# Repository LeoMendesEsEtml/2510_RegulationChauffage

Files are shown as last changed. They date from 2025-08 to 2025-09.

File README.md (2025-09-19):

# 2510_RegulationChauffage

## Description
Solution matérielle et logicielle basée sur Raspberry Pi Compute Module 5 pour remplacer un automate de chaudière.  
Le système lit des sondes réelles, calcule une température « simulée » à partir des prévisions météo, et applique une résistance équivalente à la chaudière via un réseau de résistances commandé. Connexion à l'API Oblo en HTTP (GET/POST) et publication des **mesures** & de l'**état** vers un Cloud, conformément au CdC.

**Documentation complète disponible sur : [leomendesesetml.github.io/2510_RegulationChauffage.github.io](https://leomendesesetml.github.io/2510_RegulationChauffage.github.io/index.html)**

## Diagrammes (UML / Architecture / Flux)
| Architecture réelle | Architecture générique |
|---|---|
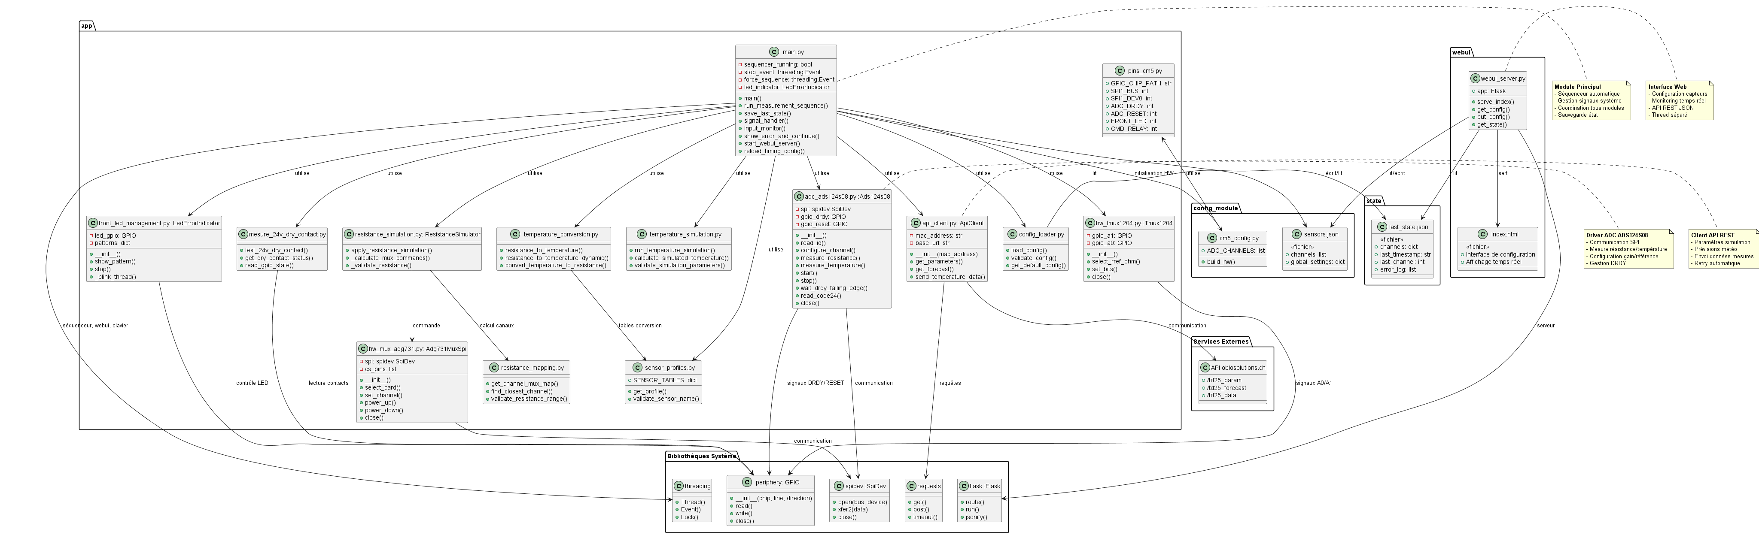
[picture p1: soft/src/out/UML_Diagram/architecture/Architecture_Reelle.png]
Architecture réelle
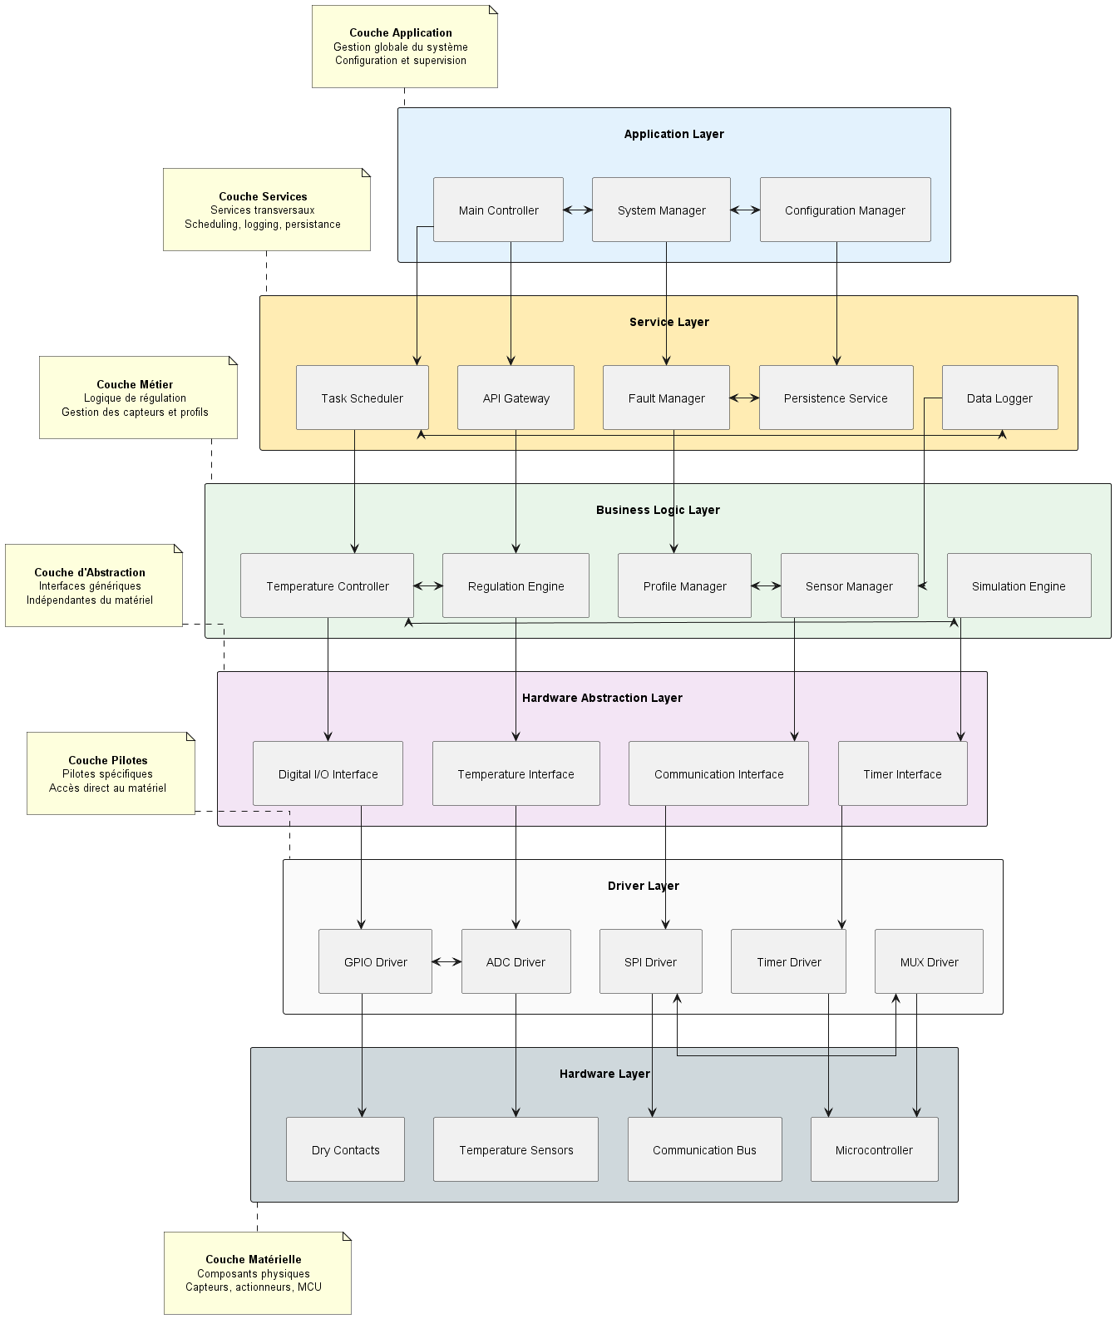
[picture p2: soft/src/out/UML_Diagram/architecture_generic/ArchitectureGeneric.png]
Architecture générique
|  |  |

| Flux d’événements détaillé | Flux d’événements générique |
|---|---|
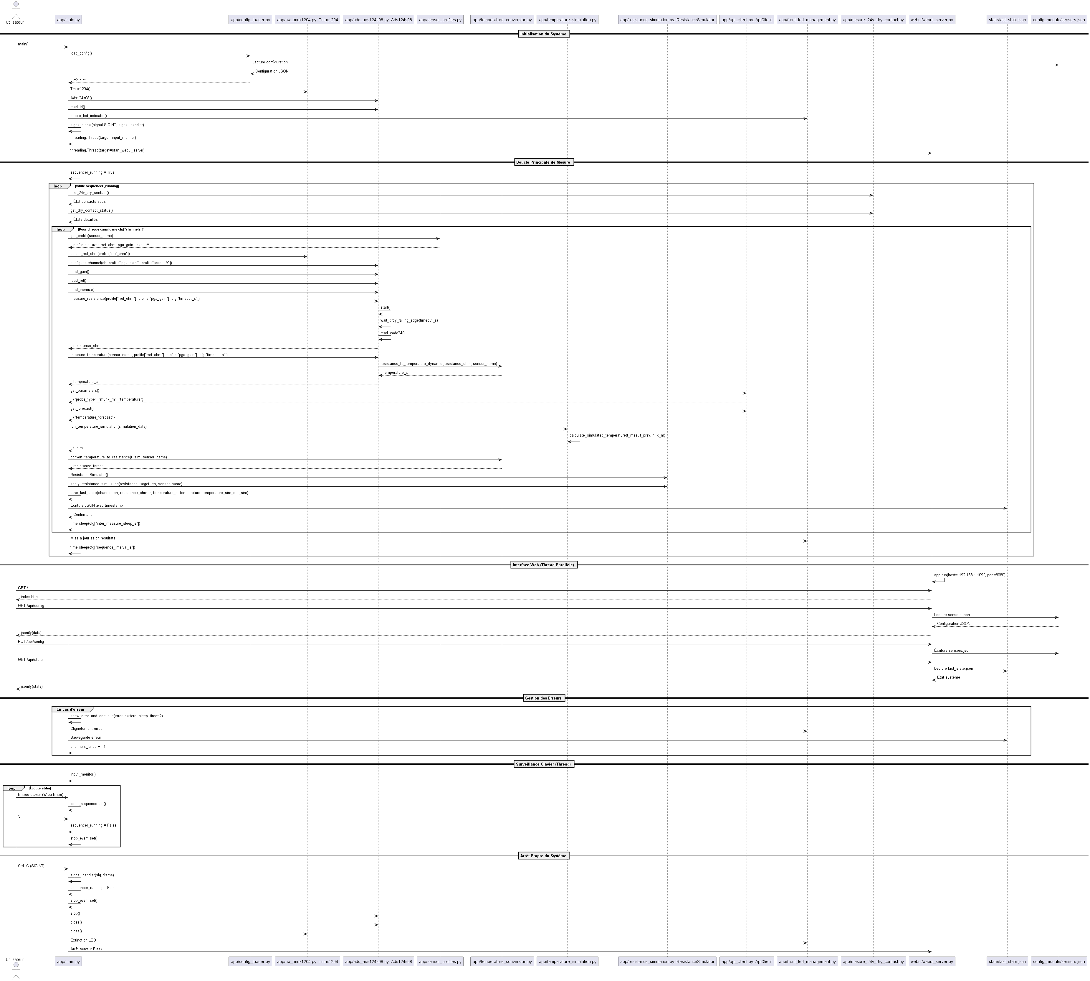
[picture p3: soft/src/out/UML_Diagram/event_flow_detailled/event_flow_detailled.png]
Flux d’événements détaillé
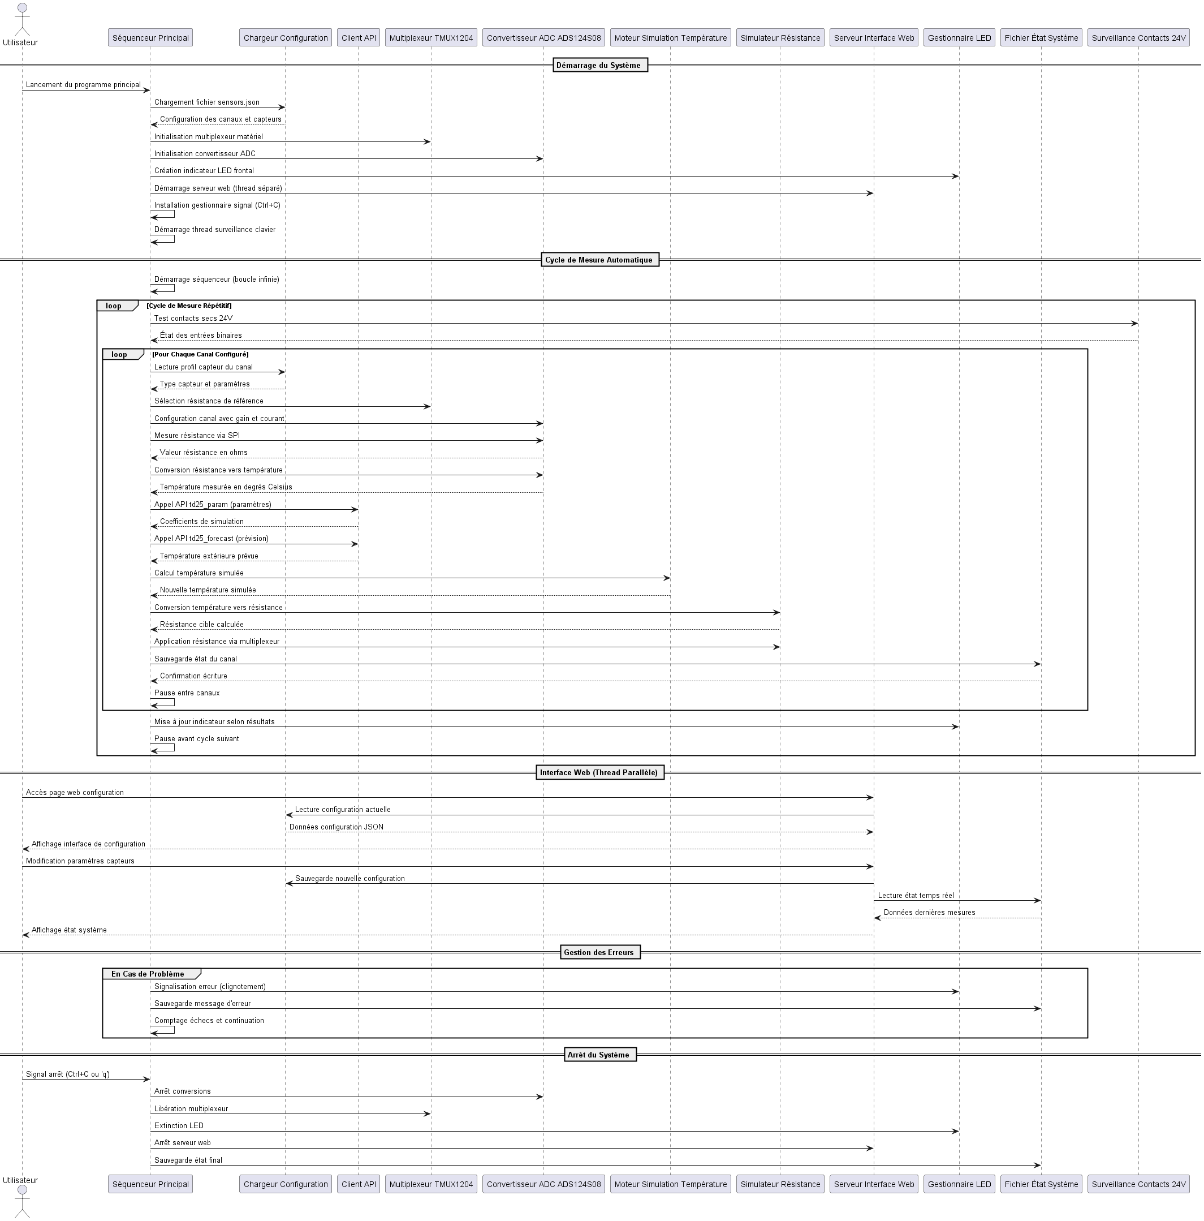
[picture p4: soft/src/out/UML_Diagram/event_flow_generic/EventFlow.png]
Flux d’événements générique
|  |  |

## Fonctionnalités (réf. CdC v02)
- Récupération des paramètres et prévisions via **API HTTP** (Oblo, GET/POST).
- Lecture d'une sonde de température extérieure (capteur **résistif**), conversion en **°C**.
- Génération d'une **sonde simulée** via réseau de résistances (pilotage **ADG731**).
- **Publication** des mesures et de l'état de l'appareil vers le **Cloud**.
- Cadence périodique **5 minutes**, journalisation en **JSON lines**.
- Gestion de **1 à 4** canaux actifs, contact sec prioritaire, relais bypass et LED d'état.

## Architecture système

### Matériel principal
- **Compute Module 5 (CM5)** - Processeur principal
- **ADS124S08** - ADC delta-sigma, communication **SPI1**, signaux DRDY/START en GPIO
- **TMUX1204** - Multiplexeur sélection **Rref** (A0/A1)
- **ADG731** - Multiplexeur **SPI0** vers réseau de **résistances simulées**
- **Entrée contact sec**, **relais bypass**, **LED** frontale

### Logiciel principal
- **Python 3.11+** avec architecture modulaire
- **spidev**, **periphery** (SPI/GPIO), **requests** (HTTP), **flask** (WebUI)
- Interface web intégrée pour configuration et monitoring
- Service **systemd** et logs JSON rotatifs
- Simulation et validation complète des mesures

## Commandes principales

### Lancement manuel
```bash
# Mode automatique avec cycles 5 minutes
python3 /home/oblo/proj/2510_RegulationChauffage_soft/soft/src/app/main.py

# Mode manuel avec interface web
python3 /home/oblo/proj/2510_RegulationChauffage_soft/soft/src/app/main.py --webui

# Mode manuel sans cycles automatiques
python3 /home/oblo/proj/2510_RegulationChauffage_soft/soft/src/app/main.py --manual

# Exécution unique (test)
python3 /home/oblo/proj/2510_RegulationChauffage_soft/soft/src/app/main.py --once
```

### Service systemd (production)
```bash
# Créer le service avec interface web
sudo tee /etc/systemd/system/2510-regulation.service > /dev/null << 'EOF'
[Unit]
Description=2510 Regulation Chauffage Service with WebUI
After=network.target
Wants=network.target

[Service]
Type=simple
User=oblo
Group=oblo
WorkingDirectory=/home/oblo/proj/2510_RegulationChauffage_soft/soft/src
ExecStart=/usr/bin/python3 /home/oblo/proj/2510_RegulationChauffage_soft/soft/src/app/main.py --webui
Restart=always
RestartSec=10
StandardOutput=journal
StandardError=journal
Environment=PYTHONPATH=/home/oblo/proj/2510_RegulationChauffage_soft/soft/src
Environment=HOME=/home/oblo

[Install]
WantedBy=multi-user.target
EOF

# Activer et démarrer le service
sudo systemctl daemon-reload
sudo systemctl enable 2510-regulation
sudo systemctl start 2510-regulation
```

### Contrôle du service
```bash
# Vérifier le statut du service
sudo systemctl status 2510-regulation

# Vérifier si le service est actif
sudo systemctl is-active 2510-regulation

# Arrêter le service
sudo systemctl stop 2510-regulation

# Redémarrer le service
sudo systemctl restart 2510-regulation

# Voir les logs en temps réel
sudo journalctl -u 2510-regulation -f

# Voir les derniers logs
sudo journalctl -u 2510-regulation -n 50
```

### Monitoring et diagnostic
```bash
# Vérifier le processus Python
ps aux | grep main.py

# Vérifier l'interface web (port 8080)
curl -s http://localhost:8080 > /dev/null && echo "Interface web active" || echo "Interface web inaccessible"

# Vérifier les ports d'écoute
sudo ss -tlnp | grep 8080

# Status complet en une commande
echo "Service:" && sudo systemctl is-active 2510-regulation && echo "Process:" && ps aux | grep -v grep | grep main.py && echo "Port 8080:" && sudo ss -tlnp | grep 8080
```

## Installation et déploiement

### Installation système
```bash
# Dépendances système
sudo apt update
sudo apt install python3-pip python3-venv

# Dépendances Python
pip3 install spidev periphery requests flask

# Configuration SPI
sudo raspi-config  # Activer SPI0 et SPI1
```

### Accès interface web
- **URL locale** : `http://192.168.1.109:8080`
- **Configuration** : Types capteurs, timeouts, intervalles
- **Monitoring** : Données temps réel, historique des mesures
- **API REST** : `/api/config`, `/api/state`

## Flux opératoire (cycle 5 min)

### Séquence de mesure
1. **Contacts secs** - Lecture état prioritaire via mesure_24v_dry_contact.py
2. **Pour chaque canal actif (1-4)** :
   - Sélection **Rref** via TMUX1204
   - Configuration **ADC** via ADS124S08
   - **Mesure single-shot** → code 24 bits → **Tmes**
   - Conversion résistance/température

### Simulation et application
3. **API Oblo** - Récupération paramètres (**N, kM, Tprevu**)
4. **Calcul Tsim** - Formule prédictive temperature_simulation.py
5. **Application MUX** - Résistance simulée via ADG731
6. **Sauvegarde** - État système dans last_state.json

### Gestion d'erreurs
- **LED frontale** - Patterns d'erreur (1Hz normal, 2Hz faute)
- **Relais bypass** - Sécurité en cas de défaut
- **Logs JSON** - Traçabilité complète des événements

## Types de capteurs supportés
- **De Dietrich AF60**, **Siemens QAC32**
- **PT1000**, **Ni1000 TK5000/TK6180**
- **NTC 1k/2k/2.2k/10k** (diverses courbes)
- **KTY81-210**

## API et connectivité

### API oblosolutions.ch
- **Endpoint paramètres** : `GET /td25_param?mac_address=XXX`
- **Endpoint prévisions** : `GET /td25_forecast?mac_address=XXX`
- **Envoi mesures** : `POST /td25_param` avec données température

### Données JSON échangées
```json
{
  "probe_type": "Ni1000 TK5000",
  "n": 0.8,
  "k_m": -0.1,
  "temperature": 18.5,
  "forecast_temperature": 15.2,
  "timestamp": "2025-09-18T14:30:00Z"
}
```

### Configuration réseau
- **Interface** : eth0 (192.168.1.109)
- **Port web** : 8080
- **Timeout API** : 10 secondes
- **Retry** : 3 tentatives

## Mappage matériel CM5

### Configuration SPI
- **SPI0** → **ADG731** (réseau résistif) : SCLK, MOSI, CS[0..3]
- **SPI1** → **ADS124S08** (métrologie) : SCLK, MOSI, MISO, CS

### Table GPIO principale
| Signal | GPIO | Fonction | Description |
|---|:----:|---|---|
| **MUX CS 1-4** | 2,3,7,8 | Sélection carte ADG731 | Adressage résistances |
| **MUX MOSI/SCLK** | 10,11 | Communication SPI0 | Commande multiplexeur |
| **CM 24V OUT/SENSE** | 12-15 | Contacts secs | Entrées prioritaires |
| **ADC SPI1** | 17-20 | Communication ADC | Mesures température |
| **ADC DRDY/START** | 21,22 | Signaux contrôle ADC | Synchronisation mesures |
| **ADC A0/A1** | 23,24 | Sélection canal/Rref | Multiplexage entrées |
| **FRONT LED** | 26 | Indicateur état | Status visuel système |
| **CMD RELAY** | 16 | Relais bypass | Sécurité défaillance |

## Fichiers de configuration et état

### Fichiers système
```bash
# Configuration capteurs
/home/oblo/proj/2510_RegulationChauffage_soft/soft/src/config_module/sensors.json

# État système (dernières mesures)
/home/oblo/proj/2510_RegulationChauffage_soft/soft/src/state/last_state.json

# Logs système
sudo journalctl -u 2510-regulation

# Configuration service
/etc/systemd/system/2510-regulation.service
```

### Monitoring système
#### Patterns d'erreur : X clignotements sur 10 secondes puis répétition
- 1 clignotement = Pas de connexion Internet
- 2 clignotements = Erreur API (connexion ou réponse)
- 3 clignotements = Erreur de mesure ADC/résistance
- 4 clignotements = Erreur critique système
- 5 clignotements = Erreur de configuration
#### Interface web :
- Dashboard temps réel à `http://192.168.1.109:8080`

## Validation et diagnostics
### Troubleshooting
```bash
# Vérifier SPI activé
ls /dev/spi*

# Vérifier permissions GPIO
groups oblo

# Redémarrer service en cas de problème
sudo systemctl restart 2510-regulation

# Logs détaillés
sudo journalctl -u 2510-regulation --since "1 hour ago"
```

---

## Références et documentation

- **Documentation technique complète** : [leomendesesetml.github.io/2510_RegulationChauffage.github.io](https://leomendesesetml.github.io/2510_RegulationChauffage.github.io/index.html)
- **Cahier des charges** : Exigences fonctionnelles et techniques
- **Schémas électroniques** : Plans de câblage et BOM
- **API Documentation** : Spécifications oblosolutions.ch
- **Code source** : Modules Python avec documentation inline

## Informations projet

**Auteur** : Léo Mendes - ETML ES  
**Projet** : 2510_RegulationsChauffage  
**Mandant** : Oblo Solutions  
**Version** : 1.0.0  
**Chemin système** : `/home/oblo/proj/2510_RegulationChauffage_soft/soft/src/`  
**Copyright** : 2025

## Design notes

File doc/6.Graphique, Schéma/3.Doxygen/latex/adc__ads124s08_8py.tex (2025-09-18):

\doxysection{Référence du fichier C\+:/\+Users/thebi/\+Documents/2510\+\_\+\+Regulation\+Chauffage/doc/9.Soft\+Ware/\+Doxygen/src/app/adc\+\_\+ads124s08.py}
\hypertarget{adc__ads124s08_8py}{}\label{adc__ads124s08_8py}\index{C:/Users/thebi/Documents/2510\_RegulationChauffage/doc/9.SoftWare/Doxygen/src/app/adc\_ads124s08.py@{C:/Users/thebi/Documents/2510\_RegulationChauffage/doc/9.SoftWare/Doxygen/src/app/adc\_ads124s08.py}}

Driver pour l\textquotesingle{}ADC ADS124\+S08 avec communication SPI.  

\doxysubsubsection*{Classes}
\begin{DoxyCompactItemize}
\item 
class \mbox{\hyperlink{classapp_1_1adc__ads124s08_1_1_ads124s08}{app.\+adc\+\_\+ads124s08.\+Ads124s08}}
\begin{DoxyCompactList}\small\item\em Driver pour l\textquotesingle{}ADC ADS124\+S08 avec interface SPI. \end{DoxyCompactList}\end{DoxyCompactItemize}
\doxysubsubsection*{Espaces de nommage}
\begin{DoxyCompactItemize}
\item 
namespace \mbox{\hyperlink{namespaceapp}{app}}
\item 
namespace \mbox{\hyperlink{namespaceapp_1_1adc__ads124s08}{app.\+adc\+\_\+ads124s08}}
\end{DoxyCompactItemize}
\doxysubsubsection*{Fonctions}
\begin{DoxyCompactItemize}
\item 
\mbox{\hyperlink{namespaceapp_1_1adc__ads124s08_a0117399a18d516c747ca6b060599452f}{app.\+adc\+\_\+ads124s08.\+encode\+\_\+gain}} (pga\+\_\+gain)
\begin{DoxyCompactList}\small\item\em Encode le gain PGA en code binaire pour le registre. \end{DoxyCompactList}\item 
\mbox{\hyperlink{namespaceapp_1_1adc__ads124s08_a8f9279b8505f8d634ed73c51dcab29c9}{app.\+adc\+\_\+ads124s08.\+encode\+\_\+idac\+\_\+uA}} (idac\+\_\+uA)
\begin{DoxyCompactList}\small\item\em Encode la magnitude IDAC en code binaire pour le registre. \end{DoxyCompactList}\item 
\mbox{\hyperlink{namespaceapp_1_1adc__ads124s08_a2d49f7c13e0b47db65080ab59febed76}{app.\+adc\+\_\+ads124s08.\+sign\+\_\+extend\+\_\+24}} (b0, b1, b2)
\begin{DoxyCompactList}\small\item\em Étend le signe d\textquotesingle{}un code ADC 24 bits vers 32 bits. \end{DoxyCompactList}\end{DoxyCompactItemize}
\doxysubsubsection*{Variables}
\begin{DoxyCompactItemize}
\item 
int \mbox{\hyperlink{namespaceapp_1_1adc__ads124s08_a95d2ed0295f793db669188acfc42e035}{app.\+adc\+\_\+ads124s08.\+REG\+\_\+\+ID}} = 0x00
\item 
int \mbox{\hyperlink{namespaceapp_1_1adc__ads124s08_a08370a57876abbb36233f903990f7090}{app.\+adc\+\_\+ads124s08.\+REG\+\_\+\+STATUS}} = 0x01
\item 
int \mbox{\hyperlink{namespaceapp_1_1adc__ads124s08_acc5fdb3a177b32ce008beb7d4f593e5a}{app.\+adc\+\_\+ads124s08.\+REG\+\_\+\+INPMUX}} = 0x02
\item 
int \mbox{\hyperlink{namespaceapp_1_1adc__ads124s08_a6693b8b3c92c4e605cd93396bbf437e4}{app.\+adc\+\_\+ads124s08.\+REG\+\_\+\+PGA}} = 0x03
\item 
int \mbox{\hyperlink{namespaceapp_1_1adc__ads124s08_a3570ad44d2f9dd31da3eb36e6bb43a74}{app.\+adc\+\_\+ads124s08.\+REG\+\_\+\+DATARATE}} = 0x04
\item 
int \mbox{\hyperlink{namespaceapp_1_1adc__ads124s08_a37082f74d6a0e13791161957521dda36}{app.\+adc\+\_\+ads124s08.\+REG\+\_\+\+REF}} = 0x05
\item 
int \mbox{\hyperlink{namespaceapp_1_1adc__ads124s08_ad6a2ed950510eefbb3d8e16c5d44aa9a}{app.\+adc\+\_\+ads124s08.\+REG\+\_\+\+IDACMUX}} = 0x07
\item 
int \mbox{\hyperlink{namespaceapp_1_1adc__ads124s08_ab33f3d3b9eff07796c0954fb0a26a0f9}{app.\+adc\+\_\+ads124s08.\+REG\+\_\+\+SYS}} = 0x09
\item 
int \mbox{\hyperlink{namespaceapp_1_1adc__ads124s08_a29344761380eb9759a168a517077c1f8}{app.\+adc\+\_\+ads124s08.\+REG\+\_\+\+IDACMAG}} = 0x06
\item 
int \mbox{\hyperlink{namespaceapp_1_1adc__ads124s08_ac53df39aab8783f89db1de629453dac2}{app.\+adc\+\_\+ads124s08.\+CMD\+\_\+\+RESET}} = 0x06
\item 
int \mbox{\hyperlink{namespaceapp_1_1adc__ads124s08_afdbb53f6073883d5fae13b41f4054ad2}{app.\+adc\+\_\+ads124s08.\+CMD\+\_\+\+START}} = 0x08
\item 
int \mbox{\hyperlink{namespaceapp_1_1adc__ads124s08_a584dd419d6c692fe7fdbf9c318b0e9da}{app.\+adc\+\_\+ads124s08.\+CMD\+\_\+\+STOP}} = 0x0A
\item 
int \mbox{\hyperlink{namespaceapp_1_1adc__ads124s08_a295dbc291719574e76ddc5a7a2467087}{app.\+adc\+\_\+ads124s08.\+CMD\+\_\+\+RDATA}} = 0x12
\item 
tuple \mbox{\hyperlink{namespaceapp_1_1adc__ads124s08_a9d806c5f058f08f8ee7e226d706694f1}{app.\+adc\+\_\+ads124s08.\+FS}} = (1 $<$$<$ 23) -\/ 1
\item 
dict \mbox{\hyperlink{namespaceapp_1_1adc__ads124s08_a8919c033b020e8f54f713cea9d68fa22}{app.\+adc\+\_\+ads124s08.\+CHANNELS}}
\end{DoxyCompactItemize}

\doxysubsection{Description détaillée}
Driver pour l\textquotesingle{}ADC ADS124\+S08 avec communication SPI. 

Ce module fournit une interface complète pour la communication avec l\textquotesingle{}ADC ADS124\+S08 via SPI en mode 1.\+0. Supporte la mesure de résistance et température avec configuration automatique des registres. S� Reset → Configuration → Mesure bloquante avec DRDY. \begin{DoxyAuthor}{Auteur}
Léo Mendes @project 2510\+\_\+\+Regulations\+Chauffage @\+Mandant Oblo\+\_\+solution 
\end{DoxyAuthor}
\begin{DoxyDate}{Date}
2025-\/09-\/18 
\end{DoxyDate}
\begin{DoxyVersion}{Version}
1.\+0.\+0 
\end{DoxyVersion}
\begin{DoxyCopyright}{Copyright}
Copyright (c) 2025 
\end{DoxyCopyright}

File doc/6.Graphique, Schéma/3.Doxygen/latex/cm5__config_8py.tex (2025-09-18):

\doxysection{Référence du fichier C\+:/\+Users/thebi/\+Documents/2510\+\_\+\+Regulation\+Chauffage/doc/9.Soft\+Ware/\+Doxygen/src/config\+\_\+module/cm5\+\_\+config.py}
\hypertarget{cm5__config_8py}{}\label{cm5__config_8py}\index{C:/Users/thebi/Documents/2510\_RegulationChauffage/doc/9.SoftWare/Doxygen/src/config\_module/cm5\_config.py@{C:/Users/thebi/Documents/2510\_RegulationChauffage/doc/9.SoftWare/Doxygen/src/config\_module/cm5\_config.py}}

Configuration matérielle pour plateforme CM5.  

\doxysubsubsection*{Espaces de nommage}
\begin{DoxyCompactItemize}
\item 
namespace \mbox{\hyperlink{namespaceconfig__module}{config\+\_\+module}}
\item 
namespace \mbox{\hyperlink{namespaceconfig__module_1_1cm5__config}{config\+\_\+module.\+cm5\+\_\+config}}
\end{DoxyCompactItemize}
\doxysubsubsection*{Fonctions}
\begin{DoxyCompactItemize}
\item 
\mbox{\hyperlink{namespaceconfig__module_1_1cm5__config_a1b2cec317a1cf375b2d43c263f5a665b}{config\+\_\+module.\+cm5\+\_\+config.\+build\+\_\+hw}} ()
\begin{DoxyCompactList}\small\item\em Initialise et configure tout le matériel CM5. \end{DoxyCompactList}\end{DoxyCompactItemize}
\doxysubsubsection*{Variables}
\begin{DoxyCompactItemize}
\item 
list \mbox{\hyperlink{namespaceconfig__module_1_1cm5__config_a98f07cbc7aad810cb848630cde11db65}{config\+\_\+module.\+cm5\+\_\+config.\+ADC\+\_\+\+CHANNELS}} = \mbox{[}1, 2, 3, 4\mbox{]}
\end{DoxyCompactItemize}

\doxysubsection{Description détaillée}
Configuration matérielle pour plateforme CM5. 

Ce module fournit la configuration des canaux ADC et la fonction d\textquotesingle{}initialisation complète du matériel (LED, TMUX, ADC). Centralise la création des instances matérielles avec câblage fixe CM5. \begin{DoxyAuthor}{Auteur}
Léo Mendes @project 2510\+\_\+\+Regulations\+Chauffage @\+Mandant Oblo\+\_\+solution 
\end{DoxyAuthor}
\begin{DoxyDate}{Date}
2025-\/09-\/18 
\end{DoxyDate}
\begin{DoxyVersion}{Version}
1.\+0.\+0 
\end{DoxyVersion}
\begin{DoxyCopyright}{Copyright}
Copyright (c) 2025 
\end{DoxyCopyright}

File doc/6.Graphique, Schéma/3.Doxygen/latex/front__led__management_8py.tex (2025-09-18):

\doxysection{Référence du fichier C\+:/\+Users/thebi/\+Documents/2510\+\_\+\+Regulation\+Chauffage/doc/9.Soft\+Ware/\+Doxygen/src/app/front\+\_\+led\+\_\+management.py}
\hypertarget{front__led__management_8py}{}\label{front__led__management_8py}\index{C:/Users/thebi/Documents/2510\_RegulationChauffage/doc/9.SoftWare/Doxygen/src/app/front\_led\_management.py@{C:/Users/thebi/Documents/2510\_RegulationChauffage/doc/9.SoftWare/Doxygen/src/app/front\_led\_management.py}}

Gestionnaire de LED frontale avec patterns d\textquotesingle{}erreur.  

\doxysubsubsection*{Classes}
\begin{DoxyCompactItemize}
\item 
class \mbox{\hyperlink{classapp_1_1front__led__management_1_1_led_error_indicator}{app.\+front\+\_\+led\+\_\+management.\+Led\+Error\+Indicator}}
\begin{DoxyCompactList}\small\item\em Gestionnaire de LED avec patterns d\textquotesingle{}erreur. \end{DoxyCompactList}\end{DoxyCompactItemize}
\doxysubsubsection*{Espaces de nommage}
\begin{DoxyCompactItemize}
\item 
namespace \mbox{\hyperlink{namespaceapp}{app}}
\item 
namespace \mbox{\hyperlink{namespaceapp_1_1front__led__management}{app.\+front\+\_\+led\+\_\+management}}
\end{DoxyCompactItemize}
\doxysubsubsection*{Fonctions}
\begin{DoxyCompactItemize}
\item 
\mbox{\hyperlink{namespaceapp_1_1front__led__management_ab7831833c4fa77c5bcc4a03235168b64}{app.\+front\+\_\+led\+\_\+management.\+create\+\_\+led\+\_\+indicator}} (gpio\+\_\+chip\+\_\+path, led\+\_\+pin)
\begin{DoxyCompactList}\small\item\em Factory function pour créer une instance \doxylink{classapp_1_1front__led__management_1_1_led_error_indicator}{Led\+Error\+Indicator}. \end{DoxyCompactList}\end{DoxyCompactItemize}

\doxysubsection{Description détaillée}
Gestionnaire de LED frontale avec patterns d\textquotesingle{}erreur. 

Ce module fournit une classe pour gérer les clignotements et états de la LED frontale avec différents patterns d\textquotesingle{}erreur. Supporte les modes continus, les clignotements d\textquotesingle{}erreur et la gestion thread-\/safe des patterns LED. \begin{DoxyAuthor}{Auteur}
Léo Mendes @project 2510\+\_\+\+Regulations\+Chauffage @\+Mandant Oblo\+\_\+solution 
\end{DoxyAuthor}
\begin{DoxyDate}{Date}
2025-\/09-\/18 
\end{DoxyDate}
\begin{DoxyVersion}{Version}
1.\+0.\+0 
\end{DoxyVersion}
\begin{DoxyCopyright}{Copyright}
Copyright (c) 2025 
\end{DoxyCopyright}

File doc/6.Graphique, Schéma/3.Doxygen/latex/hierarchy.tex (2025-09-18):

\doxysection{Hiérarchie des classes}
Cette liste d\textquotesingle{}héritage est classée approximativement par ordre alphabétique \+:\begin{DoxyCompactList}
\item \contentsline{section}{app.\+hw\+\_\+mux\+\_\+adg731.\+Adg731\+Mux\+Spi}{\pageref{classapp_1_1hw__mux__adg731_1_1_adg731_mux_spi}}{}
\item \contentsline{section}{app.\+adc\+\_\+ads124s08.\+Ads124s08}{\pageref{classapp_1_1adc__ads124s08_1_1_ads124s08}}{}
\item \contentsline{section}{app.\+api\+\_\+client.\+Api\+Client}{\pageref{classapp_1_1api__client_1_1_api_client}}{}
\item Exception\begin{DoxyCompactList}
\item \contentsline{section}{app.\+api\+\_\+client.\+Api\+Error}{\pageref{classapp_1_1api__client_1_1_api_error}}{}
\item \contentsline{section}{app.\+resistance\+\_\+simulation.\+Resistance\+Simulation\+Error}{\pageref{classapp_1_1resistance__simulation_1_1_resistance_simulation_error}}{}
\end{DoxyCompactList}
\item \contentsline{section}{app.\+front\+\_\+led\+\_\+management.\+Led\+Error\+Indicator}{\pageref{classapp_1_1front__led__management_1_1_led_error_indicator}}{}
\item \contentsline{section}{app.\+resistance\+\_\+simulation.\+Resistance\+Simulator}{\pageref{classapp_1_1resistance__simulation_1_1_resistance_simulator}}{}
\item \contentsline{section}{app.\+hw\+\_\+tmux1204.\+Tmux1204}{\pageref{classapp_1_1hw__tmux1204_1_1_tmux1204}}{}
\end{DoxyCompactList}

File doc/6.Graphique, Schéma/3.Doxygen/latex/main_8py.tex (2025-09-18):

\doxysection{Référence du fichier C\+:/\+Users/thebi/\+Documents/2510\+\_\+\+Regulation\+Chauffage/doc/9.Soft\+Ware/\+Doxygen/src/app/main.py}
\hypertarget{main_8py}{}\label{main_8py}\index{C:/Users/thebi/Documents/2510\_RegulationChauffage/doc/9.SoftWare/Doxygen/src/app/main.py@{C:/Users/thebi/Documents/2510\_RegulationChauffage/doc/9.SoftWare/Doxygen/src/app/main.py}}

Système de mesure et simulation de température.  

\doxysubsubsection*{Espaces de nommage}
\begin{DoxyCompactItemize}
\item 
namespace \mbox{\hyperlink{namespaceapp}{app}}
\item 
namespace \mbox{\hyperlink{namespaceapp_1_1main}{app.\+main}}
\end{DoxyCompactItemize}
\doxysubsubsection*{Fonctions}
\begin{DoxyCompactItemize}
\item 
\mbox{\hyperlink{namespaceapp_1_1main_ad21574e7873c2ce3e62f3b74e9a10f6a}{app.\+main.\+start\+\_\+webui\+\_\+server}} ()
\begin{DoxyCompactList}\small\item\em Lance le serveur web local dans un thread séparé. \end{DoxyCompactList}\item 
\mbox{\hyperlink{namespaceapp_1_1main_a7e7d269529399106243cc74fc3c73b6a}{app.\+main.\+save\+\_\+last\+\_\+state}} (channel=None, resistance\+\_\+ohm=None, temperature\+\_\+c=None, temperature\+\_\+sim\+\_\+c=None, error=None)
\begin{DoxyCompactList}\small\item\em Sauvegarde l\textquotesingle{}état courant et historique par canal dans un fichier JSON. \end{DoxyCompactList}\item 
\mbox{\hyperlink{namespaceapp_1_1main_abe819be4d1d22ae06c4753392322a35b}{app.\+main.\+signal\+\_\+handler}} (sig, frame)
\begin{DoxyCompactList}\small\item\em Gestionnaire POSIX pour les signaux (Ctrl+C). \end{DoxyCompactList}\item 
\mbox{\hyperlink{namespaceapp_1_1main_ab98791c04a040ea7d728c8cda86d0677}{app.\+main.\+input\+\_\+monitor}} ()
\begin{DoxyCompactList}\small\item\em Thread d\textquotesingle{}écoute des commandes utilisateur depuis stdin. \end{DoxyCompactList}\item 
\mbox{\hyperlink{namespaceapp_1_1main_a1b3211e7ab2da62ed461ce881f0ce556}{app.\+main.\+show\+\_\+error\+\_\+and\+\_\+continue}} (error\+\_\+pattern, sleep\+\_\+time=2)
\begin{DoxyCompactList}\small\item\em Affiche un motif LED d\textquotesingle{}erreur pendant un temps donné puis remet l\textquotesingle{}indicateur en mode \textquotesingle{}sequence\+\_\+running\textquotesingle{}. \end{DoxyCompactList}\item 
\mbox{\hyperlink{namespaceapp_1_1main_abde8d10de044e070eb5eab1e448cd558}{app.\+main.\+run\+\_\+measurement\+\_\+sequence}} (cfg, mac\+\_\+address, adc, tmux)
\begin{DoxyCompactList}\small\item\em Exécute une séquence complète de mesures pour tous les canaux activés selon la configuration fournie. \end{DoxyCompactList}\item 
\mbox{\hyperlink{namespaceapp_1_1main_a2d15309f12a3472b94e8cace0ace5a6b}{app.\+main.\+reload\+\_\+timing\+\_\+config}} ()
\begin{DoxyCompactList}\small\item\em Recharge les paramètres de temporisation depuis le fichier de configuration. \end{DoxyCompactList}\item 
\mbox{\hyperlink{namespaceapp_1_1main_a3e4dda2887e910e984519bea9a420dc2}{app.\+main.\+main}} ()
\begin{DoxyCompactList}\small\item\em Point d\textquotesingle{}entrée principal du programme. \end{DoxyCompactList}\end{DoxyCompactItemize}
\doxysubsubsection*{Variables}
\begin{DoxyCompactItemize}
\item 
\mbox{\hyperlink{namespaceapp_1_1main_aff7cd4e0e9d7b9068e94858a4c527314}{app.\+main.\+CURRENT\+\_\+\+DIR}} = os.\+path.\+dirname(os.\+path.\+abspath(\+\_\+\+\_\+file\+\_\+\+\_\+))
\item 
\mbox{\hyperlink{namespaceapp_1_1main_ad64332bd025eb979f3c8b5aa2267bfd3}{app.\+main.\+SRC\+\_\+\+DIR}} = os.\+path.\+dirname(\mbox{\hyperlink{namespaceapp_1_1main_aff7cd4e0e9d7b9068e94858a4c527314}{CURRENT\+\_\+\+DIR}})
\item 
bool \mbox{\hyperlink{namespaceapp_1_1main_a4a86ee89abd84627e36c0320969924ac}{app.\+main.\+sequencer\+\_\+running}} = False
\item 
\mbox{\hyperlink{namespaceapp_1_1main_a35b15b3661aab25e707f368b9d8999ec}{app.\+main.\+stop\+\_\+event}} = threading.\+Event()
\item 
\mbox{\hyperlink{namespaceapp_1_1main_adcd9b846c9a069d44dad6fb465d9840c}{app.\+main.\+force\+\_\+sequence}} = threading.\+Event()
\item 
\mbox{\hyperlink{namespaceapp_1_1main_a0d1f132bf1e682ae958346b489d89772}{app.\+main.\+led\+\_\+indicator}} = None
\end{DoxyCompactItemize}

\doxysubsection{Description détaillée}
Système de mesure et simulation de température. 

Ce module exécute des cycles de mesure ADC, convertit les valeurs en résistances puis en températures, récupère des paramètres via une API distante, calcule une température simulée, convertit cette température en résistance cible et applique la simulation via un multiplexeur matériel. Le module gère également un petit serveur web optionnel et un indicateur LED. \begin{DoxyAuthor}{Auteur}
Léo Mendes @project 2510\+\_\+\+Regulations\+Chauffage @\+Mandant Oblo\+\_\+solution 
\end{DoxyAuthor}
\begin{DoxyDate}{Date}
2025-\/09-\/18 
\end{DoxyDate}
\begin{DoxyVersion}{Version}
1.\+0.\+0 
\end{DoxyVersion}
\begin{DoxyCopyright}{Copyright}
Copyright (c) 2025 
\end{DoxyCopyright}

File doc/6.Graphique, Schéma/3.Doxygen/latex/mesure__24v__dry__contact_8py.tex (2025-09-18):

\doxysection{Référence du fichier C\+:/\+Users/thebi/\+Documents/2510\+\_\+\+Regulation\+Chauffage/doc/9.Soft\+Ware/\+Doxygen/src/app/mesure\+\_\+24v\+\_\+dry\+\_\+contact.py}
\hypertarget{mesure__24v__dry__contact_8py}{}\label{mesure__24v__dry__contact_8py}\index{C:/Users/thebi/Documents/2510\_RegulationChauffage/doc/9.SoftWare/Doxygen/src/app/mesure\_24v\_dry\_contact.py@{C:/Users/thebi/Documents/2510\_RegulationChauffage/doc/9.SoftWare/Doxygen/src/app/mesure\_24v\_dry\_contact.py}}

Module de test des entrées/sorties 24V pour contacts secs.  

\doxysubsubsection*{Espaces de nommage}
\begin{DoxyCompactItemize}
\item 
namespace \mbox{\hyperlink{namespaceapp}{app}}
\item 
namespace \mbox{\hyperlink{namespaceapp_1_1mesure__24v__dry__contact}{app.\+mesure\+\_\+24v\+\_\+dry\+\_\+contact}}
\end{DoxyCompactItemize}
\doxysubsubsection*{Fonctions}
\begin{DoxyCompactItemize}
\item 
\mbox{\hyperlink{namespaceapp_1_1mesure__24v__dry__contact_ab7cf8a3e7b655f7414576fdb402a58b6}{app.\+mesure\+\_\+24v\+\_\+dry\+\_\+contact.\+test\+\_\+24v\+\_\+dry\+\_\+contact}} ()
\begin{DoxyCompactList}\small\item\em Test des contacts secs I/O 24V. \end{DoxyCompactList}\item 
\mbox{\hyperlink{namespaceapp_1_1mesure__24v__dry__contact_a92312106402fd2af723b0eecd78addaf}{app.\+mesure\+\_\+24v\+\_\+dry\+\_\+contact.\+get\+\_\+dry\+\_\+contact\+\_\+status}} ()
\begin{DoxyCompactList}\small\item\em Retourne l\textquotesingle{}état actuel des contacts secs. \end{DoxyCompactList}\end{DoxyCompactItemize}
\doxysubsubsection*{Variables}
\begin{DoxyCompactItemize}
\item 
int \mbox{\hyperlink{namespaceapp_1_1mesure__24v__dry__contact_a453d71784bc90759879ed4710eddaae7}{app.\+mesure\+\_\+24v\+\_\+dry\+\_\+contact.\+CM\+\_\+24\+V\+\_\+\+OUT\+\_\+1}} = 13
\item 
int \mbox{\hyperlink{namespaceapp_1_1mesure__24v__dry__contact_af472e52ff88e296aea83c8cc79d5620c}{app.\+mesure\+\_\+24v\+\_\+dry\+\_\+contact.\+CM\+\_\+24\+V\+\_\+\+SENSE\+\_\+1}} = 14
\item 
int \mbox{\hyperlink{namespaceapp_1_1mesure__24v__dry__contact_a8b67517287b2c5e4ef8bfa43ae6b4729}{app.\+mesure\+\_\+24v\+\_\+dry\+\_\+contact.\+CM\+\_\+24\+V\+\_\+\+OUT\+\_\+2}} = 15
\item 
int \mbox{\hyperlink{namespaceapp_1_1mesure__24v__dry__contact_a04e3ff2fcb546df09d9f9395e419df3c}{app.\+mesure\+\_\+24v\+\_\+dry\+\_\+contact.\+CM\+\_\+24\+V\+\_\+\+SENSE\+\_\+2}} = 16
\item 
int \mbox{\hyperlink{namespaceapp_1_1mesure__24v__dry__contact_aa7723504bd319fbc27af31e9cb1f5ba9}{app.\+mesure\+\_\+24v\+\_\+dry\+\_\+contact.\+io\+\_\+24v\+\_\+ch1\+\_\+ok}} = 0
\item 
int \mbox{\hyperlink{namespaceapp_1_1mesure__24v__dry__contact_abcab5b3d8575048fb3ca52576a6a2e79}{app.\+mesure\+\_\+24v\+\_\+dry\+\_\+contact.\+io\+\_\+24v\+\_\+ch2\+\_\+ok}} = 0
\end{DoxyCompactItemize}

\doxysubsection{Description détaillée}
Module de test des entrées/sorties 24V pour contacts secs. 

Ce module fournit des fonctions pour tester et valider les contacts secs via les interfaces I/O 24V. Permet de détecter l\textquotesingle{}état des contacts (ouvert/fermé) sur deux canaux indépendants avec gestion des GPIO et temporisations appropriées. \begin{DoxyAuthor}{Auteur}
Léo Mendes @project 2510\+\_\+\+Regulations\+Chauffage @\+Mandant Oblo\+\_\+solution 
\end{DoxyAuthor}
\begin{DoxyDate}{Date}
2025-\/09-\/18 
\end{DoxyDate}
\begin{DoxyVersion}{Version}
1.\+0.\+0 
\end{DoxyVersion}
\begin{DoxyCopyright}{Copyright}
Copyright (c) 2025 
\end{DoxyCopyright}

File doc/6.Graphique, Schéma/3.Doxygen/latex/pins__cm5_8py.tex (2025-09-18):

\doxysection{Référence du fichier C\+:/\+Users/thebi/\+Documents/2510\+\_\+\+Regulation\+Chauffage/doc/9.Soft\+Ware/\+Doxygen/src/app/pins\+\_\+cm5.py}
\hypertarget{pins__cm5_8py}{}\label{pins__cm5_8py}\index{C:/Users/thebi/Documents/2510\_RegulationChauffage/doc/9.SoftWare/Doxygen/src/app/pins\_cm5.py@{C:/Users/thebi/Documents/2510\_RegulationChauffage/doc/9.SoftWare/Doxygen/src/app/pins\_cm5.py}}

Mapping GPIO et SPI fixés pour la plateforme CM5.  

\doxysubsubsection*{Espaces de nommage}
\begin{DoxyCompactItemize}
\item 
namespace \mbox{\hyperlink{namespaceapp}{app}}
\item 
namespace \mbox{\hyperlink{namespaceapp_1_1pins__cm5}{app.\+pins\+\_\+cm5}}
\end{DoxyCompactItemize}
\doxysubsubsection*{Variables}
\begin{DoxyCompactItemize}
\item 
str \mbox{\hyperlink{namespaceapp_1_1pins__cm5_af1d01246bc2bdb28706c1e6d311c32d7}{app.\+pins\+\_\+cm5.\+GPIO\+\_\+\+CHIP\+\_\+\+PATH}} = "{}/dev/gpiochip0"{}
\item 
int \mbox{\hyperlink{namespaceapp_1_1pins__cm5_a85d9ae6ac38c784a57f1df12d873df9e}{app.\+pins\+\_\+cm5.\+MUX\+\_\+\+CS\+\_\+4}} = 2
\item 
int \mbox{\hyperlink{namespaceapp_1_1pins__cm5_a7af5bb4ba1b5e7903ad67473b087be16}{app.\+pins\+\_\+cm5.\+MUX\+\_\+\+CS\+\_\+3}} = 3
\item 
int \mbox{\hyperlink{namespaceapp_1_1pins__cm5_a02d8b1f8ea18e8ca0406421ae100b750}{app.\+pins\+\_\+cm5.\+MUX\+\_\+\+CS\+\_\+2}} = 7
\item 
int \mbox{\hyperlink{namespaceapp_1_1pins__cm5_a2b4b1ad07cc66496e86d86a5528df32b}{app.\+pins\+\_\+cm5.\+MUX\+\_\+\+CS\+\_\+1}} = 8
\item 
int \mbox{\hyperlink{namespaceapp_1_1pins__cm5_a001569b7c2bfb9dfc01cffe61578eb27}{app.\+pins\+\_\+cm5.\+MUX\+\_\+\+MOSI\+\_\+\+DUMMY}} = 10
\item 
int \mbox{\hyperlink{namespaceapp_1_1pins__cm5_a695f8e334328d47113d763fba85ea9e3}{app.\+pins\+\_\+cm5.\+MUX\+\_\+\+SCLK\+\_\+\+DUMMY}} = 11
\item 
int \mbox{\hyperlink{namespaceapp_1_1pins__cm5_a35b6be61b6d4cb85e21aa59866f3d095}{app.\+pins\+\_\+cm5.\+CM\+\_\+24\+V\+\_\+\+OUT\+\_\+1}} = 13
\item 
int \mbox{\hyperlink{namespaceapp_1_1pins__cm5_a88fd865f03c9f246ac8d65e8d0afe92e}{app.\+pins\+\_\+cm5.\+CM\+\_\+24\+V\+\_\+\+SENSE\+\_\+1}} = 14
\item 
int \mbox{\hyperlink{namespaceapp_1_1pins__cm5_a30a0aa5102bb2df299b2e9dd3e454946}{app.\+pins\+\_\+cm5.\+CM\+\_\+24\+V\+\_\+\+OUT\+\_\+2}} = 15
\item 
int \mbox{\hyperlink{namespaceapp_1_1pins__cm5_aad243ac39af06d31f52bfbd28872f52c}{app.\+pins\+\_\+cm5.\+CM\+\_\+24\+V\+\_\+\+SENSE\+\_\+2}} = 16
\item 
int \mbox{\hyperlink{namespaceapp_1_1pins__cm5_a1f2a9f8ae72ada5c471dcabeda39ff94}{app.\+pins\+\_\+cm5.\+CMD\+\_\+\+RELAY}} = 17
\item 
int \mbox{\hyperlink{namespaceapp_1_1pins__cm5_a5c82ead3a09bf677b0540cb1f1b39ccb}{app.\+pins\+\_\+cm5.\+CS\+\_\+\+ADC\+\_\+\+DUMMY}} = 18
\item 
int \mbox{\hyperlink{namespaceapp_1_1pins__cm5_a341e8e8f73df01d2f780f0ba22bef655}{app.\+pins\+\_\+cm5.\+SPI\+\_\+\+MISO\+\_\+\+ADC\+\_\+\+DMY}} = 19
\item 
int \mbox{\hyperlink{namespaceapp_1_1pins__cm5_abdef5fa06d0df26fb2b1529ae78106b8}{app.\+pins\+\_\+cm5.\+SPI\+\_\+\+MOSI\+\_\+\+ADC\+\_\+\+DMY}} = 20
\item 
int \mbox{\hyperlink{namespaceapp_1_1pins__cm5_a72500e21b93a5b8bf357a4d084d33f88}{app.\+pins\+\_\+cm5.\+SPI\+\_\+\+SCLK\+\_\+\+ADC\+\_\+\+DMY}} = 21
\item 
int \mbox{\hyperlink{namespaceapp_1_1pins__cm5_ab783ddc68bb5deccff5c4afeebf0f059}{app.\+pins\+\_\+cm5.\+ADC\+\_\+\+DRDY}} = 22
\item 
int \mbox{\hyperlink{namespaceapp_1_1pins__cm5_ada8a810372334f4c3d45a61f3e3dfff9}{app.\+pins\+\_\+cm5.\+ADC\+\_\+\+START\+\_\+\+SYNC}} = 23
\item 
int \mbox{\hyperlink{namespaceapp_1_1pins__cm5_a2beb922666cc8aeea223f68a702a1b19}{app.\+pins\+\_\+cm5.\+ADC\+\_\+\+A0}} = 24
\item 
int \mbox{\hyperlink{namespaceapp_1_1pins__cm5_aa41ecf65d54d7560c0a05b549a722afd}{app.\+pins\+\_\+cm5.\+ADC\+\_\+\+A1}} = 25
\item 
int \mbox{\hyperlink{namespaceapp_1_1pins__cm5_adc501cb01eb22c26240fd22e5e572a93}{app.\+pins\+\_\+cm5.\+FRONT\+\_\+\+LED}} = 27
\item 
int \mbox{\hyperlink{namespaceapp_1_1pins__cm5_a7f7f52f96aacfc3b968d398382178036}{app.\+pins\+\_\+cm5.\+SPI0\+\_\+\+BUS}} = 0
\item 
int \mbox{\hyperlink{namespaceapp_1_1pins__cm5_ac3f90aa5494bfd7cb328ab859270ba34}{app.\+pins\+\_\+cm5.\+SPI1\+\_\+\+BUS}} = 1
\item 
int \mbox{\hyperlink{namespaceapp_1_1pins__cm5_a368d5549c798e09e8775e0e73b96d14c}{app.\+pins\+\_\+cm5.\+SPI0\+\_\+\+DEV0}} = 0
\item 
int \mbox{\hyperlink{namespaceapp_1_1pins__cm5_a0ca4080866506142fe823a43d5cc9b04}{app.\+pins\+\_\+cm5.\+SPI0\+\_\+\+DEV1}} = 1
\item 
int \mbox{\hyperlink{namespaceapp_1_1pins__cm5_a9972c7d851be0cf7f570cd6afb0afdce}{app.\+pins\+\_\+cm5.\+SPI1\+\_\+\+DEV0}} = 0
\item 
int \mbox{\hyperlink{namespaceapp_1_1pins__cm5_a885ffd3784ac740228820ac13e88a615}{app.\+pins\+\_\+cm5.\+SPI\+\_\+\+MUX\+\_\+\+SPEED\+\_\+\+HZ}} = 100000
\item 
int \mbox{\hyperlink{namespaceapp_1_1pins__cm5_af4c124729456a53c298e00a7ad18d434}{app.\+pins\+\_\+cm5.\+SPI\+\_\+\+ADC\+\_\+\+SPEED\+\_\+\+HZ}} = 100000
\end{DoxyCompactItemize}

\doxysubsection{Description détaillée}
Mapping GPIO et SPI fixés pour la plateforme CM5. 

Ce module définit tous les assignements de broches GPIO et les paramètres SPI fixes pour la carte CM5. Ces constantes ne doivent pas être modifiées via la configuration utilisateur car elles correspondent au routage matériel de la carte. \begin{DoxyAuthor}{Auteur}
Léo Mendes @project 2510\+\_\+\+Regulations\+Chauffage @\+Mandant Oblo\+\_\+solution 
\end{DoxyAuthor}
\begin{DoxyDate}{Date}
2025-\/09-\/18 
\end{DoxyDate}
\begin{DoxyVersion}{Version}
1.\+0.\+0 
\end{DoxyVersion}
\begin{DoxyCopyright}{Copyright}
Copyright (c) 2025 
\end{DoxyCopyright}

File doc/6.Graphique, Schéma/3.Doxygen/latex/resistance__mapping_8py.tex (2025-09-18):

\doxysection{Référence du fichier C\+:/\+Users/thebi/\+Documents/2510\+\_\+\+Regulation\+Chauffage/doc/9.Soft\+Ware/\+Doxygen/src/app/resistance\+\_\+mapping.py}
\hypertarget{resistance__mapping_8py}{}\label{resistance__mapping_8py}\index{C:/Users/thebi/Documents/2510\_RegulationChauffage/doc/9.SoftWare/Doxygen/src/app/resistance\_mapping.py@{C:/Users/thebi/Documents/2510\_RegulationChauffage/doc/9.SoftWare/Doxygen/src/app/resistance\_mapping.py}}

Mapping des résistances TMUX par type de sonde de température.  

\doxysubsubsection*{Espaces de nommage}
\begin{DoxyCompactItemize}
\item 
namespace \mbox{\hyperlink{namespaceapp}{app}}
\item 
namespace \mbox{\hyperlink{namespaceapp_1_1resistance__mapping}{app.\+resistance\+\_\+mapping}}
\end{DoxyCompactItemize}
\doxysubsubsection*{Fonctions}
\begin{DoxyCompactItemize}
\item 
dict \mbox{\hyperlink{namespaceapp_1_1resistance__mapping_abcef5f0352c26d7e5540d9bc85a3e3fa}{app.\+resistance\+\_\+mapping.\+get\+\_\+channel\+\_\+mux\+\_\+map}} (str sensor\+\_\+type)
\begin{DoxyCompactList}\small\item\em Retourne le mapping CHANNEL\+\_\+\+MUX pour un type de sonde donné. \end{DoxyCompactList}\item 
tuple \mbox{\hyperlink{namespaceapp_1_1resistance__mapping_ad97e98ca666d8a3efb4c892acd311297}{app.\+resistance\+\_\+mapping.\+find\+\_\+closest\+\_\+channel}} (float target\+\_\+resistance, str sensor\+\_\+type)
\begin{DoxyCompactList}\small\item\em Trouve le canal MUX le plus proche pour une résistance cible. \end{DoxyCompactList}\end{DoxyCompactItemize}
\doxysubsubsection*{Variables}
\begin{DoxyCompactItemize}
\item 
dict \mbox{\hyperlink{namespaceapp_1_1resistance__mapping_a3b615cabdb8c20924f8da06a285bc117}{app.\+resistance\+\_\+mapping.\+CHANNEL\+\_\+\+MUX}}
\end{DoxyCompactItemize}

\doxysubsection{Description détaillée}
Mapping des résistances TMUX par type de sonde de température. 

Ce module fournit les tables de correspondance entre les canaux 0-\/31 du multiplexeur TMUX et les valeurs de résistance réelles pour différents types de sondes de température. Chaque type de sonde dispose d\textquotesingle{}un mapping spécifique avec 32 valeurs calibrées. \begin{DoxyAuthor}{Auteur}
Léo Mendes @project 2510\+\_\+\+Regulations\+Chauffage @\+Mandant Oblo\+\_\+solution 
\end{DoxyAuthor}
\begin{DoxyDate}{Date}
2025-\/09-\/18 
\end{DoxyDate}
\begin{DoxyVersion}{Version}
1.\+0.\+0 
\end{DoxyVersion}
\begin{DoxyCopyright}{Copyright}
Copyright (c) 2025 
\end{DoxyCopyright}

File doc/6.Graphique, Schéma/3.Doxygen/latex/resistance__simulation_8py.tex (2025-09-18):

\doxysection{Référence du fichier C\+:/\+Users/thebi/\+Documents/2510\+\_\+\+Regulation\+Chauffage/doc/9.Soft\+Ware/\+Doxygen/src/app/resistance\+\_\+simulation.py}
\hypertarget{resistance__simulation_8py}{}\label{resistance__simulation_8py}\index{C:/Users/thebi/Documents/2510\_RegulationChauffage/doc/9.SoftWare/Doxygen/src/app/resistance\_simulation.py@{C:/Users/thebi/Documents/2510\_RegulationChauffage/doc/9.SoftWare/Doxygen/src/app/resistance\_simulation.py}}

Module pour commander le MUX de simulation de résistance.  

\doxysubsubsection*{Classes}
\begin{DoxyCompactItemize}
\item 
class \mbox{\hyperlink{classapp_1_1resistance__simulation_1_1_resistance_simulation_error}{app.\+resistance\+\_\+simulation.\+Resistance\+Simulation\+Error}}
\begin{DoxyCompactList}\small\item\em Exception pour les erreurs de simulation de résistance. \end{DoxyCompactList}\item 
class \mbox{\hyperlink{classapp_1_1resistance__simulation_1_1_resistance_simulator}{app.\+resistance\+\_\+simulation.\+Resistance\+Simulator}}
\begin{DoxyCompactList}\small\item\em Contrôleur pour la simulation de résistance via MUX. \end{DoxyCompactList}\end{DoxyCompactItemize}
\doxysubsubsection*{Espaces de nommage}
\begin{DoxyCompactItemize}
\item 
namespace \mbox{\hyperlink{namespaceapp}{app}}
\item 
namespace \mbox{\hyperlink{namespaceapp_1_1resistance__simulation}{app.\+resistance\+\_\+simulation}}
\end{DoxyCompactItemize}
\doxysubsubsection*{Fonctions}
\begin{DoxyCompactItemize}
\item 
bool \mbox{\hyperlink{namespaceapp_1_1resistance__simulation_ab4df858485a2008da66e5eaed218f67b}{app.\+resistance\+\_\+simulation.\+apply\+\_\+resistance\+\_\+simulation}} (float resistance\+\_\+ohm)
\begin{DoxyCompactList}\small\item\em Fonction utilitaire pour appliquer une résistance simulée. \end{DoxyCompactList}\end{DoxyCompactItemize}
\doxysubsubsection*{Variables}
\begin{DoxyCompactItemize}
\item 
\mbox{\hyperlink{namespaceapp_1_1resistance__simulation_a1e0083edc4bb5cd3cf145384e73c9fb3}{app.\+resistance\+\_\+simulation.\+sim}} = \mbox{\hyperlink{classapp_1_1resistance__simulation_1_1_resistance_simulator}{Resistance\+Simulator}}()
\item 
bool \mbox{\hyperlink{namespaceapp_1_1resistance__simulation_af7b157026a22cabc88ac2a1df2bf0a45}{app.\+resistance\+\_\+simulation.\+success}} = sim.\+apply\+\_\+resistance\+\_\+simulation(1000.\+0)
\item 
\mbox{\hyperlink{namespaceapp_1_1resistance__simulation_a0b6740f840f43350912072a8757fb6e5}{app.\+resistance\+\_\+simulation.\+valid}} = sim.\+validate\+\_\+resistance\+\_\+applied(667.\+0, tolerance=0.\+15)
\end{DoxyCompactItemize}

\doxysubsection{Description détaillée}
Module pour commander le MUX de simulation de résistance. 

Ce module permet d\textquotesingle{}appliquer une résistance simulée R\+\_\+sim via le réseau de résistances contrôlé par multiplexeur ADG731. Il gère le calcul des commutateurs à activer, la commande du multiplexeur, et la validation des valeurs appliquées. \begin{DoxyAuthor}{Auteur}
Léo Mendes @project 2510\+\_\+\+Regulations\+Chauffage @\+Mandant Oblo\+\_\+solution 
\end{DoxyAuthor}
\begin{DoxyDate}{Date}
2025-\/09-\/18 
\end{DoxyDate}
\begin{DoxyVersion}{Version}
1.\+0.\+0 
\end{DoxyVersion}
\begin{DoxyCopyright}{Copyright}
Copyright (c) 2025 
\end{DoxyCopyright}

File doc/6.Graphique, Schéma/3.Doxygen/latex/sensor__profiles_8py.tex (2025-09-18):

\doxysection{Référence du fichier C\+:/\+Users/thebi/\+Documents/2510\+\_\+\+Regulation\+Chauffage/doc/9.Soft\+Ware/\+Doxygen/src/app/sensor\+\_\+profiles.py}
\hypertarget{sensor__profiles_8py}{}\label{sensor__profiles_8py}\index{C:/Users/thebi/Documents/2510\_RegulationChauffage/doc/9.SoftWare/Doxygen/src/app/sensor\_profiles.py@{C:/Users/thebi/Documents/2510\_RegulationChauffage/doc/9.SoftWare/Doxygen/src/app/sensor\_profiles.py}}

Profils capteurs extraits de \textquotesingle{}Calcul ADC.\+xlsx\textquotesingle{} (Feuil1).  

\doxysubsubsection*{Espaces de nommage}
\begin{DoxyCompactItemize}
\item 
namespace \mbox{\hyperlink{namespaceapp}{app}}
\item 
namespace \mbox{\hyperlink{namespaceapp_1_1sensor__profiles}{app.\+sensor\+\_\+profiles}}
\end{DoxyCompactItemize}
\doxysubsubsection*{Fonctions}
\begin{DoxyCompactItemize}
\item 
\mbox{\hyperlink{namespaceapp_1_1sensor__profiles_aea6e8ef0fc12b3785bef45a23fde7b81}{app.\+sensor\+\_\+profiles.\+get\+\_\+profile}} (sensor\+\_\+name)
\begin{DoxyCompactList}\small\item\em Récupère le profil de configuration ADC pour un capteur donné. \end{DoxyCompactList}\end{DoxyCompactItemize}
\doxysubsubsection*{Variables}
\begin{DoxyCompactItemize}
\item 
dict \mbox{\hyperlink{namespaceapp_1_1sensor__profiles_a8e0133ad4e40a6805aacf8f271fe96b5}{app.\+sensor\+\_\+profiles.\+SENSOR\+\_\+\+PROFILES}}
\end{DoxyCompactItemize}

\doxysubsection{Description détaillée}
Profils capteurs extraits de \textquotesingle{}Calcul ADC.\+xlsx\textquotesingle{} (Feuil1). 

Ce module contient les profils de configuration pour différents types de capteurs de température avec leurs paramètres ADC optimisés (Rref, IDAC, PGA) et leurs tables de conversion température/résistance. Les données proviennent des calculs d\textquotesingle{}optimisation du fichier Excel de référence. \begin{DoxyAuthor}{Auteur}
Léo Mendes @project 2510\+\_\+\+Regulations\+Chauffage @\+Mandant Oblo\+\_\+solution 
\end{DoxyAuthor}
\begin{DoxyDate}{Date}
2025-\/09-\/18 
\end{DoxyDate}
\begin{DoxyVersion}{Version}
1.\+0.\+0 
\end{DoxyVersion}
\begin{DoxyCopyright}{Copyright}
Copyright (c) 2025 
\end{DoxyCopyright}

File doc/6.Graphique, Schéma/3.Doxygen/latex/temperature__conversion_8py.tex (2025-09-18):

\doxysection{Référence du fichier C\+:/\+Users/thebi/\+Documents/2510\+\_\+\+Regulation\+Chauffage/doc/9.Soft\+Ware/\+Doxygen/src/app/temperature\+\_\+conversion.py}
\hypertarget{temperature__conversion_8py}{}\label{temperature__conversion_8py}\index{C:/Users/thebi/Documents/2510\_RegulationChauffage/doc/9.SoftWare/Doxygen/src/app/temperature\_conversion.py@{C:/Users/thebi/Documents/2510\_RegulationChauffage/doc/9.SoftWare/Doxygen/src/app/temperature\_conversion.py}}

Module de conversion résistance/température via interpolation linéaire.  

\doxysubsubsection*{Espaces de nommage}
\begin{DoxyCompactItemize}
\item 
namespace \mbox{\hyperlink{namespaceapp}{app}}
\item 
namespace \mbox{\hyperlink{namespaceapp_1_1temperature__conversion}{app.\+temperature\+\_\+conversion}}
\end{DoxyCompactItemize}
\doxysubsubsection*{Fonctions}
\begin{DoxyCompactItemize}
\item 
\mbox{\hyperlink{namespaceapp_1_1temperature__conversion_a2f762505fc59cc6983734bb32a6a1688}{app.\+temperature\+\_\+conversion.\+resistance\+\_\+to\+\_\+temperature}} (resistance, table)
\begin{DoxyCompactList}\small\item\em Convertit une résistance mesurée en température via interpolation linéaire. \end{DoxyCompactList}\item 
\mbox{\hyperlink{namespaceapp_1_1temperature__conversion_aff1ea0c25c07f16216abc29f0b51dbcb}{app.\+temperature\+\_\+conversion.\+resistance\+\_\+to\+\_\+temperature\+\_\+dynamic}} (resistance, sensor)
\begin{DoxyCompactList}\small\item\em Convertit une résistance mesurée en température pour un capteur donné. \end{DoxyCompactList}\item 
\mbox{\hyperlink{namespaceapp_1_1temperature__conversion_ae4de96194237eecce3dd936d5c6ee5f1}{app.\+temperature\+\_\+conversion.\+temperature\+\_\+to\+\_\+resistance\+\_\+dynamic}} (temperature, sensor)
\begin{DoxyCompactList}\small\item\em Convertit une température en résistance pour un capteur donné (conversion inverse). \end{DoxyCompactList}\item 
\mbox{\hyperlink{namespaceapp_1_1temperature__conversion_a2955653dd2d798b6d389f79519b3b747}{app.\+temperature\+\_\+conversion.\+convert\+\_\+temperature\+\_\+to\+\_\+resistance}} (temperature, probe\+\_\+type)
\begin{DoxyCompactList}\small\item\em Fonction de conversion principale pour la simulation de résistance. \end{DoxyCompactList}\item 
\mbox{\hyperlink{namespaceapp_1_1temperature__conversion_aa8915bfda252299d2cda2ea561b46ffe}{app.\+temperature\+\_\+conversion.\+get\+\_\+supported\+\_\+probe\+\_\+types}} ()
\begin{DoxyCompactList}\small\item\em Retourne la liste des types de sondes supportés. \end{DoxyCompactList}\item 
\mbox{\hyperlink{namespaceapp_1_1temperature__conversion_aa8da477a88ed675741e3be17b99fac56}{app.\+temperature\+\_\+conversion.\+validate\+\_\+temperature\+\_\+range}} (temperature, probe\+\_\+type)
\begin{DoxyCompactList}\small\item\em Valide si une température est dans la plage supportée par une sonde. \end{DoxyCompactList}\end{DoxyCompactItemize}

\doxysubsection{Description détaillée}
Module de conversion résistance/température via interpolation linéaire. 

Ce module fournit les fonctions de conversion bidirectionnelle entre résistance mesurée et température pour différents types de capteurs. Utilise l\textquotesingle{}interpolation linéaire sur les tables de calibration et supporte la conversion inverse pour la simulation de résistance. \begin{DoxyAuthor}{Auteur}
Léo Mendes @project 2510\+\_\+\+Regulations\+Chauffage @\+Mandant Oblo\+\_\+solution 
\end{DoxyAuthor}
\begin{DoxyDate}{Date}
2025-\/09-\/18 
\end{DoxyDate}
\begin{DoxyVersion}{Version}
1.\+0.\+0 
\end{DoxyVersion}
\begin{DoxyCopyright}{Copyright}
Copyright (c) 2025 
\end{DoxyCopyright}

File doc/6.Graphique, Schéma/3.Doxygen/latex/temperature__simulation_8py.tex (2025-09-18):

\doxysection{Référence du fichier C\+:/\+Users/thebi/\+Documents/2510\+\_\+\+Regulation\+Chauffage/doc/9.Soft\+Ware/\+Doxygen/src/app/temperature\+\_\+simulation.py}
\hypertarget{temperature__simulation_8py}{}\label{temperature__simulation_8py}\index{C:/Users/thebi/Documents/2510\_RegulationChauffage/doc/9.SoftWare/Doxygen/src/app/temperature\_simulation.py@{C:/Users/thebi/Documents/2510\_RegulationChauffage/doc/9.SoftWare/Doxygen/src/app/temperature\_simulation.py}}

Module de calcul de température simulée selon formule prédictive.  

\doxysubsubsection*{Espaces de nommage}
\begin{DoxyCompactItemize}
\item 
namespace \mbox{\hyperlink{namespaceapp}{app}}
\item 
namespace \mbox{\hyperlink{namespaceapp_1_1temperature__simulation}{app.\+temperature\+\_\+simulation}}
\end{DoxyCompactItemize}
\doxysubsubsection*{Fonctions}
\begin{DoxyCompactItemize}
\item 
Optional\mbox{[}float\mbox{]} \mbox{\hyperlink{namespaceapp_1_1temperature__simulation_ad0955f54e494774453fd9395ddf156f3}{app.\+temperature\+\_\+simulation.\+calculate\+\_\+simulated\+\_\+temperature}} (float t\+\_\+mes, float t\+\_\+prev, float n, float k\+\_\+m)
\begin{DoxyCompactList}\small\item\em Calcule la température simulée selon la formule prédictive. \end{DoxyCompactList}\item 
bool \mbox{\hyperlink{namespaceapp_1_1temperature__simulation_a34c95102387b78fc0ae24419cfdc62be}{app.\+temperature\+\_\+simulation.\+validate\+\_\+simulation\+\_\+parameters}} (str probe\+\_\+type, float n, float k\+\_\+m, float t\+\_\+mes, float t\+\_\+prev)
\begin{DoxyCompactList}\small\item\em Valide tous les paramètres de simulation avant exécution. \end{DoxyCompactList}\item 
Optional\mbox{[}float\mbox{]} \mbox{\hyperlink{namespaceapp_1_1temperature__simulation_a9dce35a5a5235426dcb9002af6f2fe80}{app.\+temperature\+\_\+simulation.\+run\+\_\+temperature\+\_\+simulation}} (dict simulation\+\_\+data)
\begin{DoxyCompactList}\small\item\em Exécute une simulation complète de température avec dictionnaire. \end{DoxyCompactList}\end{DoxyCompactItemize}

\doxysubsection{Description détaillée}
Module de calcul de température simulée selon formule prédictive. 

Ce module implémente la formule de simulation de température\+: 
\begin{DoxyCode}{0}
\DoxyCodeLine{T\_sim\ =\ T\_mes\ +\ ((T\_prev\ -\/\ T\_mes)\ *\ n\ *\ exp(k\_m))}

\end{DoxyCode}
 Inclut la validation complète des paramètres, la gestion des erreurs numériques et l\textquotesingle{}exécution de simulations complètes. \begin{DoxyAuthor}{Auteur}
Léo Mendes @project 2510\+\_\+\+Regulations\+Chauffage @\+Mandant Oblo\+\_\+solution 
\end{DoxyAuthor}
\begin{DoxyDate}{Date}
2025-\/09-\/18 
\end{DoxyDate}
\begin{DoxyVersion}{Version}
1.\+0.\+0 
\end{DoxyVersion}
\begin{DoxyCopyright}{Copyright}
Copyright (c) 2025 
\end{DoxyCopyright}

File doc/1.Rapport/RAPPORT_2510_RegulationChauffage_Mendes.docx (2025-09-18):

Rapport de Projet

École supérieure

Électronique

2510 Régulation Chauffage

Réalisé par :

Léo Mendes

À l’attention de :

M. Philippe Bovey

M. Antonin Graf

M. Philippe Moeschler

Oblo Solutions

Dates :

Début du projet : 18.08.2025

Fin du projet : 23.09.2025

Table des matières :

# 1 Cahier des charges

## 1.1 But du projet

Le projet 2510_RegulationChauffage vise à remplacer l’automate WAGO trop cher par une solution électronique dédiée, intégrant un Compute Module 5 et un système de simulation de sondes résistives.

Le but est de lire les vraies sondes, de calculer une température simulée en fonction des prévisions météo, puis de générer la résistance équivalente pour piloter directement la chaudière.

Le système doit être compact, précis et capable de gérer plusieurs sondes en parallèle. L’objectif est de concevoir une électronique complète (hardware et firmware) qui assure la régulation chauffage, reproduisant le comportement des sondes standards (Ni1000 TK5000 comme référence) et fournissant une valeur résistive stable à la chaudière.

Le tout doit réduire les coûts par rapport à la solution WAGO, permettre plus de sondes connectées et s’intégrer dans un boîtier déjà défini.

## 1.2 Spécifications du projet

## 1.3 Tâches à réaliser

- Conception et routage des deux cartes (mère et fille) sous Altium, avec BOM complète et fichiers de production.
- Développement du firmware : acquisition via ADC, gestion du MUX, conversion analogique-numérique en °C, commande relais, communication réseau.
- Assemblage et validation d’un prototype : mesures de précision, bruit, stabilité.
- Intégration mécanique dans le boîtier fourni par le client.
- Rédaction d’un rapport détaillé avec schémas, calculs, validations et procédures de test.

## 1.4 Jalons principaux

- Définition et validation des spécifications avec le mandataire.
- Réalisation des schémas et routages de la carte mère et d’une carte fille.
- Fabrication et assemblage du prototype.
- Développement initial du firmware et tests d’acquisition/commande.
- Validation complète hardware + firmware avec calibration des 32 points résistifs.
- Livraison finale avec prototype fonctionnel, fichiers sources, documentation et rapport de diplôme.

## 1.5 Livrables

- Les fichiers sources de CAO électronique des PCB réalisés
- Tout le nécessaire à fabriquer un exemplaire hardware de chaque :
- Fichiers de fabrication (GERBER) / liste de pièces avec références pour commande / implantation (prototype) / modifications / dessins mécaniques.
- Les fichiers sources de programmation microcontrôleur (.ce/ .h)
- Tout le nécessaire pour programmer les microcontrôleurs (logiciel ou fichier .hex)
- Les fichiers sources de programmation PC/Windows/Linux.
- Tout le nécessaire à l’installation de programmes sur PC/Windows/Linux.
- Un mode d’emploi du système
- Un calcul / estimation des coûts
- Un rapport contenant les calculs - dimensionnement de composants – structogramme.

# 2 Préétude :

## 2.1 Architecture

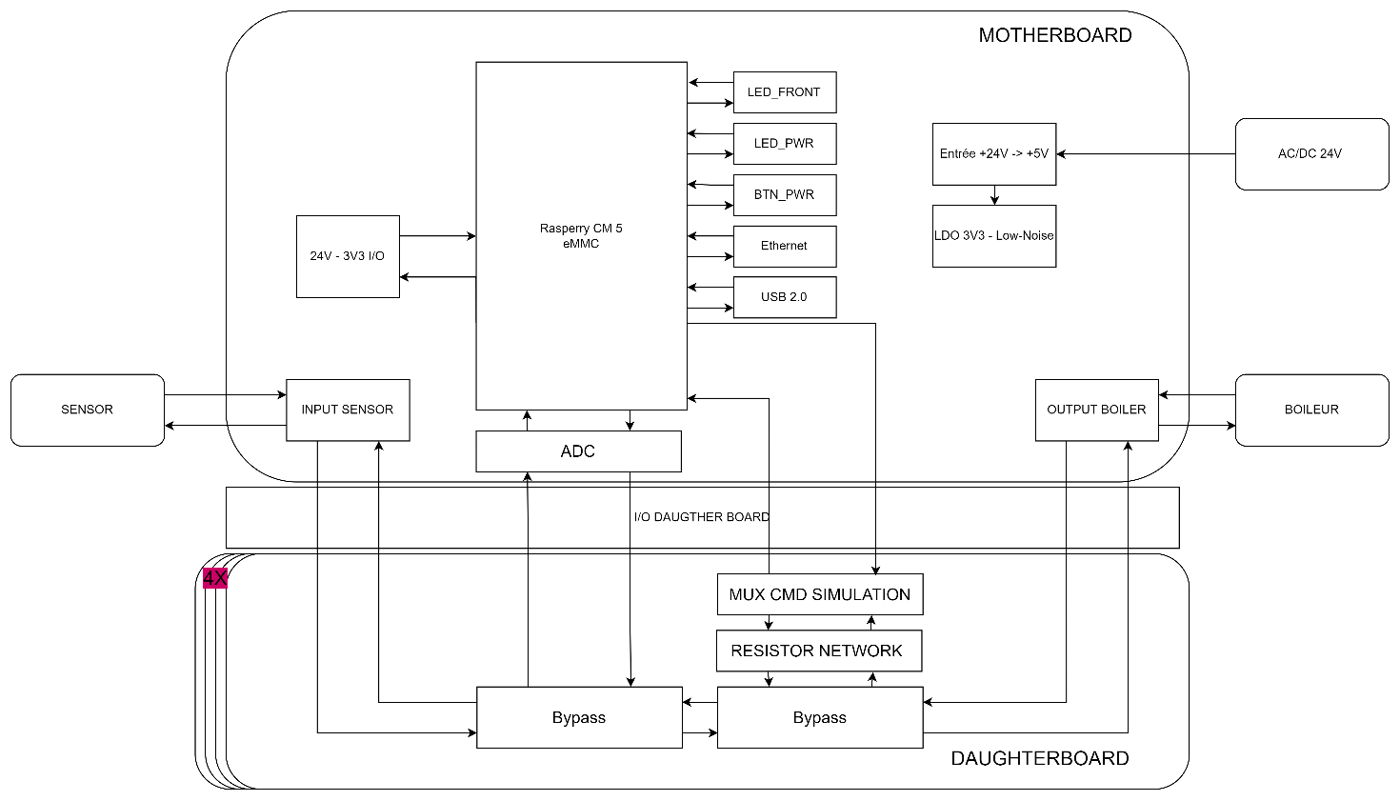
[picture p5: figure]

Figure 1

## 2.2 Schéma bloc avec choix des composants

# 3 Design

## 3.1 Bloc Alimentation

### 3.1.1 Buck down 24V – 5V

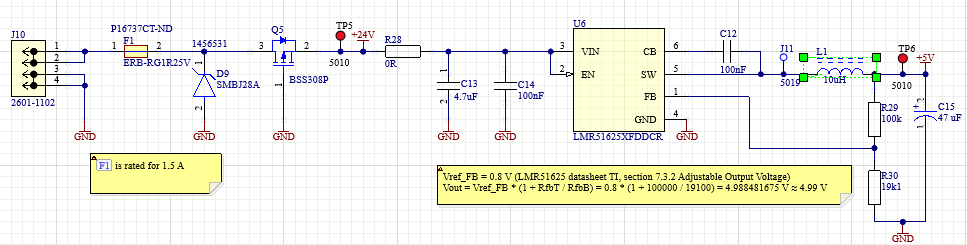
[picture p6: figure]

Figure 2

#### 3.1.1.1 Protection entrée

Le 24 V est directement raccordé à un bornier WAGO 2601-1102.

Pour éviter tout risque lié à une mauvaise manipulation, plusieurs protections sont intégrées.

Un fusible ERB-RG1R25V protège la carte contre les surintensités dépassant 1.5 A.

Une diode TVS SMBJ28A assure une protection contre les surtensions, en particulier les décharges électrostatiques. Elle répond aux exigences de la norme IEC-61000-4-2 ESD définies dans le cahier des charges.

Un MOSFET canal P FDN340P est utilisé pour réaliser une diode idéale, protégeant contre les inversions de polarité.

Grâce à ces éléments, la carte bénéficie d’une protection complète et fiable.

#### 3.1.1.2 Dimensionnement Buck down

Ce bloc a été dimensionner au moyen du calculateur TI « WEBENCH -POWER DEGISGNER ». Cet outil permet de trouver des schématiques, définir des consigne en termes de tensions, et de simuler les résultats avec une estimation de la consommations, tension de sorties.

Le schéma calculé par le logiciel nous donne :

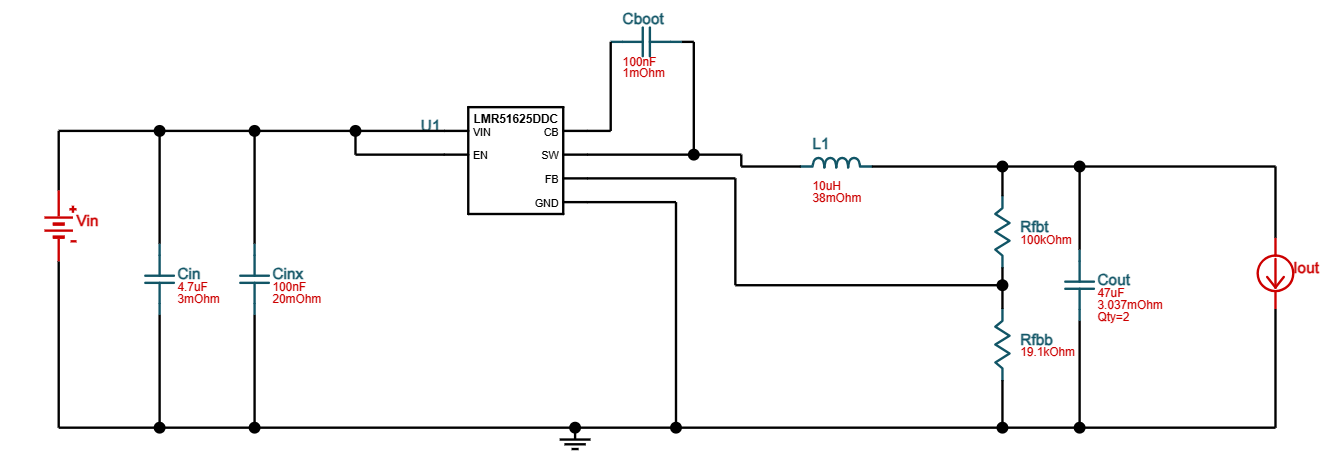
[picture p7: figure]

Figure 3 – Valeur calculée par le calculateur[^1]

Les données calculées par le calculateur sont en annexe au point XX

##### 3.1.1.2.1 Analyse du LMR33620SDDCR

Le LMR51625 est un régulateur buck synchrone 60 V / 2.5 A. Ce composant est décliné en plusieurs variantes définies par deux paramètres : la fréquence de découpage et le mode de régulation.

- Versions X : fréquence nominale de 400 kHz
- Versions Y : fréquence nominale de 1.1 MHz

À l’intérieur de chaque fréquence, deux modes sont disponibles :

- DDCR (PFM automatique) : bascule en PFM à faible charge pour améliorer le rendement, fréquence variable en fonction de la charge. Moins prévisible pour le dimensionnement des passifs.
- FDDCR (FPWM forcé) : la fréquence reste fixe (400 kHz ou 1.1 MHz selon la version). Bruit et ondulation constants, dimensionnement simplifié. Rendement légèrement inférieur à faible charge.

Le calculateur démontre une fréquence de switching constante (400 kHz), indépendamment de la charge. Cela correspond au mode FPWM forcé (FDDCR).

De cette faite le composant réelle utilisé est le « LMR51625XFDDCR ».

##### 3.1.1.2.2 Confirmation du dimensionnement

En utilisant les formules de convertisseurs buck down, nous pouvons recalculer les valeurs proposées par le calculateur et ainsi confirmer son dimensionnement.

D_(idéal) =(V_(out))/(V_(in))=5.0/24.0=0.2083

k = 0.4

ΔI_L =k⋅I_(out) =0.40⋅2.5=1.0000[A]

L_(requis) =(V_(out) ⋅(1-D_(idéal) ))/(ΔI_L ⋅f_(SW))=(5.0⋅(1-0.2083))/(1.0000⋅400000)=9.895⋅10^(-6) [H]

I_(pk) =I_(out) +(ΔI_L)/2=2.5+1.0/2=3.00[A]

I_(L,RMS) =√(I_(out)^2 +(ΔI_L^2)/12)=√(2.5^2 +(1.0^2)/12)=2.517[A]

η=(P_(out))/(P_(in))=(5.0⋅2.5)/13.4518=0.9293

I_(in,avg) =(P_(out))/(η⋅V_(in))=(V_(out) ⋅I_(out))/(η⋅V_(in))= (5⋅2.5)/(0.9293⋅24)= 560⋅10^(-3) [A]

P_(in) =V_(in) ⋅I_(in,avg) =24.0⋅0.56049=13.4518[W]

P_(pertes) =P_(in) -P_(out) =13.4518-12.5=0.9518[W]

Comparaison :

Paramètre | Unité | Outil TI | Recalculé | Erreur absolue | Erreur relative
Duty cycle D | | 22,30% | 20,83% | -0,0147 | -6,59%
Inductance L | µH | 10,00 | 9,90 | -0,1050 | -1,05%
Courant pic Ipk | A | 3,020 | 3,000 | -0,0200 | -0,66%
IL RMS | A | 2,520 | 2,517 | -0,0030 | -0,12%
Iin moyen | A | 0,560 | 0,560 | 0,0000 | 0,00%
Pin | W | 13,4518 | 13,4518 | 0,0000 | 0,00%
Pertes totales | W | 0,9519 | 0,9518 | 0,0000 | -0,01%
Rendement η | % | 92,93% | 92,93% | 0,0000 | 0,00%

### 3.1.2 Bloc LDO 5V – 3V3

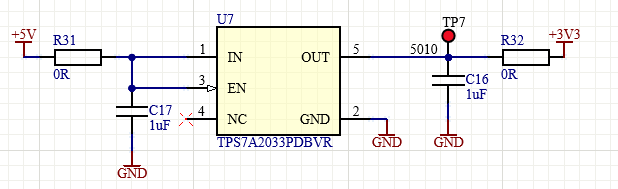
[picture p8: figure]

Figure 4

Ce bloc met en place un régulateur LDO TPS7A2024PDBVR. L’alimentation d’entrée est +5V, filtrée par C18 (1µF) et appliquée à la broche IN via R19 (0Ω). La sortie OUT délivre une tension régulée de +3V3, stabilisée par C19 (1µF) et protégée par R20 (0Ω).

Le composant est un régulateur faible bruit (low-noise), utilisé pour garantir une alimentation plus propre et limiter les perturbations sur les étages sensibles, notamment pour améliorer la précision de conversion du bloc ADC du projet.

La pin EN permet l’activation ou la désactivation du régulateur. Elle est directement connectée au 5V, ainsi le composant est actif dès la mise sous-alimentation du système.

Le TPS7A2024 est capable de fournir jusqu’à 200 mA sur la sortie +3V3.

### 3.1.3 Pont pour mise en service

Entre chaque partie des alimentations se trouve une résistance 0[Ω]. Celle-ci permettront de tester chaque tension avant la mise en en service effective du système.

### 3.1.4 Consommations estimées

BLOC Alimentations MAX | Tension[V] | Courant[A] | Puissance[W]
AC/DC | 24 | 0.5 | 12
Buck down | 5 | 2.5 | 12.5
LDO | 3.3 | 0.3 | 0.99

Consommation 24[V] | Tension[V] : | 24 | Courant[A] | | | Puissance [W]
| | | Min | Typ | Max | Min | Typ | Max
Buck down | | | - | - | - | 0 | 2.311 | 5.654
24V-I/O | | | 0 | 0.005146 | 0.005146 | 0 | 0.1235 | 0.123504
Totaux (<15[W] = OK) | | | 0 | 0.005146 | 0.005146 | 0 | 2.4345 | 5.777504

Consommation 5[V] | Tension[V] : | 5 | Courant[A] | | | Puissance [W]
| | | Min | Typ | Max | Min | Typ | Max
Raspberry CM5 | | | 0.003 | 0.4 | 0.9 | 0.015 | 2 | 4.5
Front LED | | | 0 | 0.002 | 0.002 | 0 | 0.01 | 0.01
LED Ethernet | | | 0 | 0.004 | 0.004 | 0 | 0.02 | 0.02
Bypass INPUT relay (min = 0 relay, typ = 2 relay, max = 8 relay ) | | | 0 | 0.0562 | 0.2248 | 0 | 0.281 | 1.124
Consommation LDO TPS7A2024PDBVR | | | 0 | 0.0000065 | 0.0000065 | 0 | 0.0000325 | 0.0000325
Sortie LDO | | | - | - | - | 0 | 0,1341351 | 0,1345806
Totaux (<12.5[W] = OK) | | | 0.003 | 0.4622 | 1.1308 | 0.015 | 2.311 | 5.654

Consommation 3.3[V] | Tension[V] : | 3.3 | Courant[A] | | | Puissance [W]
| | | Min | Typ | Max | Min | Typ | Max
ADS124S08IPBSR | | | 0 | 0.000635 | 0.00074 | 0 | 0.0020955 | 0.002442
TMUX1204DGSR | | | 0 | 0.000002 | 0.000002 | 0 | 0.0000066 | 0.0000066
LED activity | | | 0 | 0.02 | 0.02 | 0 | 0.066 | 0.066
LED Power | | | 0 | 0.02 | 0.02 | 0 | 0.066 | 0.066
ADG732BSUZ-REEL(min = 0 X, typ = 1 X, max = 4 X ) | | | 0 | 0.00001 | 0.00004 | 0 | 0.000033 | 0.000132
Totaux (<0.99[W] = OK) | | | 0 | 0,040647 | 0,040782 | 0 | 0,1341351 | 0,1345806

## 3.2 Bloc Computer Module

### 3.2.1 Description

Figure 5- Vue Raspberry PI[^2]

Le cœur de la logique du projet sera un Raspberry Pi Compute Module 5.

Ce module complet permet l’intégration de la logique dans un système embarqué.

Basé sur le Raspberry Pi 5, il exécute un système d’exploitation sur son processeur ARM ainsi que le firmware nécessaire au projet.

### 3.2.2 Schématique

Figure 6

### 3.2.3 Choix du modèle

Le CM5 devoir effectuer l’entièreté de la logique de système.

Ses fonctions seront les suivantes :

- Lecture A/D
- Gestion des I/O 24V-3V3
- Choix de la résistance simulée sur les cartes filles
- Communication Ethernet
- Commande soft des relais
- Gestion de la LED du panel avant du boitier

Afin de pouvoir effectuer ces fonctions le module nécessitera certaine spécifique. Le module sera décidé une fois les différents points aborder :

### 3.2.4 Alimentation

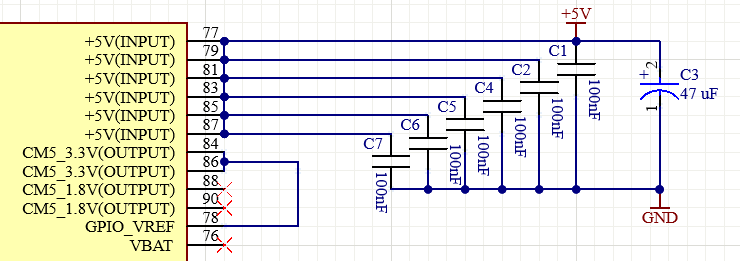
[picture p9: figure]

Figure 7 - Partie alimentation du CM5

Le module est alimenté en 5[V] depuis le bloc Buck down. Chaque pin 5[V] est découplée par un condensateur de 100[nF] placé au plus près, et un condensateur bulk de 47[uF] est positionné à l’entrée du domaine 5[V] pour amortir les appels de courant et stabiliser la tension.

GPIO_VREF est reliée à CM5_3V3(OUTPUT) afin d’établir des GPIO en 3.3[V], conformément au datasheet qui prescrit cette connexion pour des I/O en 3.3[V]. CM5_1.8(OUTPUT) n’est pas utilisée. Bien que CM5_3V3(OUTPUT) et CM5_1.8(OUTPUT) puissent fournir jusqu’à 300[mA], elles ne sont pas retenues pour les fonctions analogiques sensibles; les alimentations précises (ADC) sont générées via un LDO faible bruit.

### 3.2.5 Ethernet

Afin de pouvoir connecter notre système a un réseau informatique et internet. Il nous faut une communication ethernet. A travers de celle-ci le module sera programmé, possiblement paramétré et recevra les informations de l’API Oblo afin de commander la chaudière.

Figure 8

Le CM5 supporte une connectique RJ45 à 4 paires. Les 4 paires permettent 1000BASE-T à 1[Gbit/s] [^3].

Les débits inférieurs utilisent moins de paires : 100BASE-TX exploite 2 paires[^4],

Notre système n’a pas besoin d’un tel débit. 100[Kbit/s] suffisent pour l’application du projet.La liaison sera négociée en 100BASE-TX à 100[Mbit/s] (2 paires actives).

Ethernet SYNC OUT ne sera pas connectée, aucune horloge de synchronisation n’étant requise entre les systèmes du réseau.

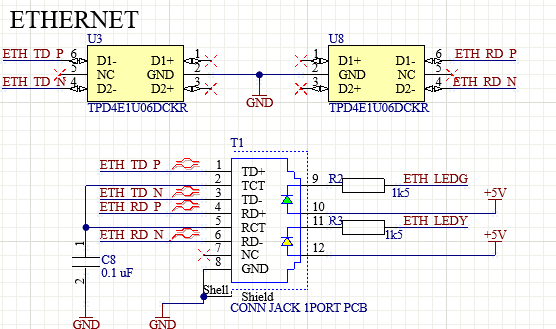
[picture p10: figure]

Figure 9

Le connecteur RJ45 reliera le système au réseau Ethernet.

Ce connecteur intègre deux LED :

- LED jaune : indication de la vitesse Ethernet
- LED verte : indication d’activité sur les lignes Ethernet

Les lignes Ethernets devront être router en différentiel avec une impédance contrôlée de 100[Ω].

Le condensateur C10, connecté aux pins RCT et TCT, assurera un filtrage de mode commun pour bloquer le bruit induit par le transformateur du connecteur, sans modifier les signaux différentiels.

La connectique sera protégée par 2 diodes TVS bidirectionnel de TPD4E1U06DCKR à 5V5. Ces diodes ayant qu’une petite capacité parasite de 0.8pF, elles seront parfaites pour ne pas influencé les communications Ethernet.

Ces diodes respectent la norme IEC 61000-4-2 comme demandé par le cahier des charges.

### 3.2.6 Mémoire

Le CM5 peuit utiliser deux types de mémoire, soit une carte SD externe ou une mémoire interne eMMC (Embedded Multi-Media Card).

Afin de simplifier et augmenter la stabilité du système l’utilisation d’une mémoire eMMC a été choisie par le mandant.

Cette mémoire permettra de stocker les firmware et le système d’exploitation de notre CM5. Le système nécessitera ainsi l’utilisation d’une connectique USB afin de pouvoir programmer ces mémoires.

### 3.2.7 USB 2.0

Comme définit ci-dessus, le port USB servira à pouvoir flasher le système. L’utilisations de la pins RPIBOOT sera nécessaire. Celle-ci permet l’USB d’accéder directement à la mémoire eMMC comme un périphérique dit « USB Mass Storage » permettant ainsi de la flasher avec l’OS choisis. Si cette pins est ouvert le système bootera automatique à partir de la mémoire eMMC.

Figure 10

Les communications USB ne nécessiteront non plus pas de grande vitesse et la programmations ce faisant uniquement par l’USB 2.0, De ce faite, la communication sera faite en USB 2.0. Le CM5 fournis les pins USB_P et USB_P seront alors utilisée.

Figure 11

USB_OTG_ID permettrais de faire du CM5 l’hôte d’une communication USB. Fonctionnalité non utile dans notre cas.

Figure 12

Un USB de type C sera utilisé pour la communication USB 2.0. Celui-ci fournit les lignes suivante :

- D+/D- : Ligne communication USB 2.0
- Le Vbus qui correspond au 5 [V] fournit par l’USB. Il ne sera pas utilisé dans notre projet
- CC1/CC2 sont des lignes de négociations de puissance pour l’USB C, elles seront connectées au CM5 pour permettre au CM5 de gérer ces lignes.
- SBU1/SBU2 qui sont des lignes de mode de communication alternatif pour l’USB4 ou le display port, non utilisée pour mon projet.

Les lignes de data de l’USB seront protégé par une diode TVS bidirectionnel même modèle que décrite pour l’Ethernet ci-dessus.

### 3.2.8 LED d’activité

Figure 13

Comme indiqué dans le datasheet du CM5[^5], la broche “LED_ACTIVITY” reproduit le comportement de la LED verte du Raspberry Pi 5.

Cette broche clignote pour indiquer l’accès à l’eMMC. En cas d’erreur au démarrage, la LED clignote selon un motif qui peut être décodé à l’aide de la table de correspondance fournie dans la documentation officielle Raspberry Pi.

Dans ce projet, la LED verte est directement commandée par le GPIO du CM5. Le dimensionnement est effectué afin d’obtenir un courant de 2.0 [mA].

Les données retenues sont les suivantes :

  - Vcc = 3.3 [V] (alimentation du système)
  - Vf = 2.1 [V] (LED verte LTST-C170KGKT)
  - VOL = 0.2 [V] (niveau bas GPIO CM5 à 2 mA)
  - Icible = 2.0 [mA] (courant visé pour LED témoin)
- R_(théorie) =(V_(cc) -V_f -V_(OL))/(I_(cible))=(3.3-2.1-0.2)/0.002=500.00[Ω]→560[Ω]
- I_(réel) =(V_(cc) -V_f -V_(OL))/(R_(E12))=(3.3-2.1-0.2)/560=0.001964[A]
- P_R =I_(réel) ⋅I_(réel) ⋅R_(E12) =0.001964⋅0.001964⋅560=0.00216[W]
- P_(LED) =V_f ⋅I_(réel) =2.1⋅0.001964=0.00412[W]
- P_(GPIO) =V_(OL) ⋅I_(réel) =0.2⋅0.001964=0.000393[W]

Tableau d’erreur de la led activité[^6] :

Long flashes | Short flashes | Status
0 | 3 | Generic failure to boot
0 | 4 | start*.elf not found
0 | 7 | Kernel image not found
0 | 8 | SDRAM failure
0 | 9 | Insufficient SDRAM
0 | 10 | In HALT state
1 | 2 | SD card overcurrent detected
2 | 1 | Partition not FAT
2 | 2 | Failed to read from partition
2 | 3 | Extended partition not FAT
2 | 4 | File signature/hash mismatch - Pi 4 and Pi 5
3 | 1 | SPI EEPROM error - Pi 4 and Pi 5
3 | 2 | SPI EEPROM is write protected - Pi 4 and Pi 5
3 | 3 | I2C error - Pi 4 and Pi 5
3 | 4 | Secure-boot configuration is not valid
4 | 3 | RP1 not found
4 | 4 | Unsupported board type
4 | 5 | Fatal firmware error
4 | 6 | Power failure type A
4 | 7 | Power failure type B

### 3.2.9 LED de POWER

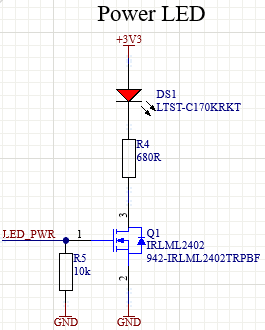
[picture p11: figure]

Figure 14

Comme indiqué dans le datasheet du CM5 (section 2.21), le signal “LED_nPWR” n’est pas conçu pour piloter directement une LED.

Ce signal reproduit le comportement de la LED rouge du Raspberry Pi 5 : lorsque la carte est alimentée mais éteinte, la LED s’allume allumée.

La LED Power est donc commandée par un MOSFET canal N (IRLML2402) en low-side, avec une alimentation en +3.3 V et une commutation côté masse.

Les valeurs utilisées pour le dimensionnement proviennent des caractéristiques suivantes :

- Alimentation du système : Vcc = 3.3 [V]
- Tension directe de la LED rouge : Vf = 2.0 [V]
- MOSFET low-side IRLML2402 : Rds_on,typ = 0.06 [Ω] ; Rds_on,max = 0.12 [Ω] à Vgs ≈ 3.3 [V]
- Courant visé pour la LED : Icible = 2.0 [mA]
- Résistance série retenue : R_E12 = 680 [Ω] (arrondi E12 au-dessus)
- R_(théorie) =(V_(cc) -V_f -I_(cible) ⋅R_(DSon,typ))/(I_(cible))=(3.3-2.0-0.002⋅0.06)/0.002=649.94[Ω] => 680[Ω]
- I_(réel) =(V_(cc) -V_f)/(R_(E12) +R_(DSon,typ))=(3.3-2.0)/(680+0.06)=0.001912[A]
- V_(low) =I_(réel) ⋅R_(DSon,typ) =0.001912⋅0.06=0.000115[V]
- P_R =I_(réel) ⋅I_(réel) ⋅R_(E12) =0.001912⋅0.001912⋅680=0.00249[W]
- P_(LED) =V_f ⋅I_(réel) =2.0⋅0.001912=0.00382[W]
- P_(MOS) =I_(réel) ⋅I_(réel) ⋅R_(DSon,typ) =0.001912⋅0.001912⋅0.06=2.19×10^(-7) [W]

### 3.2.10 Bouton d’allumage

Figure 15

Le bouton d’alimentation assure la fonction ON/OFF du Compute Module 5.

Lors de l’application de la tension d’alimentation, le système démarre automatiquement.

En cas de besoin de redémarrage, l’opérateur peut utiliser ce bouton pour réinitialiser le module.

La broche PWR_BTN intègre une résistance de pull-up interne, permettant la connexion directe du bouton.

Un appui court déclenche l’allumage ou l’extinction normale du CM5, tandis qu’un appui prolongé supérieur à 5 secondes force l’arrêt du système.

### 3.2.11 LED du panneau avant

Figure 16

Le boitier mécanique du systèmes possède une carte de face avant supplémentaire. Cette carte nommée « Oblo base led » est composée une d’une LED « OSRAM LW TWTG.BB-BXBY-2B12B3-Z486 »

Cette leds doit être commandée par le CM5 afin de donner des informations aux utilisateurs et opérateurs sans que la face avant ne soie retirée.

La led ayant une tension directe de 3.05[V], cette partie du système sera alimenté en 5[V].

Un courant de 20[mA] a été choisi pour permettre une visibilité correcte.

R =((Vcc - Vf))/(If) =((5 - 3.05))/0.02 = 97.5 [Ω]=>E12= 100 [Ω]

P = I ⋅U = 0.02 ⋅5 = 0.01[W]

### 3.2.12 GPIO

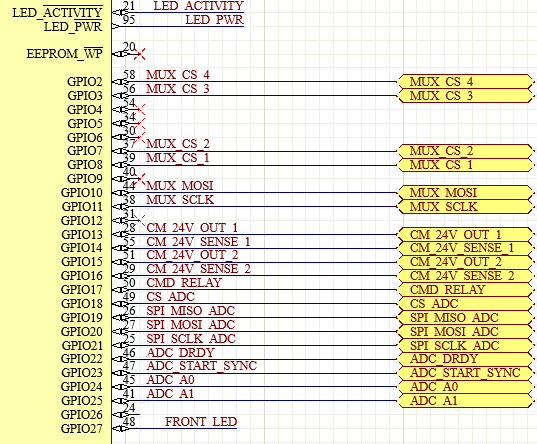
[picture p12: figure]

Figure 17

Les GPIO seront configurée ainsi :

Ligne | GPIO N° | Patte CM5 | N° fonction | Nom fonction
MUX_CS_4 | 2 | 58 | A0 | SPI0_CSn[3]
MUX_CS_3 | 3 | 56 | A0 | SPI0_CSn[2]
MUX_CS_2 | 7 | 37 | A0 | SPI0_CSn[1]
MUX_CS_1 | 8 | 39 | A0 | SPI0_CSn[0]
MUX_MOSI | 10 | 44 | A0 | SPI0_SIO[0]
MUX_SCLK | 11 | 38 | A0 | SPI0_SCLK
CM_24V_OUT_1 | 13 | 31 | A6 | PIO[13]
CM_24V_SENSE_1 | 14 | 8 | A6 | PIO[14]
CM_24V_OUT_2 | 15 | 5 | A6 | PIO[15]
CM_24V_SENSE_2 | 16 | 29 | A6 | PIO[16]
CMD_RELAY | 17 | 20 | A6 | PIO[17]
CS_ADC | 18 | 50 | A0 | SPI1_CSn[0]
SPI_MISO_ADC | 19 | 49 | A0 | SPI1_SIO[1]
SPI_MOSI_ADC | 20 | 26 | A0 | SPI1_SIO[0]
SPI_SCLK_ADC | 21 | 25 | A0 | SPI1_SCLK
ADC_DRDY | 22 | 46 | A6 | PIO[22]
ADC_START_SYNC | 23 | 47 | A6 | PIO[23]
ADC_A0 | 24 | 45 | A6 | PIO[24]
ADC_A1 | 25 | 41 | A6 | PIO[25]
FRONT_LED | 27 | 24 | A6 | PIO[27]

Figure 18

### 3.2.13 Protocoles utilisés

#### 3.2.13.1 SPI

La communication avec le convertisseur analogique-numérique repose sur le protocole SPI.

Ce protocole constitue l’unique type d’interface interne utilisée dans le cadre du projet.

Le Compute Module 5 dispose de quatre contrôleurs SPI.

Ces interfaces sont accessibles via les GPIO, en fonction des multiplexages disponibles et des fonctions assignées aux broches.

Pour communication avec l’ADC :

Ligne | GPIO N° | N fonction | Nom fonction
CS_ADC | 18 | A0 | SPI1_CSn[0]
SPI_SCLK_ADC | 21 | A0 | SPI1_SCLK
SPI_MOSI_ADC | 20 | A0 | SPI1_SIO[0]*
SPI_MISO_ADC | 19 | A0 | SPI1_SIO[1]*

*SIO[0] = MOSI / SIO[1] = MISO

Pour la commande du mutliplexer ADG731BSUZ le module SPI 0 sera utilisé :

Ligne | GPIO PIN | N fonction | Nom fonction
MUX_SCLK | 11 | A0 | SPI0_SCLK
MUX_MOSI | 10 | A0 | SPI0_SIO
MUX_CS_1 | 8 | A0 | SPI0_CSn[0]
MUX_CS_2 | 7 | A0 | SPI0_CSn[1]
MUX_CS_3 | 3 | A0 | SPI0_CSn[2]
MUX_CS_4 | 2 | A0 | SPI0_CSn[3]
MUX_MISO | 9 | A0 | SPI0_SIO[1] (non câblé)

Le multiplexer ADG731BSUZ ne disposant pas de ligne retour « MISO » La pins GPIO 9 sera réservée pour ne pas influencer les drivers spi du CM5 mais ne sera pas routée.

## 3.3 Bloc ADC

Figure 19

La mesure des sondes de température nécessite l’intégration d’un convertisseur analogique-numérique.

Le cahier des charges demande l’utilisation d’un ADC de type sigma-delta.

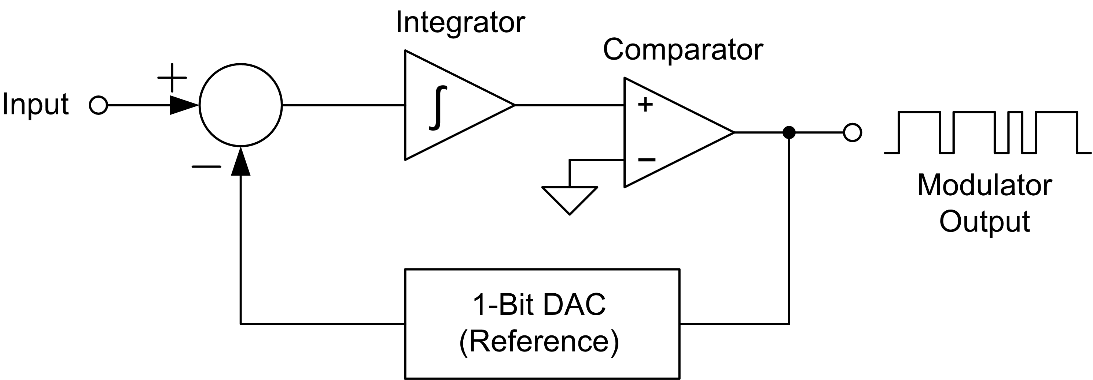
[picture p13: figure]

Figure 20 - Représentation ADC sigma-Delta[^7]

Le principe de conversion sigma-delta repose sur le suréchantillonnage et la modulation de densité d’impulsions.

Le signal analogique est intégré et continuellement comparé à une référence, produisant un flux binaire proportionnel à son amplitude.

Un filtre numérique associé à un décimateur permet ensuite d’obtenir une valeur numérique précise, avec une haute résolution adaptée aux signaux lents.

Cette architecture correspond aux exigences du projet, privilégiant la précision au détriment de la vitesse de conversion.

L’ADC doit cependant prendre en charge la lecture simultanée de quatre sondes, dont les caractéristiques peuvent varier selon les installations.

Cela impose une architecture flexible, capable d’adapter la gamme et le type de mesure à chaque configuration.

### 3.3.1 Type de sonde

Nom de la sonde | R @ -15°C [Ω] | R @ 40°C [Ω] | Technologie
De Dietrich AF60 | 2015,54 | 251,37 | NTC
Siemens QAC32 | 653 | 525 | NTC
PT1000 | 942 | 1155,5 | PTC
Ni1000 TK5000 | 935 | 1185,71 | PTC
Ni1000 TK6180 | 919 | 1230,7 | PTC
NTC 1k 3528 | 5855 | 574.6 | NTC
KTY81-210 | 1423 | 2245 | PTC
NTC 2k 3390 | 11124 | 1168,06 | NTC
NTC 2.2k 3528 | 12881 | 1173 | NTC
NTC 10k 3977 | 72502 | 5320 | NTC

Les sondes de température utilisées dans le projet fonctionnent toutes sur le principe de la variation de résistance en fonction de la température.525

Elles se répartissent en deux technologies principales :

- Les sondes PTC (Positive Temperature Coefficient) présentent une résistance qui augmente avec la température.
  - Elles offrent une bonne stabilité et une réponse relativement régulière, ce qui facilite l’exploitation par l’ADC et réduit la complexité de linéarisation.
- Les sondes NTC (Negative Temperature Coefficient) voient leur résistance diminuer lorsque la température augmente.
  - Elles présentent une sensibilité plus marquée mais leur réponse est fortement non linéaire, suivant une loi de type exponentielle.
  - Elles nécessitent donc un traitement numérique ou une table de correspondance pour obtenir une conversion précise.

Le système doit être capable d’intégrer indifféremment ces deux types de capteurs.

### 3.3.2 Choix du composant

L’ADS124S08 est choisi car il permet d’adapter la mesure en fonction de la sonde utilisée.

Il dispose de plusieurs gammes de courants IDAC, ce qui rend possible de définir un point de fonctionnement précis pour chaque type de capteur.

En ajustant le courant injecté, il est possible de limiter l’auto-échauffement tout en gardant une tension mesurable exploitable par le PGA interne.

Le principe ratiométrique[^8] avec une résistance de référence sélectionnée garantit une mesure stable et indépendante des variations du courant.

Cette flexibilité permet de prendre en charge aussi bien des NTC très non linéaires que des PTC plus réguliers, sans changer l’architecture globale du système.

### 3.3.3 Logique de mesure

Figure 21

#### 3.3.3.1 Excitation par courant contrôlé

L’ADS124S08 dispose de générateurs de courant internes (IDAC).

Un de ces courants est appliqué sur une entrée analogique pour traverser directement la sonde de température.

La sonde convertit donc la température en une résistance, et le courant Iadc impose une chute de tension proportionnelle (Usonde = Iadc · Rsonde).

#### 3.3.3.2 Mesure différentielle

Les deux bornes de la sonde sont reliées à une paire d’entrées différentielles de l’ADC.

Cette mesure différentielle supprime les offsets liés aux masses et permet de ne mesurer que la tension réelle aux bornes de la sonde.

Le PGA interne peut ensuite amplifier ce signal pour optimiser la dynamique de conversion.

#### 3.3.3.3 Référence ratiométrique

En parallèle, le même courant Iadc est renvoyé à travers une résistance de référence Rref.

Les extrémités de cette Rref sont connectées à REFP0 et REFN0.

La tension de référence de l’ADC devient donc Vref = Iadc · Rref.

Le système de conversion est ainsi ratiométrique : l’ADC ne fournit pas une tension brute, mais le rapport (Usonde / Vref) = (Rsonde / Rref).

#### 3.3.3.4 Adaptation à différents capteurs

Un multiplexeur permet de sélectionner la valeur de Rref selon la sonde branchée.

Si la sonde est une NTC (forte variation non linéaire), on choisit une Rref adaptée pour garder Usonde dans la plage du PGA.

Si la sonde est une PTC (variation plus régulière), une autre valeur de Rref peut être choisie pour optimiser la résolution.

Le système devient universel : chaque type de sonde est mesuré avec la même précision grâce à l’ajustement de la référence.

#### 3.3.3.5 Conversion numérique

L’ADC sigma-delta effectue la conversion avec suréchantillonnage et filtrage numérique.

La sortie est donc directement proportionnelle au rapport Rsonde / Rref.

La température est ensuite calculée en appliquant la courbe caractéristique de la sonde (linéaire pour les PTC, exponentielle pour les NTC).

#### 3.3.3.6 Configurations des canaux :

Canaux | Idac source | Sonde + | Sonde -
1 | AIN0 | AIN1 | AIN2
2 | AIN3 | AIN4 | AIN5
3 | AIN6 | AIN7 | AIN8
4 | AIN9 | AIN10 | AIN11

### 3.3.4 Commande de l’ADC - Exemple concret – Ni1000 TK5000

#### 3.3.4.1 Paramètres

Rsonde ≈ 935 ohms à -15°C ; 1185.71 ohms à +40°C

Rref = 10000 ohms (sélection via MUX externe)

IDAC = 100 µA injecté sur AIN0

Mesure différentielle AIN1 / AIN2

Gain = 8

OSR = 512 ; OSR = Over Sampling Ratio ; facteur de suréchantillonnage

OSR élevé => plus de précision et moins de bruit, vitesse plus lente

OSR faible => vitesse rapide, plus de bruit et résolution effective réduite

#### 3.3.4.2 But de la procédure

Configurer l’ADC pour exciter la sonde avec l’IDAC, mesurer AIN1 − AIN2 en référence ratiométrique sur REFP0−REFN0, puis lire 24 bits par SPI. Exemple reproductible à adapter en changeant Rref, IDAC et Gain.

### 3.3.5 Séquence SPI exacte (chaque ligne = trame SPI à envoyer)

Rappel : CS_ADC = 0 au début de chaque trame ; CS_ADC = 1 à la fin.

#### 3.3.5.1 RESET du convertisseur

Trame SPI : 06

Remet les registres à leur état par défaut.

#### 3.3.5.2 Sélection du canal différentiel AIN1 / AIN2

Trame SPI : 41 00 12

- 41 = WREG | 0x01 (registre INPMUX)
- 00 = écrire 1 registre
- 12 = MUXP=AIN1, MUXN=AIN2

Mesurer directement aux bornes de la sonde.

#### 3.3.5.3 Référence ratiométrique sur REFP0 / REFN0

Trame SPI : 42 00 00

42 = WREG | 0x02 (registre REFMUX)

00 = écrire 1 registre

00 = REFP=REFP0, REFN=REFN0

Vref = Iadc × Rref ; le rapport annule Iadc.

#### 3.3.5.4 IDAC = 100 µA routé sur AIN0

Trame SPI : 43 00 02

- 43 = WREG | 0x03 (IDACMAG)
- 00 = écrire 1 registre
- 02 = 100 µA

Trame SPI : 44 00 10

- 44 = WREG | 0x04 (IDACMUX)
- 00 = écrire 1 registre
- 10 = IDAC1 vers AIN0

Pourquoi : fixer le courant d’excitation et son point d’injection.

#### 3.3.5.5 Gain = 8 ; OSR = 512

Trame SPI : 45 00 03

45 = WREG | 0x05 (MODE0 / PGA)

00 = écrire 1 registre

03 = Gain 8

Trame SPI : 46 00 0A

46 = WREG | 0x06 (MODE1 / OSR)

00 = écrire 1 registre

0A = OSR 512

Pourquoi : adapter la dynamique et réduire le bruit pour une sonde lente.

#### 3.3.5.6 Démarrer la conversion

Trame SPI : 08

Pourquoi : lancer l’acquisition sigma-delta.

#### 3.3.5.7 Attendre DRDY = 0

Pourquoi : données prêtes ; après une reconfiguration, jeter la première conversion.

#### 3.3.5.8 Lecture 24 bits

Trame SPI : 12 ; puis lire 3 octets de données MSB, MID, LSB

#### 3.3.5.9 Commande du MUX de Rref (externe)

La sélection de la résistance de référence n’est pas réalisée par SPI mais par un multiplexeur analogique TMUX1204 commandé directement par des lignes logiques (ADC_A0 et ADC_A1).

Selon l’état de ces deux entrées, l’une des quatre résistances disponibles est reliée au chemin de référence de l’ADC.

A1 | A0 | Résistance sélectionnée [Ω]
0 | 0 | 2.2k (R14)
0 | 1 | 2.7k (R15)
1 | 0 | 10k (R16)
1 | 1 | 100k (R17)

La commande consiste donc simplement à poser les niveaux logiques corrects sur A0 et A1 depuis le Compute Module 5 pour sélectionner la gamme de mesure adaptée à la sonde.

#### 3.3.5.10 Résultat :

La conversion fournie par l’ADC est un code numérique 24 bits signé.

Comme la mesure est ratiométrique, le résultat correspond directement au rapport entre la résistance de la sonde et la résistance de référence sélectionnée.

Formule :

- Rsonde=((CodeADC)/(FullScale))×Rref
- avec FullScale = 2^23 (valeur maximale pour 24 bits signé).

La présence du courant IDAC s’annule dans le rapport, car il traverse à la fois la sonde et la résistance de référence.

### 3.3.6 Fiche de calcul ADC

Pour valider le dimensionnement de l’ADC, j’ai établi une fiche de calcul permettant de vérifier les plages de mesure en fonction des paramètres configurables.

Les points de contrôle de la mesure sont les suivants :

- R à -15[°C]
  - Description : résistance de la sonde à -15°C.
  - Formule : valeur issue du CdC (non calculée).
  - Limites : utiliser la valeur extrême avec tolérance si fournie.
- R à +40[°C]
  - Description : résistance de la sonde à +40°C.
  - Formule : valeur issue du CdC (non calculée).
  - Limites : utiliser la valeur extrême avec tolérance si fournie.
- Rref [Ω]
  - Description : résistance de référence connectée via le MUX au bloc REFP0/REFN0 de l’ADC.
  - Formule : valeur matérielle (2.2k, 2.7k, 10k, 100k).
  - Limites : Vref = IDAC × Rref doit rester entre 0.3 V et 2.5 V.
- IDAC [µA]
  - Description : courant d’excitation fourni par l’ADC pour traverser la sonde et Rref.
  - Formule : valeur discrète parmi {10, 50, 100, 250, 750, 1000, 1500, 2000}.
  - Limites : vérifier Vinj_max < AVDD − 0.4 V et limiter l’auto-échauffement (Psonde = I² × Rsonde).
- Gain
  - Description : gain du PGA interne appliqué à la tension différentielle sonde.
  - Formule : valeur programmée parmi {1, 2, 4, 8, 16, 32, 64, 128}.
  - Limites : condition Vsonde_max < Vref / Gain.
- V @ Tmin mesurée [V]
  - Description : tension aux bornes de la sonde à -15°C.
  - Formule : Vsonde_min = IDAC × R(-15°C).
  - Limites : doit être au-dessus du bruit ADC.
- V @ Tmax mesurée [V]
  - Description : tension aux bornes de la sonde à +40°C.
  - Formule : Vsonde_max = IDAC × R(+40°C).
  - Limites : doit rester < Vref / Gain.
- Vref [V]
  - Description : tension de référence ratiométrique appliquée à l’ADC.
  - Formule : Vref = IDAC × Rref.
  - Limites : 0.3 V ≤ Vref ≤ 2.5 V.
- Vnode max [V]
  - Description : tension maximale au nœud d’injection IDAC (somme Vsonde_max + Vref).
  - Formule : Vnode_max = Vsonde_max + Vref.
  - Limites : doit être < AVDD − 0.4 V.
- FS_ADC
  - Description : demi-pleine échelle effective du convertisseur après PGA.
  - Formule : FS_ADC = Vref / Gain.
  - Limites : borne supérieure de la tension différentielle de la sonde.
- DV [V]
  - Description : amplitude de variation de la tension sonde entre -15°C et +40°C.
  - Formule : DV = Vsonde_max − Vsonde_min.
  - Limites : doit exploiter une part significative de FS_ADC.
- Dvout [V]
  - Description : amplitude en sortie du PGA sur la plage de température.
  - Formule : Dvout = Gain × DV.
  - Limites : doit rester < Vref pour ne pas saturer.
- Amplitude numérique [V]
  - Description : amplitude équivalente en pleine échelle numérique après conversion.
  - Formule : Amplitude = (DV / FS_ADC) × Vref.
  - Limites : cohérente avec l’échelle 2^23 codes.
- Utilisation de la plage ADC [%]
  - Description : pourcentage de la pleine échelle utilisé par DV.
  - Formule : Utilisation = 100 × DV / FS_ADC.
  - Limites : viser entre 60 % et 95 %.
- Résolution réelle en [°C]
  - Description : variation de température correspondant à un code ADC.
  - Formule : Résolution = ΔT / Codes_DV avec ΔT = 46.5 °C.
  - Limites : plus petit = meilleure résolution ; éviter > 0.001 °C/code.
- Taux de variation numérique par [°C]
  - Description : nombre de codes ADC par degré Celsius.
  - Formule : Codes_par_°C = Codes_DV / ΔT avec ΔT = 46.5 °C.
  - Limites : viser > 80 000 codes/°C pour assurer une bonne précision.
- P @ Tmin mesurée
  - Description : puissance dissipée dans la sonde à -15°C.
  - Formule : P = IDAC^2 × R(-15°C).
  - Limites : doit rester faible pour éviter l’auto-échauffement.
- P @ Tmax mesurée
  - Description : puissance dissipée dans la sonde à +40°C.
  - Formule : P = IDAC^2 × R(+40°C).
  - Limites : doit rester faible pour éviter l’auto-échauffement.
- Déviation min en [°C]/mW
  - Description : élévation de température estimée par mW dissipé à -15°C.
  - Formule : ΔT/Pmin = valeur constructeur ou calculée.
  - Limites : vérifier que l’élévation reste négligeable (<0.1°C).
- Déviation max en [°C]/mW
  - Description : élévation de température estimée par mW dissipé à +40°C.
  - Formule : ΔT/Pmax = valeur constructeur ou calculée.
  - Limites : vérifier que l’élévation reste négligeable (<0.1°C).

#### 3.3.6.1 Résultat de la fiche de calcul

Les calculs confirment que toutes les sondes sont exploitables dans l’architecture.

La De Dietrich AF60 et la NTC 2k 3390 exploitent près de 40 % de la plage ADC et offrent la meilleure précision avec plus de 70 000 codes/°C. La NTC 10k 3977 suit avec 33 % de plage et 60 000 codes/°C.

Les NTC 1k 3528 et 2.2k 3528 utilisent environ 23 % de la plage et donnent une résolution correcte autour de 42 000 codes/°C. La KTY81-210 atteint 16 % et reste dans une zone intermédiaire avec 30 000 codes/°C.

Les PT1000, Ni1000 TK5000, Ni1000 TK6180 et Siemens QAC32 n’exploitent que 8 à 12 % de la plage. Leur résolution chute entre 15 000 et 22 000 codes/°C, mais reste utilisable.

l’ensemble des sondes est conforme au CdC, mais la précision varie fortement selon le modèle. Les PTC type PT1000 ou Ni1000 offrent une précision plus faible, tandis que certaines NTC et l’AF60 exploitent pleinement l’ADC et garantissent une meilleure finesse de mesu

## 3.4 Bloc Etage I/O 3V3-24V

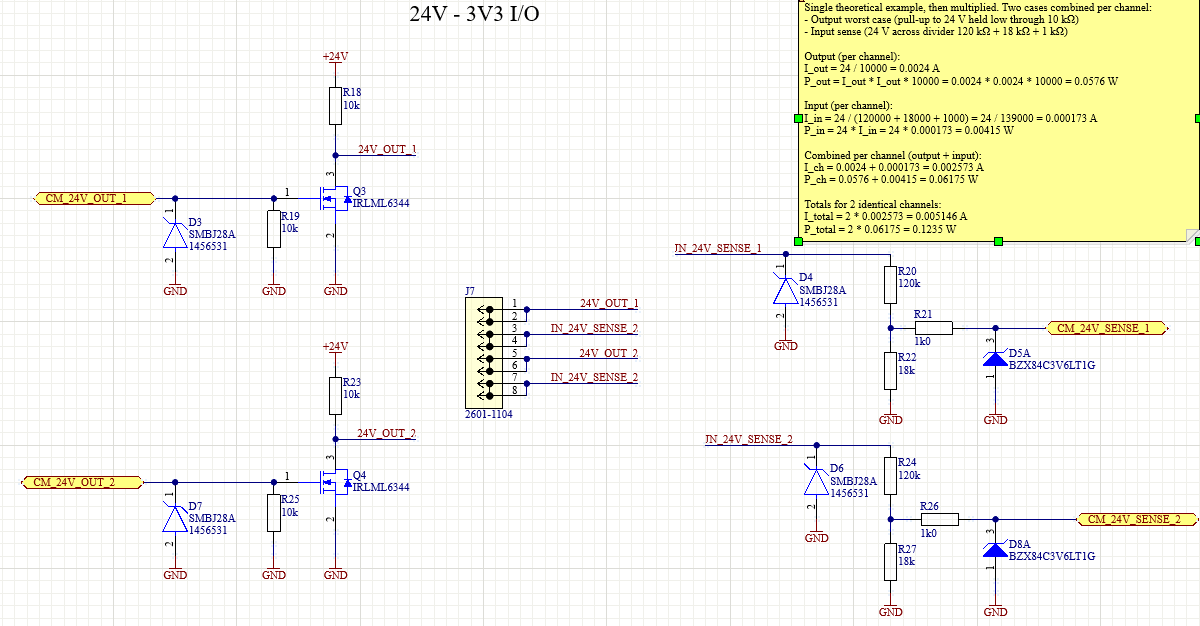
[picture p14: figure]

Figure 22

Le cahier des charges impose la mise en place d’un système capable de détecter l’état d’un contact sec issu d’installations de particuliers. Un exemple typique est la signalisation d’une surproduction solaire. La lecture de cet état permet au système de déterminer si une modification des paramètres transmis à la chaudière peut être appliquée (par exemple réduire la demande de chauffage).

Le principe retenu est le suivant :

chaque canal délivre un niveau +24[V] à travers une résistance de pull-up. Ce +24[V] traverse le contact sec externe.

Lorsque celui-ci est fermé, la ligne est reliée à la masse via le MOSFET N canal (IRLML6344) en bas de ligne. Le CM5 lit alors un état bas.

Lorsque le contact est ouvert, la ligne reste à +24[V] via la résistance de pull-up et l’information est ramenée vers l’entrée logique du CM5 grâce au diviseur de tension et aux circuits de protection.

Équations de dimensionnement – Étage de sortie

- I_(pullup) =(V_24)/(R_(pullup))=24/10000=2.4[mA]
- P_(pullup) =V_24 ⋅I_(pullup) =24⋅0.0024=57.6[mW]
- P_(MOS) =I_(pullup)^2 ⋅R_(ds_on) =(0.0024)^2 ⋅0.05=0.00029[mW]

Équations de dimensionnement - Diviseur résistif

- V_(CM) =V_(in) ⋅(R_(bas))/(R_(haut) +R_(bas))=24⋅18000/(120000+18000)=3.1304[V]
- I_(div) =(V_(in))/(R_(haut) +R_(bas))=24/(120000+18000)=0.1739[mA]
- P_(R_(haut)) =I_(div)^2 ⋅R_(haut) =(0.0001739)^2 ⋅120000=3.63[mW]
- P_(R_(bas)) =I_(div)^2 ⋅R_(bas) =(0.0001739)^2 ⋅18000=0.54[mW]

Équations de dimensionnement - Limitation série et zener

- I_(zener,max) =(V_(in) -V_(zener))/(R_s)=(24-3.6)/1000=0.0204[A]
- P_(R_(s,max)) =I_(zener,max)^2 ⋅R_s =(0.0204)^2 ⋅1000=0.416[W]

Bilan consommation par canal

- I_(canal) =I_(pullup) +I_(div) =0.0024+0.0001739=0.002574[A]
- P_(canal) =P_(pullup) +(V_24 ⋅I_(div) )=0.0576+(24⋅0.0001739)=0.06177[W]

Bilan pour deux canaux

- I_(total) =2⋅I_(canal) =2⋅0.002574=0.005148[A]
- P_(total) =2⋅P_(canal) =2⋅0.06177=0.12354[W]

## 3.5 Carte fille

### 3.5.1 Relais de bypass

Figure 23

Le cahier des charges impose que les sondes puissent être directement reliées à la chaudière, même si le système électronique n’est plus alimenté ou si le firmware décide de désactiver la logique interne. La fonction by-pass garantit donc la continuité de service :

la chaudière doit toujours disposer d’une information exploitable, sans dépendre de l’électronique. Pour cela, l’approche retenue est l’utilisation de relais double contact TQ2-5V-3.

Par défaut (hors tension), les relais connectent directement SENSOR_IN± vers BYPASS_OUT+/- puis BOILER_IN+/-.

Lorsque le système est actif, les relais sont excités et ouvrent ces connexions pour connecter l’ADC (entrée) et l’étage de simulation (sortie). Deux relais distincts assurent la séparation stricte de la voie entrée et de la voie sortie afin d’éviter tout couplage ou influence croisée.

Principe a deux bypass :

- Le by-pass en entrée est nécessaire pour garantir que la sonde puisse toujours être connectée directement à la chaudière. Cela assure que, même si l’électronique tombe en panne ou est hors tension, la chaudière continue de recevoir une valeur réelle de température et peut fonctionner de manière autonome. De plus cela protèges le bloc adc de courant ou tension induit par la chaudière pour ça mesures.
- Le by-pass en sortie est indispensable pour isoler l’étage de simulation. En mode actif, le système doit pouvoir remplacer la sonde par une résistance simulée. En mode passif, cette simulation doit être totalement retirée du circuit pour ne pas influencer la mesure réelle.

Les deux by-pass évitent ainsi que l’ADC ou le réseau de simulation interfèrent avec la chaudière ou la sonde lorsque le système est inactif. L’indépendance des deux relais est donc essentielle pour garantir la sécurité, la fiabilité et la conformité fonctionnelle demandée par le cahier des charges.

Composants

- Relais TQ2-5V-3 : bobine 5[V], Rcoil ≈ 178[Ω].
- MOSFET IRLML2402 en low-side pour piloter chaque bobine.
- Résistances de grille (R66, R67 = 100[Ω]) pour contrôler la vitesse de commutation.
- Pull-down grille (R69, R71 = 100k[Ω]) pour garantir l’état OFF au repos.
- Diodes SS14 en roue libre pour dissiper l’énergie de la bobine.
- ESD SP1002 pour protéger les lignes exposées.
- Commande CMD_RELAY issue du CM5 pour activer ou désactiver les relais.

Dimensionnement bobine et MOSFET

- I_(coil) =(V_(coil))/(R_(coil))=5.0/178=0.0281[A]=28.1[mA]
- P_(coil) =V_(coil) ⋅I_(coil) =5.0⋅0.0281=0.1405[W]=140.5[mW]
- P_(MOS) =I_(coil)^2 ⋅R_(ds_on) =0.0281^2 ⋅0.08=0.000063[W]=0.063[mW]

Courant de grille et temps de commutation

- I_(g,peak) =(V_(cmd))/(R_g)=3.3/100=0.033[A]=33[mA]
- t_(commutation) =(Q_g)/(I_(g,peak))=(3.0⋅10^(-9))/0.033=9.09⋅10^(-8) [s]=0.0909[μs]

Totaux pour deux relais (entrée et sortie)

- I_(total) =2⋅I_(coil) =2⋅28.1=56.2[mA]
- P_(total) =2⋅P_(coil) =2⋅140.5=281.0[mW]

### 3.5.2 MUX

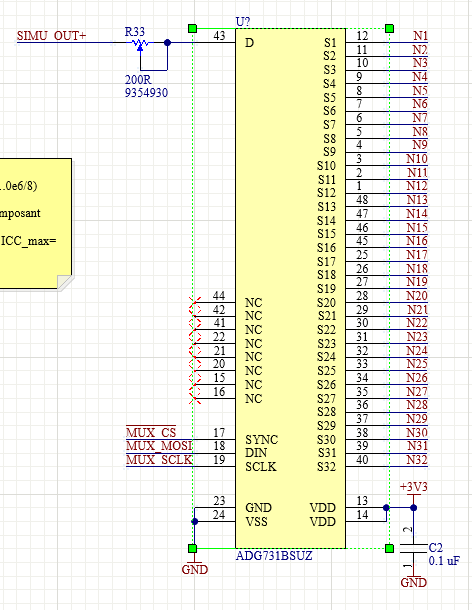
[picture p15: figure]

Figure 24

La simulation doit reproduire à un instant donné la valeur résistive perçue par la chaudière pour l’influencer à chauffer ou à ne pas chauffer.

Le réseau de résistances est composé de 32 points. Jusqu’à 4 cartes filles peuvent être installées pour gérer 4 sondes distinctes.

La sélection d’un point doit être rapide, propre et avec une charge parasite minimale sur le réseau.

Le MUX choisi est l’ADG731BSUZ, un multiplexeur 32:1 commandé en série par interface SPI.

Il présente une résistance ON faible, ce qui limite l’erreur de simulation et permet une stabilisation rapide du signal.

La communication se fait directement par SPI :

- DIN : données série transmises bit par bit.
- SCLK : horloge série définissant le rythme des transferts.
- SYNC : validation de la trame (actif bas).

Lorsqu’un mot de commande de 6 bits est envoyé via SPI, il définit le canal actif :

- Bits A4 à A0 : adresse du canal sélectionné, de S1 à S32.
- Bit EN : activation ou coupure complète du multiplexeur (EN = 0 : voie active, EN = 1 : toutes voies coupées).

Exemple de sélection du canal S17 :

- L’adresse binaire correspondante est 10000 (valeur décimale 16).
- Le mot de commande 6 bits est donc : A4..A0 = 10000, EN = 0.
- Aligné sur 8 bits pour envoi SPI : 00010000 (0x10).

Séquence d’envoi SPI :

1. Placer SYNC = 0 pour indiquer le début de trame.
2. Envoyer l’octet 0x10 sur DIN avec SCLK.
3. Remettre SYNC = 1 pour valider la trame.

Résultat :

Le canal S17 est connecté à la sortie D, et il le restera jusqu’à la prochaine trame SPI.

Cette architecture simplifie considérablement la gestion firmware par rapport aux solutions parallèles : un seul mot SPI suffit à sélectionner un canal, sans besoin de registre intermédiaire.

### 3.5.3 Réseau de résistance.

Figure 25

Le réseau de résistances est défini à partir d’un fichier Excel fourni par l’entreprise mandataire « Oblo ».

Ce document interne constitue la base de conception des cartes filles.

En fonction du type de sonde utilisée, les valeurs des résistances sont choisies de manière à obtenir la meilleure résolution possible sur la courbe de température simulée.

Figure 26

Le réseau de résistances correspond de manière quasi parfaite aux valeurs caractéristiques de chaque type de sonde.

Cependant, c’est principalement le système de chauffage qui peut s’attendre à des valeurs légèrement différentes en raison de ses propres tolérances et conditions de fonctionnement.

Le potentiomètre en série permet donc de réaliser un ajustement fin afin d’adapter la réponse du simulateur aux attentes réelles du système, par exemple en compensant la résistance des câbles.

Cet élément offre à l’opérateur la possibilité de calibrer précisément chaque installation

## 3.6 Évaluations des coûts

### 3.6.1 Estimations prix composant

L’estimations des prix par composant est disponible en annexe au point : XX

### 3.6.2 Prix PCBs

PCB | Manufacturer | QTY 1 | QTY 10 | QTY 100
Motherboard | Eurocircuit | 81,5 | 282,47 | 990,2
Dautherboard | Eurocircuit | 53,13 | 140 | 512,39

### 3.6.3 Somme des estimations par quantité commandée

Board | Total 1 complete board | Total 10 complete board | Total 100 complete board | Price per unit if 1 ordered | Price per unit if 10 ordered | Price per unit if 100 ordered
Motherboard | 240,38554 | 1704,96508 | 14375,84323 | 240,38554 | 170,496508 | 143,7584323
Daughterboard | 86,18203 | 392,89053 | 2586,5 | 86,18203 | 39,289053 | 25,865

Nbr Daughterboards | Lot total 1 set with MB | Lot total 10 set with MB | Lot total 10000 set with MB | price per set 1 | price per set 10 | price per set 100
1 | 326,57 | 2097,86 | 16962,34 | 326,57 | 209,786 | 169,6234
2 | 412,75 | 2490,75 | 19548,84 | 412,75 | 249,075 | 195,4884
3 | 498,93 | 2883,64 | 22135,34 | 498,93 | 288,364 | 221,3534
4 | 585,11 | 3276,53 | 24721,84 | 585,11 | 327,653 | 247,2184

# 4 Routage PCB

## 4.1 Limitations mécaniques du boitier :

Le projet dispose déjà de pièces mécanique attitrée :

1. Une plaque en métalique surlaquelle le système actuelle est monté.
2. Un couvercle avec un enfoncement pour la led d’affichage avant.

### 4.1.1 Plaque de montage

Figure 27

Cette devra réceptionner l’ensemble partie électroniques du systèmes. Comprenant la carte mère, les carte filles, l’alimentation DC/DC et les câbles.

Le mandant, M. Graff, m’a confirmé que les trous n’avaient pas besoin de conserver leur position actuelle. Je peux donc les repercer ou les supprimer selon ce qui me semble adéquat.

Un point reste toutefois important : il faut conserver un espace accessible après le montage des PCB et du module d’alimentation afin de prévoir des trous larges pour la fixation murale.

Pour permettre un meilleurs visualisions mécanique , j’ai créé un modèle 3d respectant les dimension de mon projets.

### 4.1.2 Couvercle OBLO

Le couvercle OBLO prend cette forme :

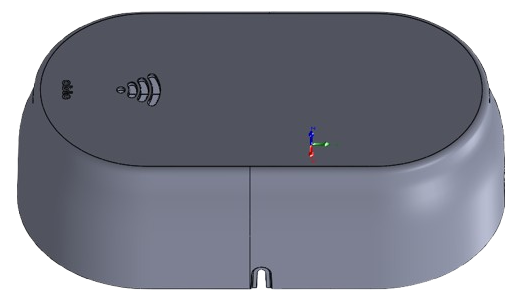
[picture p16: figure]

Figure 28 – Couvercle Oblo Base

A partir de ce modèle 3D, via solidworks, j’ai pu mesurer ces dimension de la partie haute du boitier ainsi que du positionnement du renfoncement de la LED avant.

Figure 29 – Dimension mesurée du haut du boitiers

## 4.2 Logique mécanique :

Le placement des composants dépendra des pièces mécaniques.

Le principe sera le suivant :

- La carte mère sera montée directement à la plaque métallique, via des entretoises métalliques de 10[mm].
- Les carte filles seront connectée verticalement à la carte mère.
- L’alimentation AC/DC se trouvera sur le haut du PCB.
- Le routage des câbles sera pris en compte.

## 4.3 Taille des PCBs

### 4.3.1 PCB fille

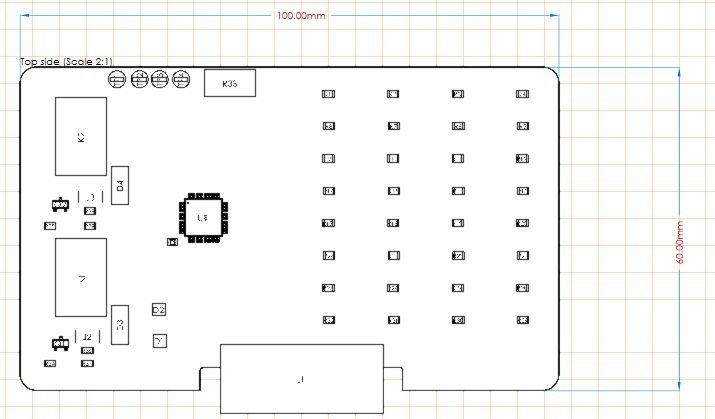
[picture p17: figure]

Figure 30

### 4.3.2 PCB mère

Figure 31

## 4.4 Test assemblage

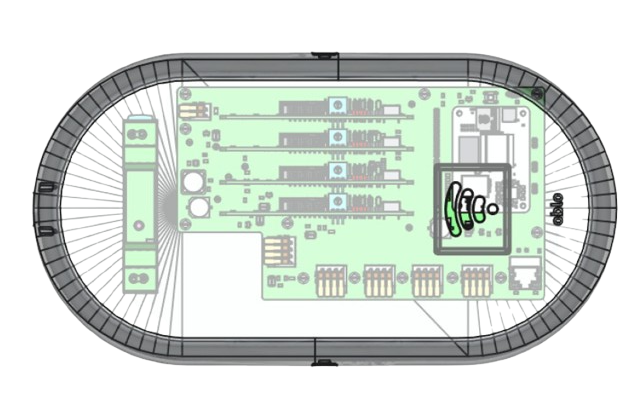
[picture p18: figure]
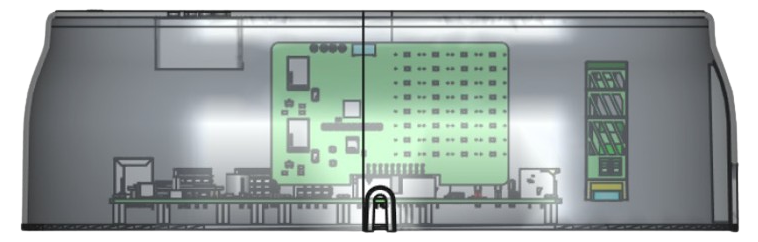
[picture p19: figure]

Figure 32

Le test d’assemblage confirme la bonne implémentation mécanique des PCB et confirme son fonctionnement.

## 4.5 Placement des composant :

### 4.5.1 Carte fille

Figure 33

### 4.5.2 Carte mère

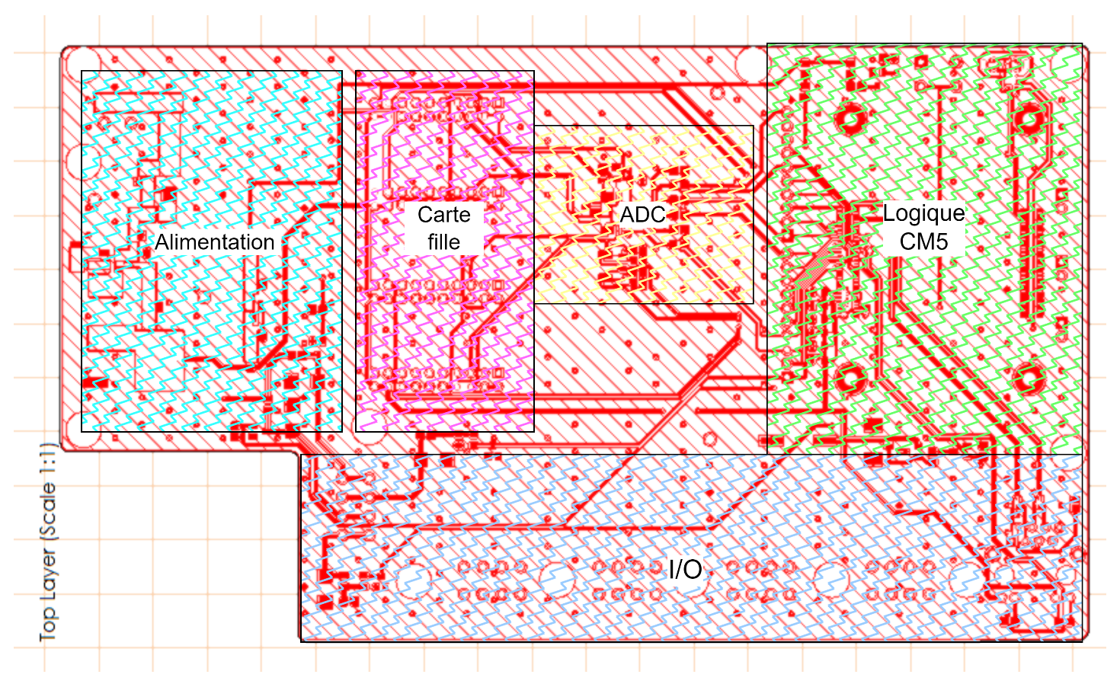
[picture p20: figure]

Figure 34

## 4.6 Routage des pistes

### 4.6.1 Carte fille

#### 4.6.1.1 Alimentations 3V3

Figure 35

Le routage ne crée pas de boule de courant.

#### 4.6.1.2 Alimentation 5V

Le routage ne crée pas de boule de courant.

#### 4.6.1.3 GND

Le GND est constitué de deux plans de masse se trouvant sur la couche Bottom et top du PCB.

#### 4.6.1.4 Autre

Les footprint des résistances du réseau sont composé de leur modèle THT et SMD afin de respeecter la demande du mandataire de pouvoir monter ces deux types de systèmes.

Figure 36

### 4.6.2 Carte mère

#### 4.6.2.1 Alimentations 24V

Figure 37

#### 4.6.2.2 Alimentation 5V

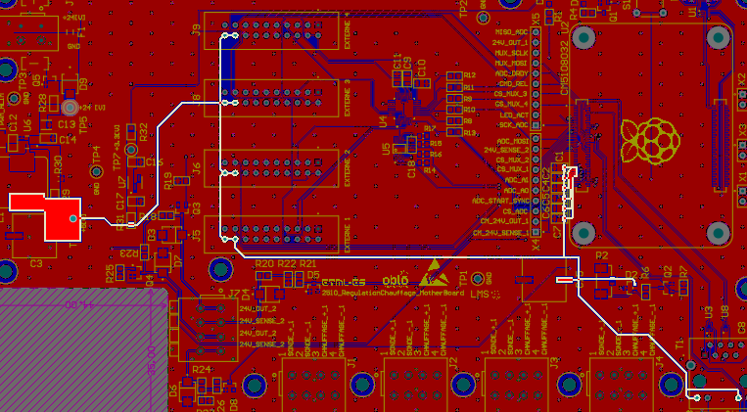
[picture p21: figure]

Figure 38

#### 4.6.2.3 Alimentations 3V3

Figure 39

#### 4.6.2.4 Bloc alimentation Buck-down

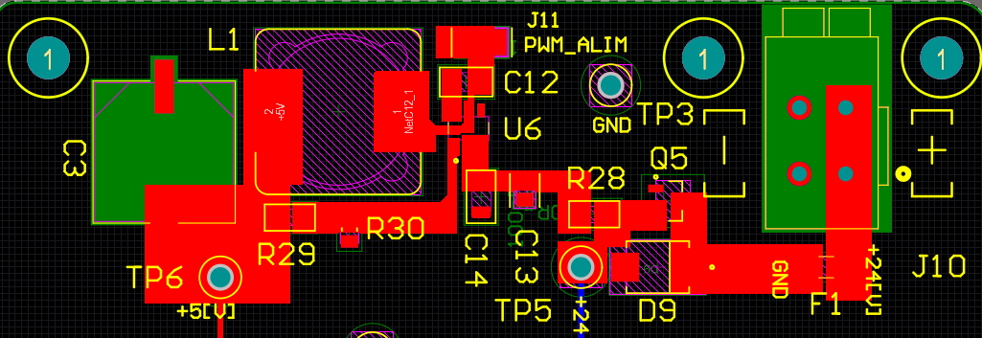
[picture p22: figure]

Figure 40

Les pistes des alimentations de la partie Buck-down on été effectuée sous forme de plans d’alimentations afin de permettre une meilleur abosrtion des pic de courants gran et une meilleur connections.

#### 4.6.2.5 Bloc d’alimentation LDO

Figure 41

#### 4.6.2.6 GND

Le GND est constitué de deux plans de masse se trouvant sur la couche Bottom et top du PCB.

#### 4.6.2.7 Paire différentielle

Sur notre projet nous auront deux canaux de communication qui nécessite des paires différentielles. Il s’agit de l’USB et les paires Ethernets. Le principe de paire différentiel permer d’annuler les interférence electromagnétique et minimiser la diaphonie.

Dans noter cas uen impédence controllée de 100[Ω] sera chosiie pour ces lignes.

##### 4.6.2.7.1 Règles pour l’impédance contrôlée de 100[Ω]

Cette impédance est réglée dans les paramètres du layer stack manager. Dans celui-ci, on définit une impédance pour les layers "top et bottom". En entrant les paramètres principaux, altium calculera les dimensions des lignes.

Layer stack :

Figure 42

Une fois cette impédance déclarée, il faut paramétrer les règles liées aux lignes différentielles en y mettant comme profils d’impédances paramétrés précédemment. Et ceux pour chaque paire différentielle.

Figure 43

##### 4.6.2.7.2 Lignes différentielles paires ethernets

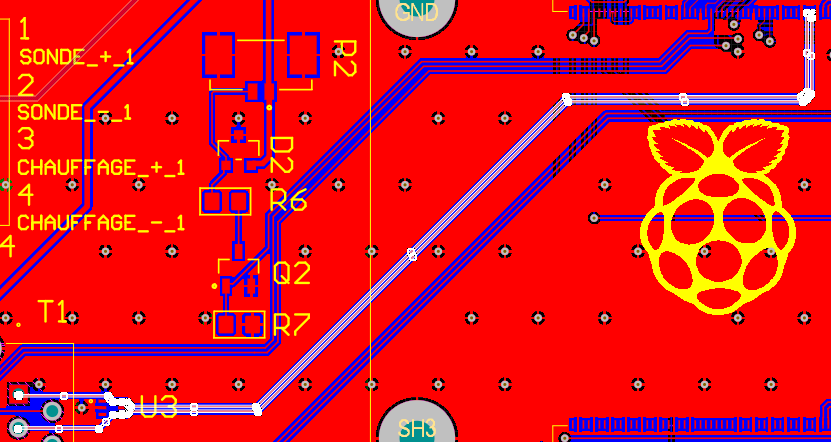
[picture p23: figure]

Figure 44 Paire TD

Figure 45 Paire RD

##### 4.6.2.7.3 Lignes différentielles USB 2.0

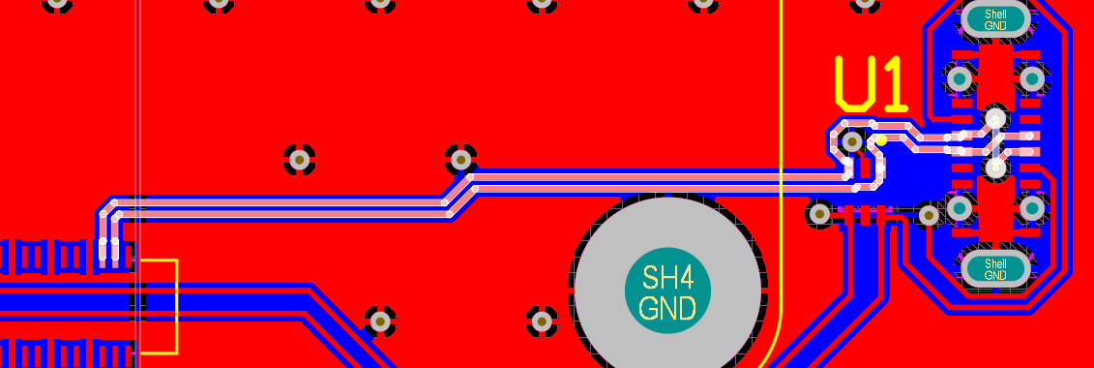
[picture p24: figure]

Figure 46

## 4.7 Support mécanique

Les connecteurs utilisés ont une grande contrainte mécanique nécessitant des fixation proches et complètes. Au vu du projet et de cette nécessité, j’ai pris la décision de plaçés des trous de fixation au plus proche des connecteurs.

Figure 47

## 4.8 PCB layout

### 4.8.1 Carte fille

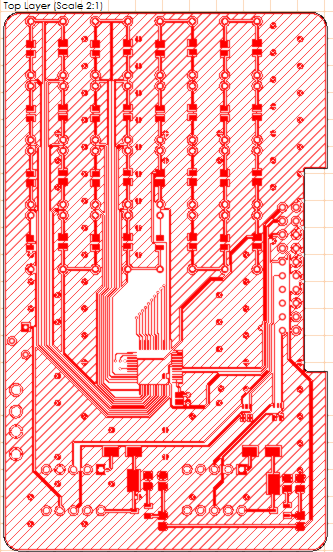
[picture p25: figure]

Figure 48

### 4.8.2 Carte mère

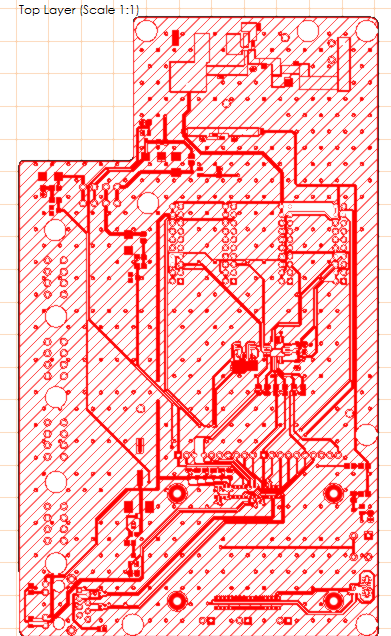
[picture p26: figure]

Figure 49

## 4.9 3D

### 4.9.1 Carte fille

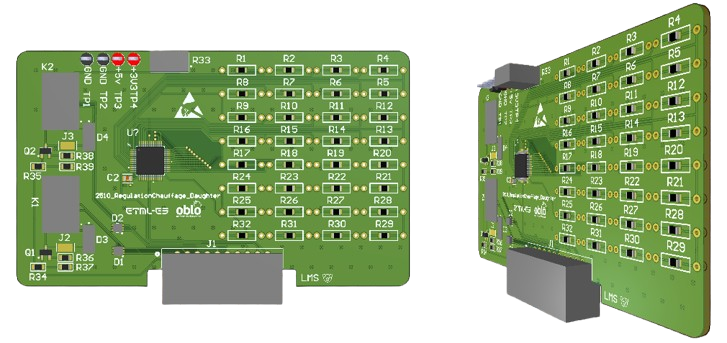
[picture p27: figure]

Figure 50

### 4.9.2 Carte mère

Figure 51

## 4.10 Routage des câbles

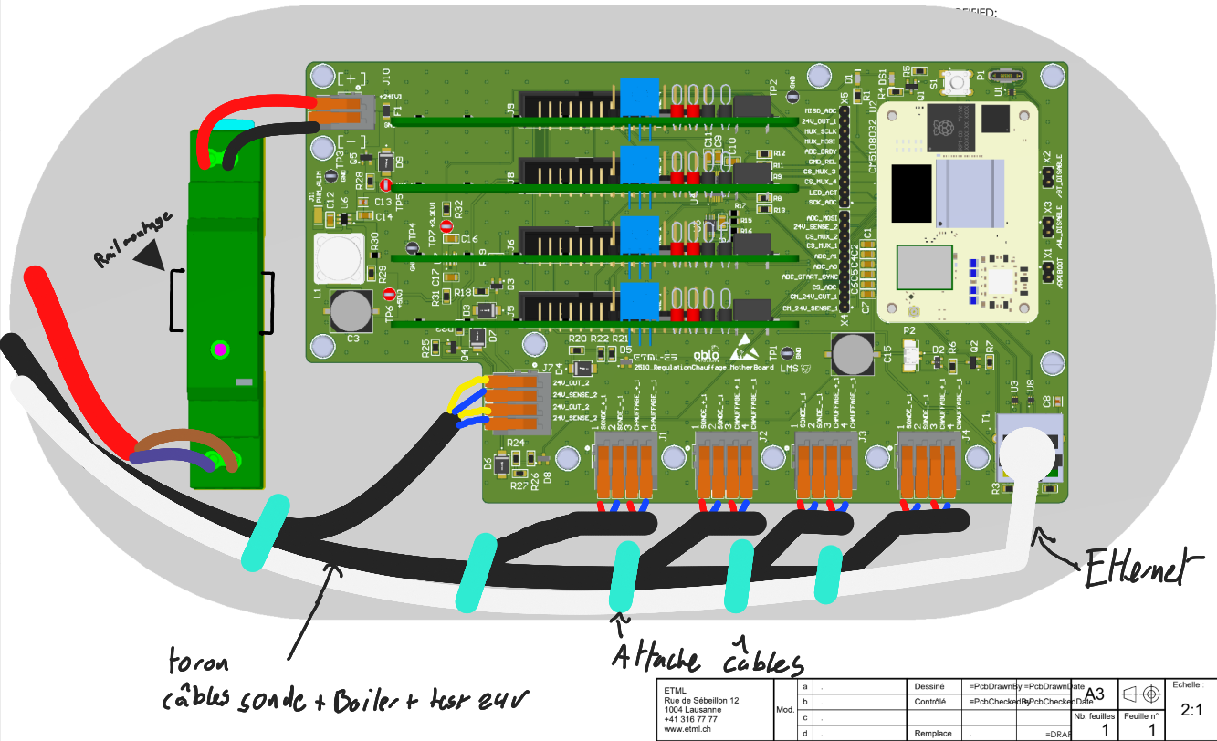
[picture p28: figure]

Figure 52

# 5 Mise en service

## 5.1 Erreur ou problème de montage

### 5.1.1 USB type C

L’USB type C utilisé nécessite une grande précision de brasage. Il devait obligatoirement être monté au moyen d’un stencil et d’un brasage au four.

Les équipements disponibles ne m’ont pas permis de réaliser un brasage convenable, ce qui a conduit à un court-circuit non visible entre la ligne CC2 et USB_P.

Figure 53

Afin de réparer ces lignes, un démontage complet du connecteur était nécessaire. Au moyen d’une plaque de chauffe, j’ai tenté de débraser le connecteur, mais à mon grand désarroi, les pistes qui y étaient connectées se sont arrachées. Cela provient vraisemblablement de la faible largeur des pistes de 0.2 mm, d’une force mécanique exercée trop élevée et d’une surchauffe de la région du PCB.

Les corrections sur ce PCB s’avérant complexes, j’ai pris la décision de ré-effectuer cette partie du montage sur le second PCB en ne remontant uniquement les connectiques de la CM5 et l’USB C afin de prouver la fonctionnalité de flashage du système. Cette fonctionnalité ayant déjà été validée au moyen d’une carte CM5IO, elle n’est pas prioritaire dans mon projet et sera démontrée avant la défense orale.

Une modifications sera nécessaires afin de garantir le bon fonctionnement et la robustesse des future itérations du projets.

## 5.2 Mesure alimentation Buck 5[V]

### 5.2.1 But de la mesure

Mesurer et confirmer que le bloc alimentations Buck fournisse une tension de 3V3, non bruitée sans et avec charge.

### 5.2.2 Schéma de mesure

### 5.2.3 Méthode de mesure

### 5.2.4 Résultat de mesure

## 5.3 Mesure alimentation LDO 3.3[V]

### 5.3.1 But de la mesure

Mesurer et confirmer que le bloc LDO fournisse une tension de 3V3, non bruitée sans et avec charge.

### 5.3.2 Schéma de mesure

### 5.3.3 Méthode de mesure

### 5.3.4 Résultat de mesure

## 5.4 Mesure consommations

### 5.4.1 But de la mesure

Mesurer la consomation du projets sous différente configurations afin de garantir que les alimentions ne sont pas surchargée.

Comparer ces résultat au valeur estimée en point XX

### 5.4.2 Schéma de mesure

### 5.4.3 Méthode de mesure

### 5.4.4 Résultat de mesure

## 5.5 Mesure test SPI LM70

### 5.5.1 But de la mesure

Dans l’attente des PCB, j’ai effectué un test de communications SPI entre le CM5 et un capteur LM70 se trouvant sur uen carte de développement PIC32 de l’etml ES. L’objectif de ce test étant de confirmer la bonne configurations du spi sur le CM5. Les paramètre nécessaires avant de pouvoir développer cette communications sur la carte finale.

### 5.5.2 Schéma de mesure

### 5.5.3 Méthode de mesure

### 5.5.4 Résultat de mesure

# 6 Firmware

## 6.1 Flash du CM5.

Afin de pouvoir utiliser le CM5, il m’a fallu le flasher avec un OS.

Mes PCB n’ayant pas encore été reçus au moment de cette mise en place. La carte CM5IO fut utiliser. Celle-ci permettant de fournir un accès au IO de celui-ci via des connecteur spécifique permettant entre autres d’effectuer le flashage du système via RPIBOOT et de pouvoir travailler sur le CM5 par SSH. Et ainsi effectuer les test SPI définit en point XX.

La mise en place de l’OS via RPIboot est décrite en annexe dans le mode d’emplois page XX

## 6.2 Configuration

# 7 Modifications

- USB-C
- Ajout d’un test de présence de carte hardware

# 8 Conclusion

## 8.1 Résultat

### 8.1.1 Mesure par infrarouge

### 8.1.2 Avancement du firmware

## 8.2 Analyse du produit obtenu d’un point de vue durabilité

### 8.2.1 Aspects environnementaux

### 8.2.2 Sociaux.

### 8.2.3 Économiques

## 8.3 Remarques du projet

8.3 Remarques du projet

# 9 Signature

Lausanne, le

# 10 Annexe

## 10.1 Annexe rapport de projet

### 10.1.1 Calculateur Convertisseur buck down :

### 10.1.3 Estimations de prix

#### 10.1.3.1 Composants carte mère :

Name | Description | Designator | Quantity | Manufacturer 1 | Supplier 1 | Supplier Part Number 1 | Supplier Unit Price 1 QTY 1 | Supplier Subtotal QTY 1 | Supplier Unit Price 1 QTY 10 | Supplier Subtotal 1 QTY 10 | Supplier Unit Price 1 QTY 100 | Supplier Subtotal 1 QTY 100
Raspberry Pi SC1570 | Ordinateur monocarte 2,4GHz 4 Cœur 8Go/0Go RAM ARM® Cortex®-A76 | U2(Externe)1 | 1 | Raspberry Pi | Newark | 20AM3761 | 80 | 80 | 80 | 800 | 81,69 | 7,78
ADS124S08IPBSR | IC ADC 24BIT SIGMA-DELTA 32LQFP | U4 | 1 | Texas Instruments | DigiKey | 296-45170-1-ND | 11,78 | 11,78 | 9,24 | 92,37 | 7,91 | 412
CONN JACK 1PORT PCB | 1 Port RJ45Trou traversant 10/100 Base-T, AutoMDIX | T1 | 1 | Bel Fuse | DigiKey | 5923-SI-46001-F-ND | 5,25 | 5,25 | 4,46 | 44,64 | 3,79 | 8,64
SC1752 | RASPBERRY PI CM5 PASSIVE COOLER | U2(Externe)1 | 1 | Raspberry Pi | DigiKey | 2648-SC1752-ND | 5 | 5 | 5 | 50 | 5 | 87,08
629712010214 | USB 2.0 Type C Plug Vertical SMT | P1 | 1 | Wurth Elektronik | DigiKey | 732-629712010214CT-ND | 4,55 | 4,55 | 4,35 | 43,5 | 4,12 | 39,47
2601-1104 | Description | J1, J2, J3, J4, J7 | 5 | WAGO | Farnell | 4126048 | 3,56 | 17,79 | 3,38 | 169,15 | 2,77 | 45
CM5108032 | | U2 | 1 | Amphenol Communications Solutions | DigiKey | 609-10164227-1004A1RLFCT-ND | 2,55 | 2,55 | 2,16 | 21,63 | 1,84 | 48
second connector CM5 | | U2-21 | 1 | Amphenol Communications Solutions | DigiKey | 609-10164227-1004A1RLFCT-ND | 2,55 | 2,55 | 2,16 | 21,63 | 1,84 | 1,9
LMR51625XFDDCR | Abaisseur de tension Régulateur à découpage IC Positif Réglable 0,8V 1 Sortie 2,5A SOT-23-6 mince, TSOT-23-6 | U6 | 1 | Texas Instruments | DigiKey | 296-LMR51625XFDDCRCT-ND | 2,03 | 2,03 | 1,5 | 15 | 1,22 | 33,83
2601-1102 | Description | J10 | 1 | WAGO | Farnell | 4126046 | 1,92 | 1,92 | 1,92 | 19,17 | 1,69 | 1,69
2.54 | JUMPER 2.54 1x02 | X1, X2, X3 | 3 | Wurth Elektronik | Mouser | 710-61303611121 | 1,38 | 4,14 | 0,81898 | 24,57 | 0,73873 | 0,5
SP0502BAHTG | TVS DIODE 5.5V 8.5V SOT23-3 | D2 | 1 | Littelfuse | Farnell | 1827631 | 0,70165 | 0,70165 | 0,51747 | 5,17 | 0,39468 | 0,5
TPD4E1U06DCKR | Quad 0.8-pF, 5.5-V, Â±15-kV ESD protection diode in SOT-23 & SC70 packages 6-SC70 -40 to 125 | U1, U3, U8 | 3 | Texas Instruments | DigiKey | 296-39347-1-ND | 0,58 | 1,74 | 0,357 | 10,71 | 0,227 | 0,8
ERB-RG1R25V | Micro Chip Fuse, Size [LÃ—W] (EIA) (mm): 3.2Ã—1.6 (EIA:1206) , Rated Current (A): 1.25, Internal R [at 25â„ƒ max.] (mâ„|): 175, Rated Voltage (Open Circuit Voltage) [DC] (V): 63, Interrupting Rating (A): 50, Category Temp. Range (Â°C): -40 to +125 | F1 | 1 | Panasonic | DigiKey | P16737CT-ND | 0,58 | 0,58 | 0,439 | 4,39 | 0,3364 | 0,45617
47 uF | CAP ALUM 47UF 20% 50V SMD | C3, C15 | 2 | Panasonic | Farnell | 1868425 | 0,57134 | 1,14 | 0,57134 | 11,43 | 0,32326 | 1,1
TMUX1204DGSR | MULTIPLEXER | U5 | 1 | Texas Instruments | Mouser | 595-TMUX1204DGSR | 0,57 | 0,57 | 0,41 | 4,1 | 0,3199 | 2,04
53398-0271 | Male Header, Pitch 1.25 mm, 1 x 2 Position, Height 4.7 mm, -40 to 8 5 degC, RoHS, Tape and Reel | P2 | 1 | Molex | DigiKey | WM7606CT-ND | 0,54 | 0,54 | 0,458 | 4,58 | 0,3894 | 2,4
BSS308P | Canal P 30 V 2 A (Ta) 500mW (Ta) Montage en surface PG-SOT23 | Q5 | 1 | Infineon | Farnell | 2432719 | 0,51621 | 2,58 | 0,51621 | 5,16 | 0,2982 | 0,87706
IRLML6344 | MOSFET N-CH 30V 5A MICRO3/SOT23 | Q3, Q4 | 2 | Infineon | Farnell | 1857299 | 0,43352 | 2,17 | 0,43352 | 8,67 | 0,18544 | 1
10uH | Semi-Shielded Power Inductor, 10 uH, +/- 20%, 2.1 A, -40 to 125 degC, 2-Pin SMD, RoHS, Tape and Reel SRN3015-100M | L1 | 1 | Bourns | Farnell | 2061634 | 0,41222 | 2,06 | 0,41222 | 4,12 | 0,33829 | 3
SBH11-PBPC-D10-ST-BK | Connector Header Through Hole 20 position 0.100 (2.54mm) | J5, J6, J8, J9 | 4 | Sullins | DigiKey | S9172-ND | 0,41 | 1,64 | 0,347 | 13,88 | 0,2945 | 1,02
IRLML2402 | | Q1, Q2 | 2 | Infineon | Mouser | 942-IRLML2402TRPBF | 0,41 | 0,82 | 0,267 | 5,34 | 0,1688 | 1,12
5019 | | J11 | 1 | Keystone | DigiKey | 36-5019CT-ND | 0,37 | 0,37 | 0,278 | 2,78 | 0,2104 | 1,43
TPS7A2033PDBVR | 300mA ultra-low-noise low-IQ low-dropout (LDO) linear regulator with high PSRR 5-SOT-23 -40 to 125 | U7 | 1 | Texas Instruments | Mouser | 595-TPS7A2033PDBVR | 0,31 | 0,31 | 0,217 | 2,17 | 0,166 | 0,8
SMBJ28A | TVS DIODE 28V 45.4V DO214AA | D3, D4, D6, D7, D9 | 5 | Littelfuse | Farnell | 1456531 | 0,25309 | 1,27 | 0,22678 | 11,34 | 0,17416 | 3,3
4.7uF | CAP CER 4.7UF 10V X5R 0805 | C13 | 1 | Yageo Group | DigiKey | 311-1863-1-ND | 0,2 | 0,2 | 0,112 | 1,12 | 0,0451 | 500
1uF | CAPC 1uF X5R 25V 10% 2012 (0805 INCH) | C11, C16, C17 | 3 | TDK | DigiKey | 445-1419-1-ND | 0,18746 | 0,56239 | 0,075 | 2,25 | 0,059 | 68,1
LTST-C170KGKT | Ultra Bright AlInGaP Chip LED, 75 mW, -55 to 85 degC, 2-Pin SMD (0805), RoHS, Tape and Reel | D1 | 1 | Lite-On | DigiKey | 160-1414-1-ND | 0,18 | 0,18 | 0,124 | 1,24 | 0,0864 | 18,32
2.54 | PIN HEADER 2.54 1x10 | X4, X5 | 2 | Wurth Elektronik | DigiKey | 732-5317-ND | 0,16403 | 0,32806 | 0,14646 | 2,93 | 0,09162 | 8169,2
LTST-C170KRKT | LED Red, 75 mW, 54 mcd, -55 to 85 degC, 2-Pin SMD, RoHS, Tape and Reel | DS1 | 1 | Lite-On | DigiKey | 160-1415-1-ND | 0,16 | 0,16 | 0,108 | 1,08 | 0,0751 | 31,99
5010 | Test Point, Red, Through Hole, RoHS, Bulk | TP5, TP6, TP7 | 3 | Keystone | Newark | 62W5144 | 0,15 | 0,45 | 0,15 | 4,5 | 0,15 | 46,36
5011 | Test Point, Black, Through Hole, RoHS, Bulk | TP1, TP2, TP3, TP4 | 4 | Keystone | Newark | 88H2535 | 0,137 | 0,548 | 0,132 | 5,28 | 0,12 | 33,64
BZX84C3V6LT1G | Zener Voltage Regulator, 225 mW, 3-Pin SOT-23, Pb-Free, Tape and Reel | D5, D8 | 2 | onsemi | Farnell | 2317468 | 0,11441 | 0,57206 | 0,11441 | 2,29 | 0,0389 | 38,94
19k1 | RES 19k1 OHM 5% 1/4W 0805 | R30 | 1 | Yageo Group | Farnell | 4061021 | 0,11026 | 0,11026 | 0,01253 | 0,31324 | 0,00877 | 7,51
100k | RES 100kohm ±1% 0.125W 2012 (0805 INCH) | R29 | 1 | Yageo Group | Mouser | 603-RC0805FR-07100KL | 0,1 | 0,1 | 0,012 | 0,12 | 0,011 | 221,62
2k7 1% | RES 2.7K OHM 1% 1/8W 0805 RC0805FR-102K7L | R15 | 1 | Yageo Group | DigiKey | 13-RC0805FR-102K7LCT-ND | 0,1 | 0,1 | 0,016 | 0,16 | 0,0102 | 790,52
100nF | CAPC 100nF X7R 50V 10% 2012 (0805 INCH) | C1, C2, C4, C5, C6, C7, C9, C10, C12, C14, C18 | 11 | KYOCERA AVX | Farnell | 499687 | 0,03859 | 0,4245 | 0,02756 | 3,03 | 0,02143 | 169,15
0.1 uF | CAP CER 0.1 uF 10V X5R 0805 | C8 | 1 | Yageo Group | Farnell | 3019949 | 0,02493 | 0,24934 | 0,02493 | 0,24934 | 0,01654 | 1384,5
10k 1% | RES SMD 10K OHM 0.1% 1/8W 0805 AC0805FR-0710KL | R16 | 1 | Yageo Group | Farnell | 3495316 | 0,02255 | 0,22553 | 0,02255 | 0,22553 | 0,01691 | 117,8
0R | RES 0ohm ±1% 0.125W 2012 (0805 INCH) | R28, R31, R32 | 3 | Vishay | Newark | 52K9721 | 0,022 | 0,066 | 0,017 | 0,51 | 0,011 | 23,57
100k 1% | RES 100K OHM 1% 1/8W 0805 AC0805FR-13100KL | R17 | 1 | Yageo Group | Farnell | 4013022 | 0,02042 | 0,20423 | 0,02042 | 0,20423 | 0,02042 | 17,7
1P1T-P | SW 600X600X700 24V 50mA THT | S1 | 1 | TE Connectivity | Newark | 95M4263 | 0,019 | 0,019 | 0,019 | 0,19 | 0,019 | 4,51
2k2 1% | RES 2.2K OHM 1% 1/8W 0805 RC0805FR-072K2L | R14 | 1 | Yageo Group | Farnell | 9237534 | 0,01228 | 0,12279 | 0,01228 | 0,12279 | 0,01115 | 1,65
1k5 | RES 1.5kohm ±1% 0.125W 2012 (0805 INCH) | R2, R3 | 2 | Yageo Group | DigiKey | 311-1.50KCRCT-ND | 0,01172 | 0,11717 | 0,01172 | 0,23433 | 0,00715 | 64,65
680R | RES 680ohm ±1% 0.125W 2012 (0805 INCH) | R4 | 1 | Yageo Group | Newark | 49AK3363 | 0,005 | 0,005 | 0,005 | 0,05 | 0,005 | 29,82
560R | RES 560ohm ±1% 0.125W 2012 (0805 INCH) | R1 | 1 | Yageo Group | Newark | 49AK3322 | 0,005 | 0,005 | 0,005 | 0,05 | 0,005 | 122,01
18k | RES 18kohm ±1% 0.125W 2012 (0805 INCH) | R22, R27 | 2 | Yageo Group | Newark | 49AK3089 | 0,005 | 0,01 | 0,005 | 0,1 | 0,005 | 16,6
10k | RES 10kohm ±1% 0.125W 2012 (0805 INCH) | R5, R7, R18, R19, R23, R25 | 6 | Yageo Group | Newark | 49AK0724 | 0,005 | 0,03 | 0,005 | 0,3 | 0,005 | 379,39
100R | RES 100ohm ±1% 0.125W 2012 (0805 INCH) | R6 | 1 | Yageo Group | RS | 6185135 | 0,00456 | 0,00456 | 0,00456 | 0,04562 | 0,00456 | 21,04
120k | RES 120kohm ±1% 0.125W 2012 (0805 INCH) | R20, R24 | 2 | Yageo Group | Newark | 49AK3045 | 0,004 | 0,008 | 0,004 | 0,08 | 0,004 | 183,78
47R | RES 47ohm ±1% 0.125W 2012 (0805 INCH) | R8, R9, R10, R11, R12, R13 | 6 | Yageo Group | Newark | 98K7855 | 0,004 | 0,024 | 0,004 | 0,24 | 0,004 | 33,76
1k0 | RES 1.0kohm ±1% 0.125W 2012 (0805 INCH) | R21, R26 | 2 | Yageo Group | Newark | 82K7536 | 0,004 | 0,008 | 0,004 | 0,08 | 0,004 | 183,78
| | | | | | | Totaux QTY 1 | 158,88554 | Totaux QTY 10 | 1422,49508 | Totaux QTY 100 | 13385,64323
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

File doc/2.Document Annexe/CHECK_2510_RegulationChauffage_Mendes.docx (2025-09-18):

# Checklist revue de schéma 2510 Regulation Chauffage

Schéma(s) étudiant(e) : | Léo Mendes
Revu par : | Léo Mendes, Philippe Bovet, Antonin Graff
Date : | 25.08.2025

Contrôle | OK/NOK | Commentaires
1. ERC (compilation) ok ou erreurs connues | OK
2. Connexions entre pages sont correctes et cohérentes | OK
3. ICs tous alimentés et tensions correctes | OK
4. Découplages | OK
5. Connexions et polarités composants (trans bi-polaires, MOS, diodes, leds….) | OK
6. Entrées + et – AOPs et comparateurs | NA
7. Communications : TX / RX, MISO / MOSI, CS | OK
8. Câblage signaux de debug MCU | NA
9. Pas de conflits entrées / sorties | OK
10. Analyse sommaire du design | OK

JMO/SCA 1ChecklistRevueDeSchema-v0.docx

SLO /Diplôme

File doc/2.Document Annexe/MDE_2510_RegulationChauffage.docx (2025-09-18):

Ecole supérieure

Électronique

Mode d’emplois


2510_RegulationChauffage

Réalisé par :

Léo Mendes

Table des matières :

# 1 Câblage alimentation

# 2 Flasher le système d’exploitation sur le CM5

## 2.1 Objectif

Le but de cette manipulations est d’avoir une compute module 5, exécutant l’OS linux Raspberry Pi OS Lite afin d’y pouvoir exécuter le script python du projets.
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

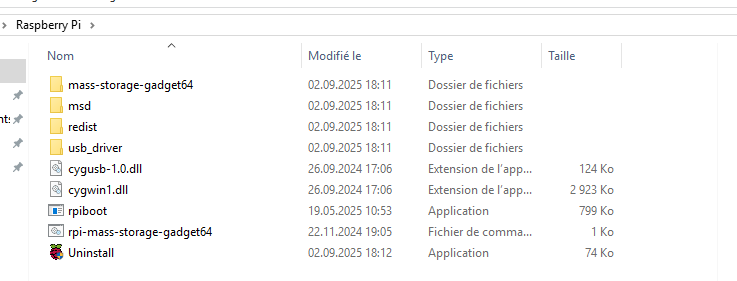
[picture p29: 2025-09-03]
doc/9.SoftWare/1.RPIBOOT/Capture d’écran 2025-09-02 181635.png

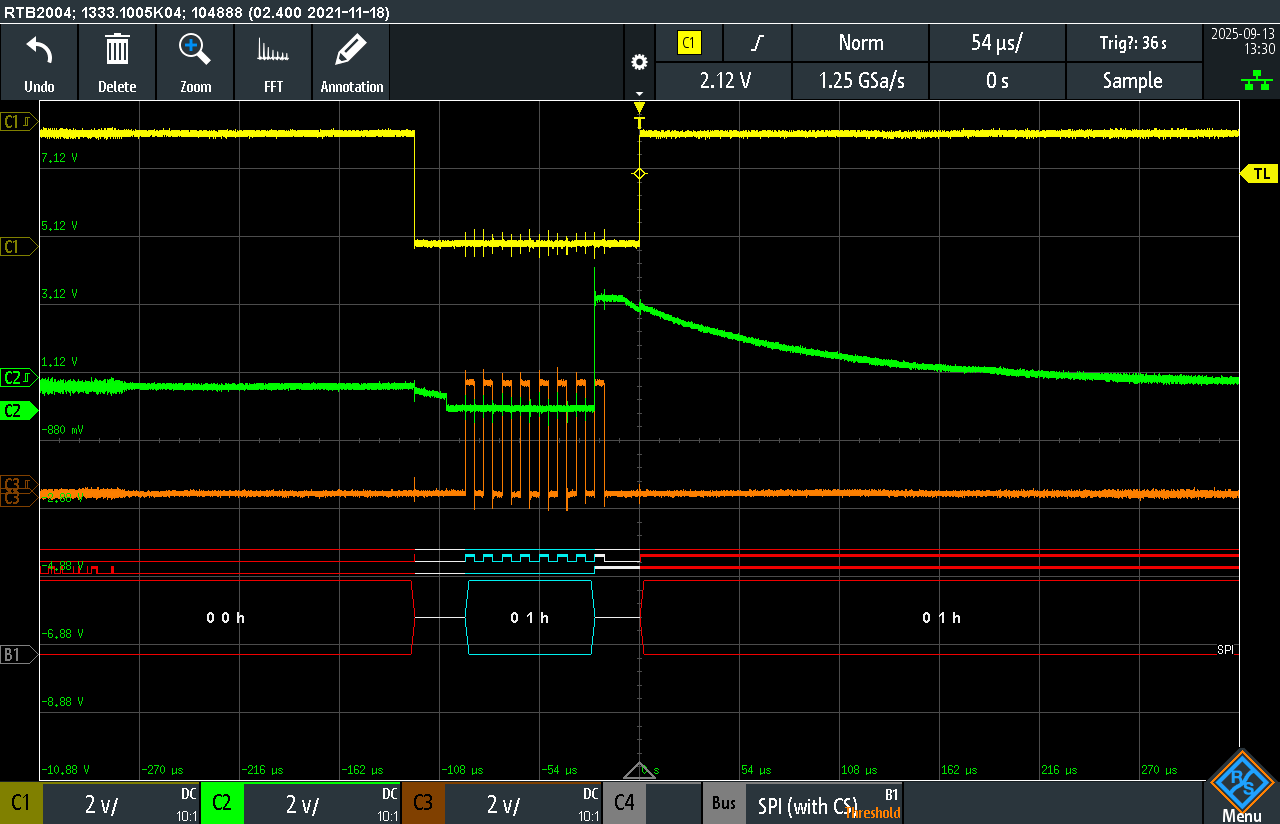
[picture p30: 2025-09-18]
doc/11.Mesure/LDO 3V3/scrprint.png

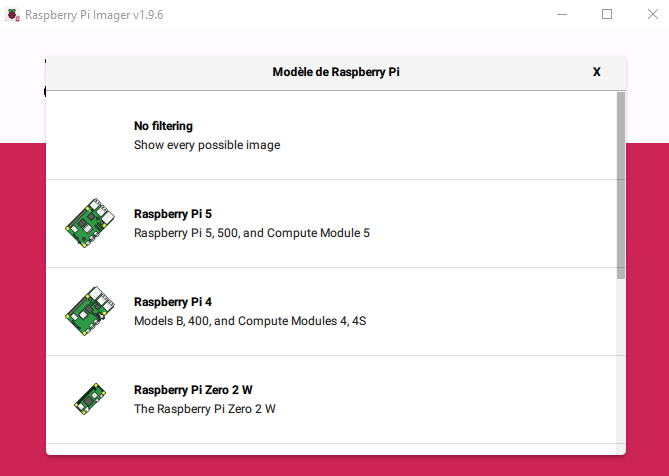
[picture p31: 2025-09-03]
doc/9.SoftWare/2.FlasherRaspberryPi/Capture d’écran 2025-09-02 174822.png

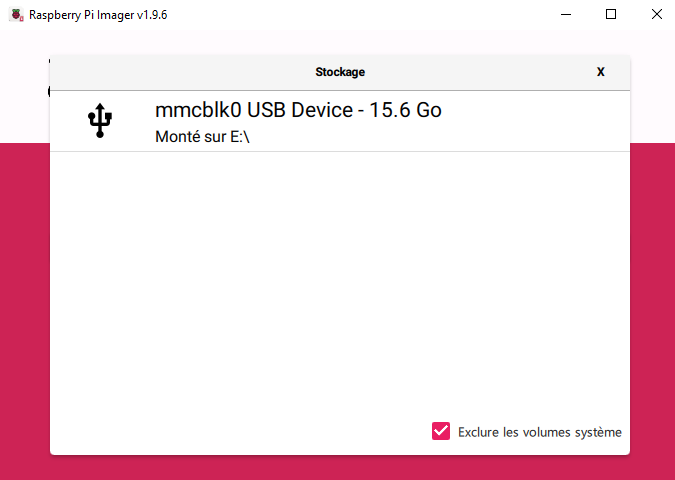
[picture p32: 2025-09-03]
doc/9.SoftWare/2.FlasherRaspberryPi/Capture d’écran 2025-09-02 181437.png

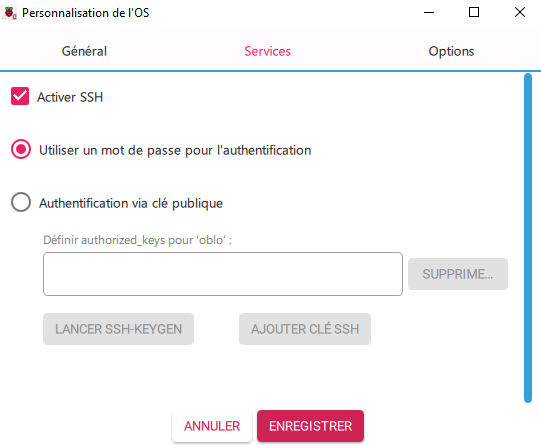
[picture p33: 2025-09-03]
doc/9.SoftWare/2.FlasherRaspberryPi/Capture d’écran 2025-09-02 183644.png

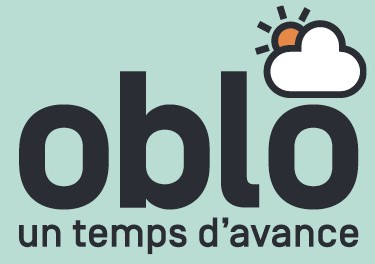
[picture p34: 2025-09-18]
doc/5.Ressource/oblo_vignette.jpg

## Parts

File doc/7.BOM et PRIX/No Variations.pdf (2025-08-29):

BOM Cost | PROJET: | Rue de Sébeillon 12 2510_RegulationChauffage_Daugtherboard.PrjPcb ETML-ES 1004 Lausanne
Date: | 29.08.2025 | Variante: | Quantité de production (nb PCBs) : 1
Par: | LMS | Source: | 2510_RegulationChauffage_Daugtherboard.BomDoc | Devise : CHF
Line # | Designator | Value | Name | Manufacturer 1 | Manufacturer Part Number 1 | Quantity | Supplier 1 | Supplier Part Number 1 | Supplier Order Qty 1 | Supplier Unit Price 1 | Supplier Subtotal 1
| C1, C2 | 0.1 uF | 0.1 uF | Yageo Group | CC0805KRX7R9BB104 | 2 | Farnell | 3019949 | 2 | 0.0241 | 0.05
| D1, D2 | | SP1002-02JTG | Littelfuse | SP1002-02JTG | 2 | DigiKey | F4238CT-ND | 2 | 0.1958 | 0.39
| D3, D4 | | SS14 | onsemi | SS14 | 2 | Farnell | 1467537 | 2 | 0.2134 | 0.43
| J1 | | SFH11-PBPC-D10-RA-BK | Sullins | SFH11-PBPC-D10-RA-BK | 1 | Digikey | S9205-ND | 1 | 0.9347 | 0.93
| J2, J3 | | 5019 | Keystone | 5019 | 2 | DigiKey | 36-5019CT-ND | 2 | 0.2231 | 0.45
| K1, K2 | | TQ2-5V-3 | Panasonic | TQ2-5V-3 | 2 | DigiKey | 255-2257-ND | 2 | 2.4900 | 4.98
| PCB1 | | PCB | Eurocircuit | - | 1 | Eurocircuit | - | 1 | 55.6700 | 55.67
| Q1, Q2 | | IRLML2402 | UMWIRLML2402TR | UMWIRLML2402TR | 2 | Digikey | 4518-UMWIRLML2402TR-ND | 2 | 0.3480 | 0.70
| R1 | | 200R | Bourns | 3386H-1-201LF | 1 | Farnell | 9354930 | 1 | 1.2300 | 1.23
| R2 | | 820R | Yageo Group | RC0805FR-13820RL | 1 | DigiKey | 13-RC0805FR-13820RLCT-ND | 1 | 0.0241 | 0.02
| R3, R4, R6, R8, R11, R15 | | 6R2 | Yageo Group | RC0805FR-076R2L | 6 | Farnell | 3952295 | 6 | 0.0294 | 0.18
| R5, R7, R9, R10, R12, R13, R14, R16, R17, R18, R19, R20, R21, R22, | | 6R8 | Yageo Group | RC0805FR-076R8L | 21 | DigiKey | 311-6.80CRCT-ND | 21 | 0.0114 | 0.24
| R24, R28, R31, R33 | | 7R5 | Yageo Group | AC0805FR-077R5L | 4 | DigiKey | 13-AC0805FR-077R5LCT-ND | 4 | 0.0196 | 0.08
| R66, R67 | 100 | 100R | Yageo Group | RC0805FR-07100RL | 2 | Farnell | 9237364 | 2 | 0.0133 | 0.03
| R68, R70 | 0 | 0R | Vishay | CRCW08050000Z0EA | 2 | DigiKey | 541-0.0ACT-ND | 2 | 0.0178 | 0.04
| R69, R71 | 100k | 100k | Yageo Group | RC0805FR-07100KL | 2 | Farnell | 9237879 | 2 | 0.0125 | 0.02
| TP1, TP2 | | 5011 | Keystone | 5011 | 2 | Farnell | 2431148 | 2 | 0.1159 | 0.23
| TP3, TP4 | | 5010 | Keystone | 5010 | 2 | DigiKey | 36-5010-ND | 2 | 0.2352 | 0.47
| U1 | | ADG732BSUZ-REEL | Analog Devices | ADG732BSUZ-REEL | 1 | Farnell | 4032557 | 1 | 13.8800 | 13.88
| U2 | | 74HC595PW,118 | Nexperia | 74HC595PW,118 | 1 | DigiKey | 1727-3068-1-ND | 1 | 0.2247 | 0.22
| X1 | 2.54 | 2.54 | Wurth Elektronik | 61300411121 | 1 | DigiKey | 732-5317-ND | 1 | 0.1404 | 0.14
Approved Notes | | | | | | | | | | | CHF 80.38
29.08.2025 | Page 1 / 1

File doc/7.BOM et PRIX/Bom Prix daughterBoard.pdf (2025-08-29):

BOM Cost | PROJET: | 2510_RegulationChauffage_Daugtherboard.PrjPcb ETML-ES Rue de Sébeillon 12 1004 Lausanne
Date: | 29.08.2025 | Variante: | Quantité de production (nb PCBs) : 1 | Quantité de production (nb PCBs) : | 100
Par: | LMS | Source: | 2510_RegulationChauffage_Daugtherboard.BomDoc | Devise : CHF | Devise : CHF
Line # | Designator | Value | Name | Manufacturer 1 | Manufacturer Part Number 1 | Quantity | Supplier 1 | Supplier Part Number 1 | Supplier Order Qty 1 | Supplier Unit Price 1 | Supplier Subtotal 1 | Supplier Order Qty 1 | Supplier Unit Price 1 | Supplier Subtotal 1
| C1, C2 | 0.1 uF | 0.1 uF | Yageo Group | CC0805KRX7R9BB104 | 2 | Farnell | 3019949 | 2 | 0.0241 | 0.05 | 200 | 0.0241 | 4.82
| D1, D2 | | SP1002-02JTG | Littelfuse | SP1002-02JTG | 2 | DigiKey | F4238CT-ND | 2 | 0.1958 | 0.39 | 200 | 0.1958 | 39.17
| D3, D4 | | SS14 | onsemi | SS14 | 2 | Farnell | 1467537 | 2 | 0.2134 | 0.43 | 200 | 0.2134 | 42.68
| J1 | | SFH11-PBPC-D10-RA-BK | Sullins | SFH11-PBPC-D10-RA-BK | 1 | Digikey | S9205-ND | 1 | 0.9347 | 0.93 | 100 | 0.9347 | 93.47
| J2, J3 | | 5019 | Keystone | 5019 | 2 | DigiKey | 36-5019CT-ND | 2 | 0.2231 | 0.45 | 200 | 0.2231 | 44.62
| K1, K2 | | TQ2-5V-3 | Panasonic | TQ2-5V-3 | 2 | DigiKey | 255-2257-ND | 2 | 2.4900 | 4.98 | 200 | 2.4900 | 498.00
| PCB1 | | PCB | Eurocircuit | - | 1 | Eurocircuit | - | 1 | 55.6700 | 55.67 | 100 | 5.6000 | 560.00
| Q1, Q2 | | IRLML2402 | UMWIRLML2402TR | UMWIRLML2402TR | 2 | Digikey | 4518-UMWIRLML2402TR-ND | 2 | 0.3480 | 0.70 | 200 | 0.3480 | 69.61
| R1 | | 200R | Bourns | 3386H-1-201LF | 1 | Farnell | 9354930 | 1 | 1.2300 | 1.23 | 100 | 1.2300 | 123.00
| R2 | | 820R | Yageo Group | RC0805FR-13820RL | 1 | DigiKey | 13-RC0805FR-13820RLCT-ND | 1 | 0.0241 | 0.02 | 100 | 0.0241 | 2.41
| R3, R4, R6, R8, R11, R15 | | 6R2 | Yageo Group | RC0805FR-076R2L | 6 | Farnell | 3952295 | 6 | 0.0294 | 0.18 | 600 | 0.0294 | 17.64
| R5, R7, R9, R10, R12, R13, R14, R16, R17, R18, R19, R20, R21, R22, | | 6R8 | Yageo Group | RC0805FR-076R8L | 21 | DigiKey | 311-6.80CRCT-ND | 21 | 0.0114 | 0.24 | 2100 | 0.0114 | 23.94
| R24, R28, R31, R33 | | 7R5 | Yageo Group | AC0805FR-077R5L | 4 | DigiKey | 13-AC0805FR-077R5LCT-ND | 4 | 0.0196 | 0.08 | 400 | 0.0196 | 7.83
| R66, R67 | 100 | 100R | Yageo Group | RC0805FR-07100RL | 2 | Farnell | 9237364 | 2 | 0.0133 | 0.03 | 200 | 0.0133 | 2.66
| R68, R70 | 0 | 0R | Vishay | CRCW08050000Z0EA | 2 | DigiKey | 541-0.0ACT-ND | 2 | 0.0178 | 0.04 | 200 | 0.0178 | 3.56
| R69, R71 | 100k | 100k | Yageo Group | RC0805FR-07100KL | 2 | Farnell | 9237879 | 2 | 0.0125 | 0.02 | 200 | 0.0125 | 2.49
| TP1, TP2 | | 5011 | Keystone | 5011 | 2 | Farnell | 2431148 | 2 | 0.1159 | 0.23 | 200 | 0.1159 | 23.18
| TP3, TP4 | | 5010 | Keystone | 5010 | 2 | DigiKey | 36-5010-ND | 2 | 0.2352 | 0.47 | 200 | 0.2352 | 47.03
| U1 | | ADG732BSUZ-REEL | Analog Devices | ADG732BSUZ-REEL | 1 | Farnell | 4032557 | 1 | 13.8800 | 13.88 | 100 | 6.8000 | 680.00
| U2 | | 74HC595PW,118 | Nexperia | 74HC595PW,118 | 1 | DigiKey | 1727-3068-1-ND | 1 | 0.2247 | 0.22 | 100 | 0.2247 | 22.47
| X1 | 2.54 | 2.54 | Wurth Elektronik | 61300411121 | 1 | DigiKey | 732-5317-ND | 1 | 0.1404 | 0.14 | 100 | 0.1404 | 14.04
Approved Notes | | | | | | | | | | | CHF 80.38 | | | CHF 2 322.62

29.08.2025 Page 1 / 1

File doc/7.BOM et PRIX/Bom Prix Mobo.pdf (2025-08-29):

BOM Cost | PROJET: | 2510_RegulationChauffage_Motherboard.PrjPcb ETML-ES Rue de Sébeillon 12 1004 Lausanne
Date: | 29.08.2025 | Variante: | None Quantité de production (nb PCBs) : 1 | | 100
Par: | LMS | Source: | 2510_RegulationChauffage_Motherboard.BomDoc | Devise : CHF | Devise : CHF
Line # | Designator | Value | Name | Manufacturer 1 | Manufacturer Part Number 1 | Quantit y | Supplier 1 | Supplier Part Number 1 | Supplier Order Qty 1 | Supplier Unit Price 1 | Supplier Subtotal 1 | Supplier Order Qty 1 | Supplier Unit Price 1 | Supplier Subtotal 1
| C1, C2, C4, C5, C6, C7, C9, C12, C14 | 100nF | 100nF | KYOCERA AVX | 08055C104KAT2A | 9 | Farnell | 499687 | 9 | 0.0308 | 0.2772 | 900 | 0.0308 | 27.72
| C3 | | 47 uF | Panasonic | EEEFT1H470AP | 1 | Farnell | 1868425 | 1 | 0.415 | 0.415 | 100 | 0.415 | 41.5
| C8 | 0.1 uF | 0.1 uF | Yageo Group | CC0805KRX7R9BB104 | 1 | Farnell | 3019949 | 1 | 0.0241 | 0.0241 | 100 | 0.0241 | 2.41
| C10 | 330pF | 330pF | KEMET | C0805C331K5RACTU | 1 | Farnell | 2521333 | 1 | 0.0347 | 0.0347 | 100 | 0.0347 | 3.47
| C11, C16, C17 | 1µF | 1uF | TDK | C2012X5R1E105K125AA | 3 | Mouser | 810-C2012X5R1E105K-3 | 3 | 0.061 | 0.183 | 300 | 0.061 | 18.3
| C13 | 4.7 uF | 4.7uF | Yageo Group | CC0805KKX5R6BB475 | 1 | DigiKey | 311-1863-1-ND | 1 | 0.0923 | 0.0923 | 100 | 0.0923 | 9.23
| C15 | | EEEFT1H470AP | Panasonic | EEEFT1H470AP | 1 | Farnell | 1868425 | 1 | 0.415 | 0.415 | 100 | 0.415 | 41.5
| D1 | | LTST-C170KGKT | Lite-On | LTST-C170KGKT | 1 | DigiKey | 160-1414-1-ND | 1 | 0.14446 | 0.14446 | 100 | 0.14446 | 14.446
| D2 | | SP0502BAHTG | Littelfuse | SP0502BAHTG | 1 | Farnell | 1827631 | 1 | 0.56 | 0.56 | 100 | 0.56 | 56
| D3, D4, D6, D7, D9 | | SMBJ28A | Littelfuse | SMBJ28A | 5 | Farnell | 1456531 | 5 | 0.202 | 1.01 | 500 | 0.202 | 101
| D5, D8 | | BZX84C3V6LT1G | onsemi | BZX84C3V6LT1G | 2 | Farnell | 2317468 | 2 | 0.091 | 0.182 | 200 | 0.091 | 18.2
| DS1 | | LTST-C170KRKT | Lite-On | LTST-C170KRKT | 1 | DigiKey | 160-1415-1-ND | 1 | 0.12841 | 0.12841 | 100 | 0.12841 | 12.841
| F1 | | ERB-RG1R25V | Panasonic | ERB-RG1R25V | 1 | DigiKey | P16737CT-ND | 1 | 0.38203 | 0.38203 | 100 | 0.38203 | 38.203
| J1, J2, J3, J4, J7 | | 2601-1104 | WAGO | 2601-1104 | 5 | Farnell | 4126048 | 5 | 2.7 | 13.5 | 500 | 2.7 | 1350
| J5, J6, J8, J9 | | SBH11-PBPC-D10-ST-BK | Sullins | SBH11-PBPC-D10-ST-BK | 4 | DigiKey | S9172-ND | 4 | 0.27849 | 1.11396 | 400 | 0.27849 | 111.396
| J10 | | 2601-1102 | WAGO | 2601-1102 | 1 | Farnell | 4126046 | 1 | 1.53 | 1.53 | 100 | 1.53 | 153
| J11 | | 5019 | Keystone | 5019 | 1 | DigiKey | 36-5019CT-ND | 1 | 0.29695 | 0.29695 | 100 | 0.29695 | 29.695
| L1 | | 10uH | Bourns | SRN3015-100M | 1 | Farnell | 2061634 | 1 | 0.329 | 0.329 | 100 | 0.329 | 32.9
| P1 | | 629712010214 | Wurth Elektronik | 629712010214 | 1 | DigiKey | 732-629712010214CT-ND | 1 | 3.65 | 3.65 | 100 | 3.29 | 329
| P2 | | 53398-0271 | Molex | 53398-0271 | 1 | DigiKey | WM7606CT-ND | 1 | 0.43339 | 0.43339 | 100 | 0.43339 | 43.339
| Q1, Q2 | | IRLML2402 | UMW(Youtai Semiconductor Co., | UMWIRLML2402TR | 2 | Digikey | 4518-UMWIRLML2402TR-ND | 2 | 0.34803 | 0.69606 | 200 | 0.34803 | 69.606
| Q3, Q4 | | IRLML6344 | Infineon | IRLML6344TRPBF | 2 | Farnell | 1857299 | 2 | 0.316 | 0.632 | 200 | 0.316 | 63.2
| Q5 | | BSS308P | Infineon | BSS308PEH6327XTSA1 | 1 | Farnell | 2432719 | 1 | 0.39 | 0.39 | 100 | 0.39 | 39
| R1, R4 | 180k | 180k | Yageo Group | RC0805FR-07180KL | 2 | DigiKey | 311-180KCRCT-ND | 2 | 0.01123 | 0.02246 | 200 | 0.01123 | 2.246
| R2, R3 | 1.5k | 1k5 | Yageo Group | RC0805FR-071K5L | 2 | DigiKey | 311-1.50KCRCT-ND | 2 | 0.0131 | 0.0262 | 200 | 0.0131 | 2.62
| R5, R7, R18, R19, R23, R25 | 10k | 10k | Yageo Group | AC0805FR-0710KL | 6 | Newark | 49AK0724 | 6 | 0.00401 | 0.02406 | 600 | 0.00401 | 2.406
| R6 | 100 | 100R | Yageo Group | RC0805FR-07100RL | 1 | RS | 6185135 | 1 | 0.00364 | 0.00364 | 100 | 0.00364 | 0.364
| R8, R9, R10, R11, R12, R13 | 47 | 47R | Yageo Group | RC0805FR-0747RL | 6 | Newark | 98K7855 | 6 | 0.01284 | 0.07704 | 600 | 0.01284 | 7.704
| R14 | | 2k2 1% | Yageo Group | RC0805FR-072K2L | 1 | Farnell | 9237534 | 1 | 0.0098 | 0.0098 | 100 | 0.0098 | 0.98
| R15 | | 2k7 1% | Yageo Group | RC0805FR-102K7L | 1 | DigiKey | 13-RC0805FR-102K7LCT-ND | 1 | 0.01284 | 0.01284 | 100 | 0.01284 | 1.284
| R16 | | 10k 1% | Yageo Group | AC0805FR-0710KL | 1 | Farnell | 3495316 | 1 | 0.0143 | 0.0143 | 100 | 0.0143 | 1.43
| R17 | | 100k 1% | Yageo Group | AC0805FR-13100KL | 1 | Farnell | 4013022 | 1 | 0.0161 | 0.0161 | 100 | 0.0161 | 1.61
| R20, R24 | 120k | 120k | Yageo Group | RC0805FR-07120KL | 2 | Newark | 49AK3045 | 2 | 0.00321 | 0.00642 | 200 | 0.00321 | 0.642
| R21, R26 | 1k | 1k0 | Yageo Group | RC0805FR-071KL | 2 | Newark | 82K7536 | 2 | 0.00321 | 0.00642 | 200 | 0.00321 | 0.642
| R22, R27 | 18k | 18k | Yageo Group | RC0805FR-0718KL | 2 | Newark | 49AK3089 | 2 | 0.00482 | 0.00964 | 200 | 0.00482 | 0.964
| R28, R31, R32 | 0 | 0R | Vishay | CRCW08050000Z0EA | 3 | Mouser | 71-CRCW0805-0-E3 | 3 | 0.01364 | 0.04092 | 300 | 0.01364 | 4.092
| R29 | 100k | 100k | Yageo Group | RC0805FR-07100KL | 1 | Newark | 05M4536 | 1 | 0.01124 | 0.01124 | 100 | 0.01124 | 1.124
| R30 | | 19k1 | Yageo Group | RC0805FR-0719K1L | 1 | Farnell | 4061021 | 1 | 0.01 | 0.01 | 100 | 0.01 | 1
| S1 | 1P1T-P | 1P1T-P | TE Connectivity | 1-1825910-4 | 1 | Newark | 95M4263 | 1 | 0.01525 | 0.01525 | 100 | 0.01525 | 1.525
| T1 | | 74990101212 | Wurth Elektronik | 74990101212 | 1 | Farnell | 2749150 | 1 | 5.38 | 5.38 | 100 | 4.11 | 411
| TP1, TP2, TP3, TP4 | | 5011 | Keystone | 5011 | 4 | Newark | 88H2535 | 4 | 0.10995 | 0.4398 | 400 | 0.10995 | 43.98
| TP5, TP6, TP7 | | 5010 | Keystone | 5010 | 3 | Mouser | 534-5010 | 3 | 0.23515 | 0.70545 | 300 | 0.23515 | 70.545
| U1, U3 | | TPD4E1U06DCKR | Texas Instruments | TPD4E1U06DCKR | 2 | DigiKey | 296-39347-6-ND | 2 | 0.19904 | 0.39808 | 200 | 0.19904 | 39.808
| U2 | | CM5108032 | Amphenol Communications | 10164227-1004A1RLF | 1 | DigiKey | 609-10164227-1004A1RLFCT-ND | 1 | 2.05 | 2.05 | 100 | 2.05 | 205
| U2(Externe)1 | | Raspberry Pi SC1570 | Raspberry Pi | CM5008016 | 1 | Newark | 20AM3761 | 1 | 64.21 | 64.21 | 100 | 64.21 | 6421
| U4 | | ADS124S08IPBSR | Texas Instruments | ADS124S08IPBSR | 1 | DigiKey | 296-45170-1-ND | 1 | 9.45 | 9.45 | 100 | 6.3242 | 632.42
| U5 | | TMUX1204DGSR | Texas Instruments | TMUX1204DGSR | 1 | Mouser | 595-TMUX1204DGSR | 1 | 0.45747 | 0.45747 | 100 | 0.45747 | 45.747
| U6 | | LMR51625XFDDCR | Texas Instruments | LMR51625XFDDCR | 1 | DigiKey | 296-LMR51625XFDDCRCT-ND | 1 | 1.63 | 1.63 | 100 | 1.63 | 163
| U7 | | TPS7A2033PDBVR | Texas Instruments | TPS7A2033PDBVR | 1 | Mouser | 595-TPS7A2033PDBVR | 1 | 0.2488 | 0.2488 | 100 | 0.2488 | 24.88
| X1, X2, X3 | 2.54 | 2.54 | Wurth Elektronik | 61303611121 | 3 | Farnell | 2356174 | 3 | 0.65427 | 1.96281 | 300 | 0.65427 | 196.281
| X4, X5 | 2.54 | 2.54 | Wurth Elektronik | 61300411121 | 2 | DigiKey | 732-5317-ND | 2 | 0.11794 | 0.23588 | 200 | 0.11794 | 23.588
| | | | | | | | | | | 113.89418 | | | 10913.838

29.08.2025 Page 1 / 1

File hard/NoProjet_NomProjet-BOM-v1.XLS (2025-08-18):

ETML
Refs | Nb | Désignation | Type | Valeur | Fournisseur | N° de commande | Prix u / 1 | Prix u / 10 | Prix u / 100 | Prix u / 1000 | Unité(s) d'emballage | Prix u / unité d'emballage | Prix de référence | Choix | Prix tot | Remarques
X1,X2 | 2 | Connecteur header pour câble plat DIN 41 651 sans bride de rétension | 3421-7600 | 20 pôles | Sasco Spoerle | 238221 |  |  | 2.450 | 2.150 | 100 | 2.450 | / un emb | * | 4.900 | p 3-23.002
 |  |  |  |  |  |  |  |  |  |  |  |  | -
 | 0.14 | m de câble plat 20 pôles | 3365-20 | 20 pôles | Sasco Spoerle | 270327 | 2.050 |  | 1.10 | 0.860 | 91m | 1.100 | / un emb | * | 0.154 | p3-26.029
 |  |  |  |  |  |  |  |  |  |  |  |  | -
 | 1 | montage |  |  | CIP |  |  |  |  |  |  |  | -
 |  |  |  |  | GXE |  |  | 4.000 | 3.000 |  |  |  | / 10 | * | 4.000
 |  |  |  |  |  |  |  |  |  |  |  |  | - | * | 0
 |  |  |  |  |  |  |  |  |  |  |  |  | -
 |  |  |  |  |  |  |  |  |  |  |  |  | - | * | 0
 |  |  |  |  |  |  |  |  |  |  |  |  | -
 |  |  |  |  |  |  |  |  |  |  |  |  | - | * | 0
 |  |  |  |  |  |  |  |  |  |  |  |  | -
 |  |  |  |  |  |  |  |  |  |  |  |  | - | * | 0
 |  |  |  |  |  |  |  |  |  |  |  |  | -
 |  |  |  |  |  |  |  |  |  |  |  |  | - | * | 0
 |  |  |  |  |  |  |  |  |  |  |  |  | -
 |  |  |  |  |  |  |  |  |  |  |  |  | - | * | 0
 |  |  |  |  |  |  |  |  |  |  |  |  | -
 |  |  |  |  |  |  |  |  |  |  |  |  | - | * | 0
 |  |  |  |  |  |  |  |  |  |  |  |  | -
 |  |  |  |  |  |  |  |  |  |  |  |  | - | * | 0
 |  |  |  |  |  |  |  |  |  |  |  |  | -
 |  |  |  |  |  |  |  |  |  |  |  |  | - | * | 0
 |  |  |  |  |  |  |  |  |  |  |  |  | -
 |  |  |  |  |  |  |  |  |  |  |  |  | - | * | 0
 |  |  |  |  |  |  |  |  |  |  |  |  | -
 |  |  |  |  |  |  |  |  |  |  |  |  | - | * | 0
 |  |  |  |  |  |  |  |  |  |  |  |  | -
 |  |  |  |  |  |  |  |  |  |  |  |  | - | * | 0
 |  |  |  |  |  |  |  |  |  |  |  |  | -
 |  |  |  |  |  |  |  |  |  |  |  |  | - | * | 0
 |  |  |  |  |  |  |  |  |  |  |  |  | -
 |  |  |  |  |  |  |  |  |  |  |  |  | - | * | 0
 |  |  |  |  |  |  |  |  |  |  |  |  | -
 |  |  |  |  |  |  |  |  |  |  |  |  | - | * | 0
 |  |  |  |  |  |  |  |  |  |  |  |  | -
 |  |  |  |  |  |  |  |  |  |  |  |  | - | * | 0
 |  |  |  |  |  |  |  |  |  |  |  |  | -
 |  |  |  |  |  |  |  |  |  |  |  |  | - | * | 0
 |  |  |  |  |  |  |  |  |  |  |  |  | -
 |  |  |  |  |  |  |  |  |  |  |  |  |  | Total: | 9.05

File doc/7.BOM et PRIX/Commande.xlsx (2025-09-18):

Commande matériel
Daughterboard
Designator | Value | Name | Manufacturer 1 | Manufacturer Part Number 1 | Quantity | Supplier 1 | Supplier Part Number 1 | Doubler N° composant ? | Commande | Reçu | Monté | Note
C1, C2 | 0.1 uF | 0.1 uF | Yageo Group | CC0805KRX7R9BB104 | 2 | Farnell | 3019949 | 30 avec C1, C2, C4, C5, C6, C7, C9, C10, C12, C14, C18 MOBO +C8 | OK | OK
D1, D2 |  | SP1002-02JTG | Littelfuse | SP1002-02JTG | 2 | DigiKey | F4238CT-ND | 3 | OK | ok
D3, D4 |  | SS14 | onsemi | SS14 | 2 | Farnell | 1467537 | 3 | OK | ok
J1 |  | SFH11-PBPC-D10-RA-BK | Sullins | SFH11-PBPC-D10-RA-BK | 1 | Digikey | S9205-ND | 1 | OK | ok
J2, J3 |  | 5019 | Keystone | 5019 | 2 | DigiKey | 36-5019CT-ND | 4 | OK | ok
K1, K2 |  | TQ2-5V-3 | Panasonic | TQ2-5V-3 | 2 | DigiKey | 255-2257-ND | 3 | OK | ok
Q1, Q2 |  | IRLML2402 | UMWIRLML2402TR | UMWIRLML2402TR | 2 | Digikey | 4518-UMWIRLML2402TR-ND | 6 avec Q1, Q2 MOBO | OK
R1 |  | 200R | Bourns | 3386H-1-201LF | 1 | Farnell | 9354930 | / | OK | ok
R2 |  | 820R | Yageo Group | RC0805FR-13820RL | 1 | DigiKey | 13-RC0805FR-13820RLCT-ND | 2 | Stock ES | Stock ES
R3, R4, R6, R8, R11, R15 |  | 6R2 | Yageo Group | RC0805FR-076R2L | 6 | Farnell | 3952295 |  | OK | ok
R5, R7, R9, R10, R12, R13, R14, R16, R17, R18, R19, R20, R21, R22, R23, R25, R26, R27, R29, R30, R32 |  | 6R8 | Yageo Group | RC0805FR-076R8L | 21 | DigiKey | 311-6.80CRCT-ND | 30 | OK | ok
R24, R28, R31, R33 |  | 7R5 | Yageo Group | AC0805FR-077R5L | 4 | DigiKey | 13-AC0805FR-077R5LCT-ND | 10 | OK | ok
R66, R67 | 100 | 100R | Yageo Group | RC0805FR-07100RL | 2 | Farnell | 9237364 | 10 | Stock ES | Stock ES
R68, R70 | 0 | 0R | Vishay | CRCW08050000Z0EA | 2 | DigiKey | 541-0.0ACT-ND | "+ R28, R31, R32" = 10 | OK
R69, R71 | 100k | 100k | Yageo Group | RC0805FR-07100KL | 2 | Farnell | 9237879 | "+R29" + R17 | Stock ES | Stock ES
TP1, TP2 |  | 5011 | Keystone | 5011 | 2 | Farnell | 2431148 |  | Stock ES | Stock ES
TP3, TP4 |  | 5010 | Keystone | 5010 | 2 | DigiKey | 36-5010-ND |  | Stock ES | Stock ES
U1 |  | ADG732BSUZ-REEL | Analog Devices | ADG732BSUZ-REEL | 1 | Farnell | 4032557 |  | OK | OK
U2 |  | 74HC595PW,118 | Nexperia | 74HC595PW,118 | 1 | DigiKey | 1727-3068-1-ND |  | Not implemented
X1 | 2.54 | 2.54 | Wurth Elektronik | 61300411121 | 1 | DigiKey | 732-5317-ND |  | Stock ES | Stock ES
Motherboard
Designator | Value | Name | Manufacturer 1 | Manufacturer Part Number 1 | Quantity | Supplier 1 | Supplier Part Number 1 | Doubler N° composant ? | Commande | Reçu | Monté | Note
C1, C2, C4, C5, C6, C7, C9, C10, C12, C14, C18 | 100nF | 100nF | KYOCERA AVX | 08055C104KAT2A | 11 | Farnell | 499687 |  | OK | OK
C3, C15 |  | 47 uF | Panasonic | EEEFT1H470AP | 2 | Farnell | 1868425 | 4 | OK | OK
C8 | 0.1 uF | 0.1 uF | Yageo Group | CC0805KRX7R9BB104 | 1 | Farnell | 3019949 |  | OK | OK
C11, C16, C17 | 1µF | 1uF | TDK | C2012X5R1E105K125AA | 3 | Mouser | 810-C2012X5R1E105K-3 | 5 | OK | OK
C13 | 4.7 uF | 4.7uF | Yageo Group | CC0805KKX5R6BB475 | 1 | DigiKey | 311-1863-1-ND | 2 | OK | OK
D1 |  | LTST-C170KGKT | Lite-On | LTST-C170KGKT | 1 | DigiKey | 160-1414-1-ND | 2 | OK | ok
D2 |  | SP0502BAHTG | Littelfuse | SP0502BAHTG | 1 | Farnell | 1827631 | 2 | OK | ok
D3, D4, D6, D7, D9 |  | SMBJ28A | Littelfuse | SMBJ28A | 5 | Farnell | 1456531 | 10 | OK | ok
D5, D8 |  | BZX84C3V6LT1G | onsemi | BZX84C3V6LT1G | 2 | Farnell | 2317468 | 4 | OK | ok
DS1 |  | LTST-C170KRKT | Lite-On | LTST-C170KRKT | 1 | DigiKey | 160-1415-1-ND | 2 | OK | ok
F1 |  | ERB-RG1R25V | Panasonic | ERB-RG1R25V | 1 | DigiKey | P16737CT-ND | 2 | OK | OK
J1, J2, J3, J4, J7 |  | 2601-1104 | WAGO | 2601-1104 | 5 | Farnell | 4126048 | 5 | OK | OK
J5, J6, J8, J9 |  | SBH11-PBPC-D10-ST-BK | Sullins | SBH11-PBPC-D10-ST-BK | 4 | DigiKey | S9172-ND | 4 | OK | OK
J10 |  | 2601-1102 | WAGO | 2601-1102 | 1 | Farnell | 4126046 | 1 | OK | OK
J11 |  | 5019 | Keystone | 5019 | 1 | DigiKey | 36-5019CT-ND |  | OK DAUGHT | OK
L1 |  | 10uH | Bourns | SRN3015-100M | 1 | Farnell | 2061634 | 2 | OK | NOK |  | Erreur commande
P1 |  | 629712010214 | Wurth Elektronik | 629712010214 | 1 | DigiKey | 732-629712010214CT-ND | 2 | OK | OK
P2 |  | 53398-0271 | Molex | 53398-0271 | 1 | DigiKey | WM7606CT-ND | 2 | OK | OK
Q1, Q2 |  | IRLML2402 | Infineon | IRLML2402TRPBF | 2 | Mouser | 942-IRLML2402TRPBF |  | OK | OK
Q3, Q4 |  | IRLML6344 | Infineon | IRLML6344TRPBF | 2 | Farnell | 1857299 | 2 | OK | ok
Q5 |  | BSS308P | Infineon | BSS308PEH6327XTSA1 | 1 | Farnell | 2432719 | 2 | OK | OK
R1 | 560 | 560R | Yageo Group | RC0805FR-07560RL | 1 | Newark | 49AK3322 | 2 | Stock ES | Stock ES
R2, R3 | 1.5k | 1k5 | Yageo Group | RC0805FR-071K5L | 2 | DigiKey | 311-1.50KCRCT-ND | 4 | Stock ES | Stock ES
R4 | 680 | 680R | Yageo Group | RC0805FR-07680RL | 1 | Newark | 49AK3363 | 2 | Stock ES | Stock ES
R5, R7, R18, R19, R23, R25 | 10k | 10k | Yageo Group | AC0805FR-0710KL | 6 | DigiKey | 311-10KLGCT-ND |  | Stock ES | Stock ES
R6 | 100 | 100R | Yageo Group | RC0805FR-07100RL | 1 | RS | 6185135 |  | Stock ES | Stock ES
R8, R9, R10, R11, R12, R13 | 47 | 47R | Yageo Group | RC0805FR-0747RL | 6 | Mouser | 603-RC0805FR-0747RL | 10 | Stock ES | Stock ES
R14 |  | 2k2 1% | Yageo Group | RC0805FR-072K2L | 1 | Farnell | 9237534 |  | Stock ES | Stock ES
R15 |  | 2k7 1% | Yageo Group | RC0805FR-102K7L | 1 | DigiKey | 13-RC0805FR-102K7LCT-ND |  | Stock ES | Stock ES
R16 |  | 10k 1% | Yageo Group | AC0805FR-0710KL | 1 | Farnell | 3495316 |  | Stock ES | Stock ES
R17 |  | 100k 1% | Yageo Group | AC0805FR-13100KL | 1 | Farnell | 4013022 |  | Stock ES | Stock ES
R20, R24 | 120k | 120k | Yageo Group | RC0805FR-07120KL | 2 | Newark | 49AK3045 |  | Stock ES | Stock ES
R21, R26 | 1k | 1k0 | Yageo Group | RC0805FR-071KL | 2 | Newark | 82K7536 |  | Stock ES | Stock ES
R22, R27 | 18k | 18k | Yageo Group | RC0805FR-0718KL | 2 | Newark | 49AK3089 |  | Stock ES | Stock ES
R28, R31, R32 | 0 | 0R | Vishay | CRCW08050000Z0EA | 3 | Mouser | 71-CRCW0805-0-E3 | OK daugtherboard | OK | OK
R29 | 100k | 100k | Yageo Group | RC0805FR-07100KL | 1 | Mouser | 603-RC0805FR-07100KL |  | Stock ES | Stock ES
R30 |  | 19k1 | Yageo Group | RC0805FR-0719K1L | 1 | Farnell | 4061021 |  | Stock ES | Stock ES
S1 | 1P1T-P | 1P1T-P | TE Connectivity | 1-1825910-4 | 1 | Newark | 95M4263 |  | OK | OK
T1 |  | 74990101212 | Wurth Elektronik | 74990101212 | 1 | Farnell | 2749150 |  | OK | OK |  | Changemen composant mais nouveu ok
TP1, TP2, TP3, TP4 |  | 5011 | Keystone | 5011 | 4 | Newark | 88H2535 |  | Stock ES | Stock ES
TP5, TP6, TP7 |  | 5010 | Keystone | 5010 | 3 | Newark | 62W5144 |  | Stock ES | Stock ES
U1, U3 |  | TPD4E1U06DCKR | Texas Instruments | TPD4E1U06DCKR | 2 | DigiKey | 296-39347-1-ND | 6 | OK | OK
U2 |  | CM5108032 | Amphenol Communications Solutions | 10164227-1004A1RLF | 1 | DigiKey | 609-10164227-1004A1RLFCT-ND |  | OK | OK
U2-21 |  | second connector CM5 | Amphenol Communications Solutions | 10164227-1004A1RLF | 1 | DigiKey | 609-10164227-1004A1RLFCT-ND |  | OK | OK
U2(Externe)1 |  | Raspberry Pi SC1570 | Raspberry Pi | CM5008016 | 1 | Newark | 20AM3761 |  | Ok | Ok
U4 |  | ADS124S08IPBSR | Texas Instruments | ADS124S08IPBSR | 1 | DigiKey | 296-45170-1-ND |  | OK | OK
U5 |  | TMUX1204DGSR | Texas Instruments | TMUX1204DGSR | 1 | Mouser | 595-TMUX1204DGSR |  | OK | OK
U6 |  | LMR51625XFDDCR | Texas Instruments | LMR51625XFDDCR | 1 | DigiKey | 296-LMR51625XFDDCRCT-ND |  | OK | OK
U7 |  | TPS7A2033PDBVR | Texas Instruments | TPS7A2033PDBVR | 1 | Mouser | 595-TPS7A2033PDBVR |  | OK | OK
X1, X2, X3 | 2.54 | 2.54 | Wurth Elektronik | 61303611121 | 3 | Farnell | 2356174 |  | Stock ES | Stock ES
X4, X5 | 2.54 | 2.54 | Wurth Elektronik | 61300411121 | 2 | Mouser | 710-61300411121 |  | Stock ES | Stock ES

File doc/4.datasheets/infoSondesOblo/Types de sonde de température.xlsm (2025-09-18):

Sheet: 0 - Accueil
 |  | RPOT: |  | 115 |  |  | Ω |  |  | Type de sonde: |  | Ni1000 TK5000
 |  | R77: |  | 0 |  |  | Ω |  |  | ID: |  | 350
 |  |  |  |  |  |  |  |  | rSensorValueDegC := TO_REAL(1 / (79.46562e-3 + -149.440403e-4*ln(rSensorValueOhm) + 832.033898e-7*EXPT(ln(rSensorValueOhm),3)) - 273.15);
OBLO BASE RESISTOR V2.2 |  |  |  |  |  |  |  |  | R [Ω] | Qté | R | Temp. | R sonde | R PCB | R mesurée
R32 | O | 7.5 | O |  | O | 6.8 | O | R31 | 6.2 | 6 | R1 | -15.0 | 934.74 | 935 | 935
 |  | R64 |  |  |  | R63 |  |  | 6.8 | 21 | R2 | -13.5 | 941.165 | 941.2 | 941.2
R30 | O | 7.5 | O |  | O | 6.8 | O | R29 | 7.5 | 4 | R3 | -12.0 | 947.61 | 947.4 | 947.4
 |  | R62 |  |  |  | R61 |  |  | 820 | 1 | R4 | -10.5 | 954.08 | 954.2 | 954.2
R28 | O | 6.8 | O |  | O | 7.5 | O | R27 |  | 0 | R5 | -9.0 | 960.57 | 960.4 | 960.4
 |  | R60 |  |  |  | R59 |  |  |  | 0 | R6 | -7.5 | 967.085 | 967.2 | 967.2
R26 | O | 6.8 | O |  | O | 6.8 | O | R25 |  | 0 | R7 | -6.0 | 973.62 | 973.4 | 973.4
 |  | R58 |  |  |  | R57 |  |  |  | 0 | R8 | -4.5 | 980.18 | 980.2 | 980.2
R24 | O | 6.8 | O |  | O | 7.5 | O | R23 |  | 0 | R9 | -3.0 | 986.77 | 987 | 987
 |  | R56 |  |  |  | R55 |  |  |  | 0 | R10 | -1.5 | 993.375 | 993.2 | 993.2
R22 | O | 6.8 | O |  | O | 6.8 | O | R21 |  | 0 | R11 | 0.0 | 1000 | 1000 | 1000
 |  | R54 |  |  |  | R53 |  |  |  | 0 | R12 | 1.5 | 1006.65 | 1006.8 | 1006.8
R20 | O | 6.8 | O |  | O | 6.8 | O | R19 |  | 0 | R13 | 3.0 | 1013.33 | 1013.6 | 1013.6
 |  | R52 |  |  |  | R51 |  |  |  | 0 | R14 | 4.5 | 1020.025 | 1019.8 | 1019.8
R18 | O | 6.8 | O |  | O | 6.8 | O | R17 |  | 0 | R15 | 6.0 | 1026.75 | 1026.6 | 1026.6
 |  | R50 |  |  |  | R49 |  |  |  | 0 | R16 | 7.5 | 1033.495 | 1033.4 | 1033.4
R16 | O | 6.8 | O |  | O | 6.8 | O | R15 |  | 0 | R17 | 9.0 | 1040.27 | 1040.2 | 1040.2
 |  | R48 |  |  |  | R47 |  |  |  | 0 | R18 | 10.5 | 1047.06 | 1047 | 1047
R14 | O | 6.2 | O |  | O | 6.8 | O | R13 |  | 0 | R19 | 12.0 | 1053.88 | 1053.8 | 1053.8
 |  | R46 |  |  |  | R45 |  |  |  | 0 | R20 | 13.5 | 1060.725 | 1060.6 | 1060.6
R12 | O | 6.8 | O |  | O | 6.8 | O | R11 |  | 0 | R21 | 15.0 | 1067.59 | 1067.4 | 1067.4
 |  | R44 |  |  |  | R43 |  |  |  | 0 | R22 | 16.5 | 1074.48 | 1074.2 | 1074.2
R10 | O | 6.2 | O |  | O | 6.8 | O | R9 |  | 0 | R23 | 18.0 | 1081.39 | 1081.7 | 1081.7
 |  | R42 |  |  |  | R41 |  |  |  | 0 | R24 | 19.5 | 1088.335 | 1088.5 | 1088.5
R8 | O | 6.8 | O |  | O | 6.2 | O | R7 | MERCI de bien couper le pin pour le détrompeur ! |  | R25 | 21.0 | 1095.3 | 1095.3 | 1095.3
 |  | R40 |  |  |  | R39 |  |  |  |  | R26 | 22.5 | 1102.29 | 1102.1 | 1102.1
R6 | O | 6.8 | O |  | O | 6.2 | O | R5 |  |  | R27 | 24.0 | 1109.3 | 1109.6 | 1109.6
 |  | R38 |  |  |  | R37 |  |  |  |  | R28 | 25.5 | 1116.345 | 1116.4 | 1116.4
R4 | O | 6.8 | O |  | O | 6.2 | O | R3 |  |  | R29 | 27.0 | 1123.41 | 1123.2 | 1123.2
 |  | R36 |  |  |  | R35 |  |  |  |  | R30 | 28.5 | 1130.5 | 1130.7 | 1130.7
R2 | O | 6.2 | O |  | O | 820 | O | R1 |  |  | R31 | 30.0 | 1137.62 | 1137.5 | 1137.5
 |  | R34 |  |  |  | R33 |  |  |  |  | R32 | 31.5 | 1144.755 | 1145 | 1145
 |  |  |  |  |  |  |  |  |  |  |  | delta R | 210.015 | Ohms
 |  |  |  |  |  |  |  |  |  |  |  | resolution | 4.52 | Ohms/°C
 |  |  |  |  |  |  |  |  |  |  |  | résolution | 0.1 | °C
 |  |  |  |  |  |  |  |  |  |  |  | résolution | 0.45 | Ohms
 |  |  |  |  |  |  |  |  |  |  |  | précision | 0.6 | °C
 |  |  |  |  |  |  |  |  |  |  |  | précision | 2.709870968 | Ohms

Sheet: 1 - IDs types de sonde
IDs Types de sonde |  |  |  |  |  | Types sans ID:
ID | Type | R0_R25 | Nom | Description | Qtt en service | NTC 10k2 3977
350 | PTC | 1000 | Ni1000 TK5000 | Siemens QAC21 et Siemens QAC22 | 16
300 | PTC | 1000 | PT1000 |  | 7
2500 | NTC | 10000 | NTC 10k 3977 |  | 6
1045 | NTC | 437 | DeDietrich AF60 |  | 4
351 | PTC | 1000 | Ni1000 TK6180 | DIN EN43760 B | 3
490 | PTC | 1630 | KTY81-210 | Sonde Hoval | 3
1050 | NTC | 563 | Siemens QAC32 | QAC31 également //nommée à tord NTC575 par siemens (20°C) | 3
1100 | NTC | 1000 | NTC 1k 3528 | Siemens QAC34 | 2
500 | PTC | 1650 | DeDietrich AF40 |  | 1
1101 | NTC | 1020 | VRC-DCF 9535 | Vaillant VRC-DCF 9535 | 1
1640 | NTC | 2200 | NTC 2.2k 3528 |  | 1
3000 | NTC | 20000 | NTC 20k 4370 |  | 1
10 | PTC | 100 | PT100
20 | PTC | 100 | Ni100
50 | PTC | 120 | Ni120
100 | PTC | 200 | PT200
200 | PTC | 500 | PT500
201 | PTC | 502 | Viessmann AV17
700 | PTC | 2000
1000 | NTC | 100
1060 | NTC | 600
1070 | NTC | 700
1080 | NTC | 800
1090 | NTC | 900
1150 | NTC | 1100
1200 | NTC | 1200
1250 | NTC | 1300
1300 | NTC | 1400
1350 | NTC | 1500
1400 | NTC | 1600
1450 | NTC | 1700
1500 | NTC | 1800
1550 | NTC | 1900
1600 | NTC | 2000 | NTC 2k Xavier
1601 | NTC | 2000 | NTC 2k 3390
1620 | NTC | 2100
1660 | NTC | 2300
1680 | NTC | 2400
1700 | NTC | 2500
1720 | NTC | 2600
1740 | NTC | 2700
1760 | NTC | 2800
1780 | NTC | 2900
1800 | NTC | 3000
1900 | NTC | 4000
2000 | NTC | 5000

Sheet: 4 - Commande Mouser
R | Qté requise | Stock | Qté commande | Texte Assistant Mouser
6.2 | 50 |  | 50 | MFR-25FTE52-6R2,50
6.8 | 150 |  | 150 | MFR-25FTE52-6R8,150
7.5 | 50 |  | 50 | MFR-25FTE52-7R5,50
8.2 | 150 |  | 150 | MFR-25FTE52-8R2,150
9.1 | 50 |  | 50 | MFR-25FTE52-9R1,50
20 | 300 |  | 300 | MFR-25FTE52-20R,300
22 | 50 |  | 50 | MFR-25FTE52-22R,50
27 | 0 |  | 0 | MFR-25FTE52-27R,0
30 | 50 |  | 50 | MFR-25FTE52-30R,50
33 | 50 |  | 50 | MFR-25FTE52-33R,50
36 | 150 |  | 150 | MFR-25FTE52-36R,150
39 | 50 |  | 50 | MFR-25FTE52-39R,50
68 | 0 |  | 0 | MFR-25FTE52-68R,0
82 | 0 |  | 0 | MFR-25FTE52-82R,0
91 | 0 |  | 0 | MFR-25FTE52-91R,0
100 | 100 |  | 100 | MFR-25FTE52-100R,100
110 | 50 |  | 50 | MFR-25FTE52-110R,50
120 | 100 |  | 100 | MFR-25FTE52-120R,100
130 | 50 |  | 50 | MFR-25FTE52-130R,50
150 | 50 |  | 50 | MFR-25FTE52-150R,50
160 | 50 |  | 50 | MFR-25FTE52-160R,50
180 | 50 |  | 50 | MFR-25FTE52-180R,50
200 | 50 |  | 50 | MFR-25FTE52-200R,50
220 | 50 |  | 50 | MFR-25FTE52-220R,50
240 | 50 |  | 50 | MFR-25FTE52-240R,50
270 | 100 |  | 100 | MFR-25FTE52-270R,100
300 | 50 |  | 50 | MFR-25FTE52-300R,50
330 | 50 |  | 50 | MFR-25FTE52-330R,50
360 | 50 |  | 50 | MFR-25FTE52-360R,50
390 | 50 |  | 50 | MFR-25FTE52-390R,50
430 | 50 |  | 50 | MFR-25FTE52-430R,50
470 | 100 |  | 100 | MFR-25FTE52-470R,100
510 | 50 |  | 50 | MFR-25FTE52-510R,50
560 | 50 |  | 50 | MFR-25FTE52-560R,50
620 | 100 |  | 100 | MFR-25FTE52-620R,100
680 | 100 |  | 100 | MFR-25FTE52-680R,100
750 | 100 |  | 100 | MFR-25FTE52-750R,100
820 | 100 |  | 100 | MFR-25FTE52-820R,100
910 | 50 |  | 50 | MFR-25FTE52-910R,50
1000 | 50 |  | 50 | MFR-25FTE52-1K,50
1200 | 50 |  | 50 | MFR-25FTE52-1K2,50
1300 | 50 |  | 50 | MFR-25FTE52-1K3,50
1500 | 50 |  | 50 | MFR-25FTE52-1K5,50
1600 | 50 |  | 50 | MFR-25FTE52-1K6,50
1800 | 50 |  | 50 | MFR-25FTE52-1K8,50
2000 | 0 |  | 0 | MFR-25FTE52-2K,0
2200 | 0 |  | 0 | MFR-25FTE52-2K2,0
2400 | 0 |  | 0 | MFR-25FTE52-2K4,0
2700 | 50 |  | 50 | MFR-25FTE52-2K7,50
3000 | 0 |  | 0 | MFR-25FTE52-3K,0
3600 | 50 |  | 50 | MFR-25FTE52-3K6,50
3900 | 0 |  | 0 | MFR-25FTE52-3K9,0
4300 | 0 |  | 0 | MFR-25FTE52-4K3,0
5100 | 50 |  | 50 | MFR-25FTE52-5K1,50
6200 | 0 |  | 0 | MFR-25FTE52-6K2,0
7500 | 0 |  | 0 | MFR-25FTE52-7K5,0

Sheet: DeDietrich AF40
#NAME?
#R | θ | Rsonde | Rpcb | Diff R | Diff % | Radd | RaddLow | RaddLowDiff | RaddHigh | RaddHighDiff | Rmes | Rpot | 148 | Ω
R1/R33 | -15.0 | 1448.40 | 1448.00 | -0.40 | -0.02761668048% | 1300.00 | 1300.00 | -148.40 | 1500.00 | 51.60 | 1448 | R77 |  | Ω
R2/R34 | -13.5 | 1468.65 | 1468.00 | -0.65 | -0.04425833248% | 20.00 | 20.00 | -0.65 | 22.00 | 1.35 | 1468
R3/R35 | -12.0 | 1488.90 | 1488.00 | -0.90 | -0.1% | 20.00 | 20.00 | -0.90 | 22.00 | 1.10 | 1488 | Steinhart-Hart coefficients
R4/R36 | -10.5 | 1509.15 | 1510.00 | 0.85 | 0.1% | 22.00 | 20.00 | -1.15 | 22.00 | 0.85 | 1510 | A | 0.01323712393
R5/R37 | -9.0 | 1529.40 | 1530.00 | 0.60 | 0.03923107101% | 20.00 | 18.00 | -1.40 | 20.00 | 0.60 | 1530 | B | -0.001120802327
R6/R38 | -7.5 | 1549.65 | 1550.00 | 0.35 | 0.02258574517% | 20.00 | 18.00 | -1.65 | 20.00 | 0.35 | 1550 | C | -3.127957436e-06
R7/R39 | -6.0 | 1569.90 | 1570.00 | 0.10 | 0.006369832473% | 20.00 | 18.00 | -1.90 | 20.00 | 0.10 | 1570 | a | -1.119016803
R8/R40 | -4.5 | 1590.15 | 1590.00 | -0.15 | -0.009433072352% | 20.00 | 20.00 | -0.15 | 22.00 | 1.85 | 1590 | b | 3.500236929e-06
R9/R41 | -3.0 | 1610.40 | 1610.00 | -0.40 | -0.02483854943% | 20.00 | 20.00 | -0.40 | 22.00 | 1.60 | 1610 | L1 | 7.278214778
R10/R42 | -1.5 | 1630.65 | 1630.00 | -0.65 | -0.03986140496% | 20.00 | 20.00 | -0.65 | 22.00 | 1.35 | 1630 | L2 | 7.456974351
R11/R43 | 0.0 | 1650.90 | 1650.00 | -0.90 | -0.1% | 20.00 | 20.00 | -0.90 | 22.00 | 1.10 | 1650 | L3 | 7.608572966
R12/R44 | 1.5 | 1671.15 | 1672.00 | 0.85 | 0.1% | 22.00 | 20.00 | -1.15 | 22.00 | 0.85 | 1672 | Y1 | 0.003873716831
R13/R45 | 3.0 | 1691.40 | 1692.00 | 0.60 | 0.03547357219% | 20.00 | 18.00 | -1.40 | 20.00 | 0.60 | 1692 | Y2 | 0.003582303421
R14/R46 | 4.5 | 1711.65 | 1712.00 | 0.35 | 0.02044810563% | 20.00 | 18.00 | -1.65 | 20.00 | 0.35 | 1712 | Y3 | 0.0033316675
R15/R47 | 6.0 | 1731.90 | 1732.00 | 0.10 | 0.005774005428% | 20.00 | 18.00 | -1.90 | 20.00 | 0.10 | 1732
R16/R48 | 7.5 | 1752.15 | 1752.00 | -0.15 | -0.008560910881% | 20.00 | 20.00 | -0.15 | 22.00 | 1.85 | 1752
R17/R49 | 9.0 | 1772.40 | 1772.00 | -0.40 | -0.02256826901% | 20.00 | 20.00 | -0.40 | 22.00 | 1.60 | 1772
R18/R50 | 10.5 | 1792.65 | 1792.00 | -0.65 | -0.03625916939% | 20.00 | 20.00 | -0.65 | 22.00 | 1.35 | 1792 | x | y | a | b
R19/R51 | 12.0 | 1812.90 | 1812.00 | -0.90 | -0.04964421645% | 20.00 | 20.00 | -0.90 | 22.00 | 1.10 | 1812 | -20 | 1388 | 13.5 | 1650.888889
R20/R52 | 13.5 | 1833.15 | 1834.00 | 0.85 | 0.04636827319% | 22.00 | 20.00 | -1.15 | 22.00 | 0.85 | 1834 | -15 | 1450
R21/R53 | 15.0 | 1853.40 | 1854.00 | 0.60 | 0.03237293623% | 20.00 | 18.00 | -1.40 | 20.00 | 0.60 | 1854 | -10 | 1514
R22/R54 | 16.5 | 1873.65 | 1874.00 | 0.35 | 0.01868011635% | 20.00 | 18.00 | -1.65 | 20.00 | 0.35 | 1874 | -5 | 1579
R23/R55 | 18.0 | 1893.90 | 1894.00 | 0.10 | 0.005280109826% | 20.00 | 18.00 | -1.90 | 20.00 | 0.10 | 1894 | 0 | 1646
R24/R56 | 19.5 | 1914.15 | 1914.00 | -0.15 | -0.00783637646% | 20.00 | 20.00 | -0.15 | 22.00 | 1.85 | 1914 | 5 | 1714
R25/R57 | 21.0 | 1934.40 | 1934.00 | -0.40 | -0.02067824648% | 20.00 | 20.00 | -0.40 | 22.00 | 1.60 | 1934 | 10 | 1784
R26/R58 | 22.5 | 1954.65 | 1954.00 | -0.65 | -0.03325403525% | 20.00 | 20.00 | -0.65 | 22.00 | 1.35 | 1954 | 15 | 1855
R27/R59 | 24.0 | 1974.90 | 1974.00 | -0.90 | -0.04557192769% | 20.00 | 20.00 | -0.90 | 22.00 | 1.10 | 1974 | 20 | 1928
R28/R60 | 25.5 | 1995.15 | 1996.00 | 0.85 | 0.04260331303% | 22.00 | 20.00 | -1.15 | 22.00 | 0.85 | 1996
R29/R61 | 27.0 | 2015.40 | 2016.00 | 0.60 | 0.02977076511% | 20.00 | 18.00 | -1.40 | 20.00 | 0.60 | 2016
R30/R62 | 28.5 | 2035.65 | 2036.00 | 0.35 | 0.01719352541% | 20.00 | 18.00 | -1.65 | 20.00 | 0.35 | 2036
R31/R63 | 30.0 | 2055.90 | 2056.00 | 0.10 | 0.004864049808% | 20.00 | 18.00 | -1.90 | 20.00 | 0.10 | 2056
R32/R64 | 31.5 | 2076.15 | 2076.00 | -0.15 | -0.007224911495% | 20.00 | 20.00 | -0.15 | 22.00 | 1.85 | 2076

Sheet: DeDietrich AF60
#NAME?
#R | θ | Rsonde | Rpcb | Diff R | Diff % | Radd | RaddLow | RaddLowDiff | RaddHigh | RaddHighDiff | Rmes | Rpot | 100 | Ω | x | y
R32/R64 | -15.0 | 2015.00 | 2010.00 | -5.00 | -0.2% | 110.00 | 110.00 | -5.00 | 120.00 | 5.00 | 2010 | R77 |  | Ω | -864.2015223 | 439.4437059
R31/R63 | -13.5 | 1904.02 | 1900.00 | -4.02 | -0.2% | 100.00 | 100.00 | -4.02 | 110.00 | 5.98 | 1900 |  |  |  | -851.2815264 | 433.0932488
R30/R62 | -12.0 | 1799.19 | 1800.00 | 0.81 | 0.04524054684% | 100.00 | 91.00 | -8.19 | 100.00 | 0.81 | 1800 | Steinhart-Hart coefficients |  |  | -838.509951 | 426.8189749
R29/R61 | -10.5 | 1700.13 | 1700.00 | -0.13 | -0.007776280162% | 91.00 | 91.00 | -0.13 | 100.00 | 8.87 | 1700 | A | 0.002376849001 |  | -825.884253 | 420.6196651
R28/R60 | -9.0 | 1606.53 | 1609.00 | 2.47 | 0.2% | 91.00 | 82.00 | -6.53 | 91.00 | 2.47 | 1609 | B | 9.647385199e-05 |  | -813.4019474 | 414.4941313
R27/R59 | -7.5 | 1518.08 | 1518.00 | -0.08 | -0.005322801754% | 82.00 | 82.00 | -0.08 | 91.00 | 8.92 | 1518 | C | 1.732081918e-06 |  | -801.0606052 | 408.441215
R26/R58 | -6.0 | 1434.48 | 1436.00 | 1.52 | 0.1% | 82.00 | 75.00 | -5.48 | 82.00 | 1.52 | 1436 | a | -26.43374396 |  | -788.8578518 | 402.4597874
R25/R57 | -4.5 | 1355.46 | 1354.00 | -1.46 | -0.1% | 75.00 | 75.00 | -1.46 | 82.00 | 5.54 | 1354 | b | -4.578540994e-05 |  | -776.791366 | 396.5487479
R24/R56 | -3.0 | 1280.77 | 1279.00 | -1.77 | -0.1% | 68.00 | 68.00 | -1.77 | 75.00 | 5.23 | 1279 | L1 | 7.608374476 |  | -764.8588778 | 390.707024
R23/R55 | -1.5 | 1210.15 | 1211.00 | 0.85 | 0.1% | 68.00 | 62.00 | -5.15 | 68.00 | 0.85 | 1211 | L2 | 6.814263034 |  | -753.0581674 | 384.9335706
R22/R54 | 0.0 | 1143.39 | 1143.00 | -0.39 | -0.03397899574% | 62.00 | 62.00 | -0.39 | 68.00 | 5.61 | 1143 | L3 | 6.006504836 |  | -741.387064 | 379.2273692
R21/R53 | 1.5 | 1080.26 | 1081.00 | 0.74 | 0.1% | 62.00 | 56.00 | -5.26 | 62.00 | 0.74 | 1081 | Y1 | 0.003873716831 |  | -729.843444 | 373.5874276
R20/R52 | 3.0 | 1020.57 | 1019.00 | -1.57 | -0.2% | 56.00 | 56.00 | -1.57 | 62.00 | 4.43 | 1019 | Y2 | 0.003582303421 |  | -718.42523 | 368.0127792
R19/R51 | 4.5 | 964.13 | 963.00 | -1.13 | -0.1% | 51.00 | 51.00 | -1.13 | 56.00 | 3.87 | 963 | Y3 | 0.0033316675 |  | -707.1303894 | 362.5024824
R18/R50 | 6.0 | 910.75 | 912.00 | 1.25 | 0.1% | 51.00 | 47.00 | -2.75 | 51.00 | 1.25 | 912 |  |  |  | -695.9569334 | 357.0556205
R17/R49 | 7.5 | 860.26 | 861.00 | 0.74 | 0.1% | 47.00 | 43.00 | -3.26 | 47.00 | 0.74 | 861 |  |  |  | -684.9029158 | 351.6713009
R16/R48 | 9.0 | 812.51 | 814.00 | 1.49 | 0.2% | 47.00 | 43.00 | -2.51 | 47.00 | 1.49 | 814 |  |  |  | -673.9664316 | 346.3486547
R15/R47 | 10.5 | 767.36 | 767.00 | -0.36 | -0.04626751926% | 43.00 | 43.00 | -0.36 | 47.00 | 3.64 | 767 |  |  |  | -663.1456162 | 341.0868363
R14/R46 | 12.0 | 724.64 | 724.00 | -0.64 | -0.1% | 39.00 | 39.00 | -0.64 | 43.00 | 3.36 | 724 | Avec les points suivants |  |  | -652.4386442 | 335.8850234
R13/R45 | 13.5 | 684.24 | 685.00 | 0.76 | 0.1% | 39.00 | 36.00 | -2.24 | 39.00 | 0.76 | 685 | T | R |  | -641.8437284 | 330.7424161
R12/R44 | 15.0 | 646.02 | 646.00 | -0.02 | -0.003733205765% | 36.00 | 36.00 | -0.02 | 39.00 | 2.98 | 646 | -15 | 2015 |  | -631.3591189 | 325.6582367
R11/R43 | 16.5 | 609.88 | 610.00 | 0.12 | 0.02030475371% | 33.00 | 30.00 | -2.88 | 33.00 | 0.12 | 610 | 5 | 946 |  | -620.9831019 | 320.6317297
R10/R42 | 18.0 | 575.68 | 577.00 | 1.32 | 0.2% | 33.00 | 30.00 | -1.68 | 33.00 | 1.32 | 577 | 30 | 361 |  | -610.713999 | 315.6621612
R9/R41 | 19.5 | 543.34 | 544.00 | 0.66 | 0.1% | 30.00 | 27.00 | -2.34 | 30.00 | 0.66 | 544 | sur https://www.thinksrs.com/downloads/programs/therm%20calc/ntccalibrator/ntccalculator.html |  |  | -600.5501663 | 310.7488189
R8/R40 | 21.0 | 512.75 | 514.00 | 1.25 | 0.2% | 30.00 | 27.00 | -1.75 | 30.00 | 1.25 | 514 | on a |  |  | -590.4899933 | 305.8910115
R7/R39 | 22.5 | 483.81 | 484.00 | 0.19 | 0.03940969299% | 27.00 | 24.00 | -2.81 | 27.00 | 0.19 | 484 | A | 0.002376849001 |  | -580.5319022 | 301.0880689
R6/R38 | 24.0 | 456.44 | 457.00 | 0.56 | 0.1% | 27.00 | 24.00 | -2.44 | 27.00 | 0.56 | 457 | B | 9.647385199e-05 |  | -570.6743471 | 296.3393417
R5/R37 | 25.5 | 430.55 | 430.00 | -0.55 | -0.1% | 24.00 | 24.00 | -0.55 | 27.00 | 2.45 | 430 | C | 1.732081918e-06 |  | -560.9158131 | 291.6442014
R4/R36 | 27.0 | 406.06 | 406.00 | -0.06 | -0.01516646572% | 24.00 | 24.00 | -0.06 | 27.00 | 2.94 | 406 |  |  |  | -551.2548158 | 287.0020398
R3/R35 | 28.5 | 382.90 | 382.00 | -0.90 | -0.2% | 22.00 | 22.00 | -0.90 | 24.00 | 1.10 | 382 |  |  |  | -541.6898999 | 282.4122692
R2/R34 | 30.0 | 361.00 | 360.00 | -1.00 | -0.3% | 20.00 | 20.00 | -1.00 | 22.00 | 1.00 | 360 |  |  |  | -532.2196393 | 277.8743223
R1/R33 | 31.5 | 340.29 | 340.00 | -0.29 | -0.1% | 240.00 | 240.00 | -100.29 | 270.00 | -70.29 | 340 |  |  |  | -522.8426359 | 273.3876521

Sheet: KTY81-210
#NAME?
#R | θ | Rsonde | Rpcb | Diff R | Diff % | Radd | RaddLow | RaddLowDiff | RaddHigh | RaddHighDiff | Rmes | Rpot | 123 | Ω
R1/R33 | -15.0 | 1423.34 | 1423.00 | -0.34 | -0.02371227402% | 1300.00 | 1300.00 | -123.34 | 1500.00 | 76.66 | 1423 | R77 |  | Ω
R2/R34 | -13.5 | 1444.77 | 1445.00 | 0.23 | 0.01588451348% | 22.00 | 20.00 | -1.77 | 22.00 | 0.23 | 1445
R3/R35 | -12.0 | 1466.20 | 1467.00 | 0.80 | 0.1% | 22.00 | 20.00 | -1.20 | 22.00 | 0.80 | 1467 | Steinhart-Hart coefficients
R4/R36 | -10.5 | 1487.64 | 1487.00 | -0.64 | -0.04278628027% | 20.00 | 20.00 | -0.64 | 22.00 | 1.36 | 1487 | A | 0.01107171875
R5/R37 | -9.0 | 1509.07 | 1509.00 | -0.07 | -0.004605743389% | 22.00 | 22.00 | -0.07 | 24.00 | 1.93 | 1509 | B | -0.000735544605
R6/R38 | -7.5 | 1530.50 | 1531.00 | 0.50 | 0.03250544087% | 22.00 | 20.00 | -1.50 | 22.00 | 0.50 | 1531 | C | -4.852401517e-06
R7/R39 | -6.0 | 1551.94 | 1551.00 | -0.94 | -0.1% | 20.00 | 20.00 | -0.94 | 22.00 | 1.06 | 1551 | a | -1.260681845
R8/R40 | -4.5 | 1573.37 | 1573.00 | -0.37 | -0.02342124574% | 22.00 | 22.00 | -0.37 | 24.00 | 1.63 | 1573 | b | 6.117334497e-06
R9/R41 | -3.0 | 1594.80 | 1595.00 | 0.20 | 0.01244656163% | 22.00 | 20.00 | -1.80 | 22.00 | 0.20 | 1595 | L1 | 7.260759749
R10/R42 | -1.5 | 1616.23 | 1617.00 | 0.77 | 0.04736307795% | 22.00 | 20.00 | -1.23 | 22.00 | 0.77 | 1617 | L2 | 7.452054072
R11/R43 | 0.0 | 1637.67 | 1637.00 | -0.67 | -0.04075925897% | 20.00 | 20.00 | -0.67 | 22.00 | 1.33 | 1637 | L3 | 7.612564934
R12/R44 | 1.5 | 1659.10 | 1659.00 | -0.10 | -0.006057540379% | 22.00 | 22.00 | -0.10 | 24.00 | 1.90 | 1659 | Y1 | 0.003873716831
R13/R45 | 3.0 | 1680.53 | 1681.00 | 0.47 | 0.02775902845% | 22.00 | 20.00 | -1.53 | 22.00 | 0.47 | 1681 | Y2 | 0.003582303421
R14/R46 | 4.5 | 1701.97 | 1701.00 | -0.97 | -0.1% | 20.00 | 20.00 | -0.97 | 22.00 | 1.03 | 1701 | Y3 | 0.0033316675
R15/R47 | 6.0 | 1723.40 | 1723.00 | -0.40 | -0.02318088855% | 22.00 | 22.00 | -0.40 | 24.00 | 1.60 | 1723
R16/R48 | 7.5 | 1744.83 | 1745.00 | 0.17 | 0.009599840559% | 22.00 | 20.00 | -1.83 | 22.00 | 0.17 | 1745
R17/R49 | 9.0 | 1766.27 | 1767.00 | 0.73 | 0.04158500484% | 22.00 | 20.00 | -1.27 | 22.00 | 0.73 | 1767 | Valeurs fabricant
R18/R50 | 10.5 | 1787.70 | 1787.00 | -0.70 | -0.03907246958% | 20.00 | 20.00 | -0.70 | 22.00 | 1.30 | 1787 | -20 | 1368 | 1351.9 | -1.177326471%
R19/R51 | 12.0 | 1809.13 | 1809.00 | -0.13 | -0.007268542766% | 22.00 | 22.00 | -0.13 | 24.00 | 1.87 | 1809 | -18 | 1393 | 1380.5 | -0.8993893324%
R20/R52 | 13.5 | 1830.56 | 1831.00 | 0.44 | 0.02379063722% | 22.00 | 20.00 | -1.56 | 22.00 | 0.44 | 1831 | -16 | 1418 | 1409.0 | -0.6312525158%
R21/R53 | 15.0 | 1852.00 | 1853.00 | 1.00 | 0.1% | 22.00 | 20.00 | -1.00 | 22.00 | 1.00 | 1853 | -14 | 1444 | 1437.6 | -0.4414008274%
R22/R54 | 16.5 | 1873.43 | 1873.00 | -0.43 | -0.02297902868% | 20.00 | 20.00 | -0.43 | 22.00 | 1.57 | 1873 | -12 | 1469 | 1466.2 | -0.1903672717%
R23/R55 | 18.0 | 1894.86 | 1895.00 | 0.14 | 0.007203913337% | 22.00 | 20.00 | -1.86 | 22.00 | 0.14 | 1895 | -10 | 1495 | 1494.8 | -0.01465969862%
R24/R56 | 19.5 | 1916.30 | 1917.00 | 0.70 | 0.03671168741% | 22.00 | 20.00 | -1.30 | 22.00 | 0.70 | 1917 | -8 | 1522 | 1523.4 | 0.0892358891%
R25/R57 | 21.0 | 1937.73 | 1937.00 | -0.73 | -0.03764688351% | 20.00 | 20.00 | -0.73 | 22.00 | 1.27 | 1937 | -6 | 1549 | 1551.9 | 0.1895095519%
R26/R58 | 22.5 | 1959.16 | 1959.00 | -0.16 | -0.008294070088% | 22.00 | 22.00 | -0.16 | 24.00 | 1.84 | 1959 | -4 | 1576 | 1580.5 | 0.2863474419%
R27/R59 | 24.0 | 1980.60 | 1981.00 | 0.40 | 0.02042346082% | 22.00 | 20.00 | -1.60 | 22.00 | 0.40 | 1981 | -2 | 1603 | 1609.1 | 0.3799231698%
R28/R60 | 25.5 | 2002.03 | 2003.00 | 0.97 | 0.04852611255% | 22.00 | 20.00 | -1.03 | 22.00 | 0.97 | 2003 | 0 | 1630 | 1637.7 | 0.4703988428%
R29/R61 | 27.0 | 2023.46 | 2023.00 | -0.46 | -0.0228071029% | 20.00 | 20.00 | -0.46 | 22.00 | 1.54 | 2023 | 2 | 1658 | 1666.2 | 0.4972758664%
R30/R62 | 28.5 | 2044.89 | 2045.00 | 0.11 | 0.005159557651% | 22.00 | 20.00 | -1.89 | 22.00 | 0.11 | 2045 | 4 | 1686 | 1694.8 | 0.5232601774%
R31/R63 | 30.0 | 2066.33 | 2067.00 | 0.67 | 0.03254604936% | 22.00 | 20.00 | -1.33 | 22.00 | 0.67 | 2067 | 6 | 1714 | 1723.4 | 0.5483955261%
R32/R64 | 31.5 | 2087.76 | 2087.00 | -0.76 | -0.03642618885% | 20.00 | 20.00 | -0.76 | 22.00 | 1.24 | 2087 | 8 | 1743 | 1752.0 | 0.5150219187%
 |  |  |  |  |  |  |  |  |  |  |  | 10 | 1772 | 1780.6 | 0.4827406755%
 |  |  |  |  |  |  |  |  |  |  |  | 12 | 1802 | 1809.1 | 0.3957545781%
 |  |  |  |  |  |  |  |  |  |  |  | 14 | 1831 | 1837.7 | 0.3664025245%
 |  |  |  |  |  |  |  |  |  |  |  | 16 | 1862 | 1866.3 | 0.2301913507%
 |  |  |  |  |  |  |  |  |  |  |  | 18 | 1892 | 1894.9 | 0.1513475516%
 |  |  |  |  |  |  |  |  |  |  |  | 20 | 1922 | 1923.4 | 0.07496505736%
 |  |  |  |  |  |  |  |  |  |  |  | 25 | 2000 | 1994.9 | -0.2557919891%
 |  |  |  |  |  |  |  |  |  |  |  | 30 | 2080 | 2066.3 | -0.6573321137%
 |  |  |  |  |  |  |  |  |  |  |  | 35 | 2161 | 2137.8 | -1.07492717%
 |  |  |  |  |  |  |  |  |  |  |  | Equation droite
 |  |  |  |  |  |  |  |  |  |  |  | 14.28866636 | 1637.667501
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

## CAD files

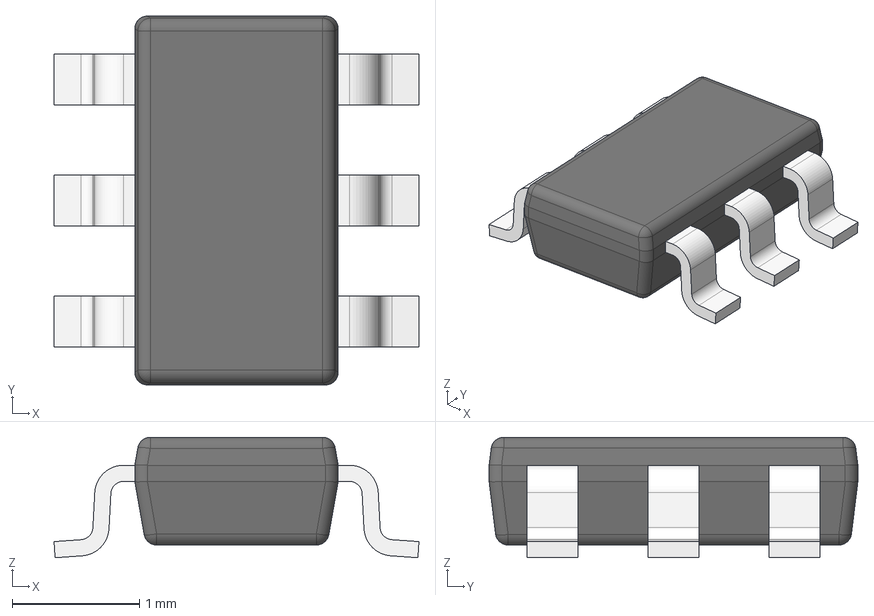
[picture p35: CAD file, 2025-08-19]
hard/Source Library/LMR51625XDDCR/DDC0006A.stp
2.87 x 2.90 x 0.947 mm
BODY-SOT
LEAD-SOT x 6

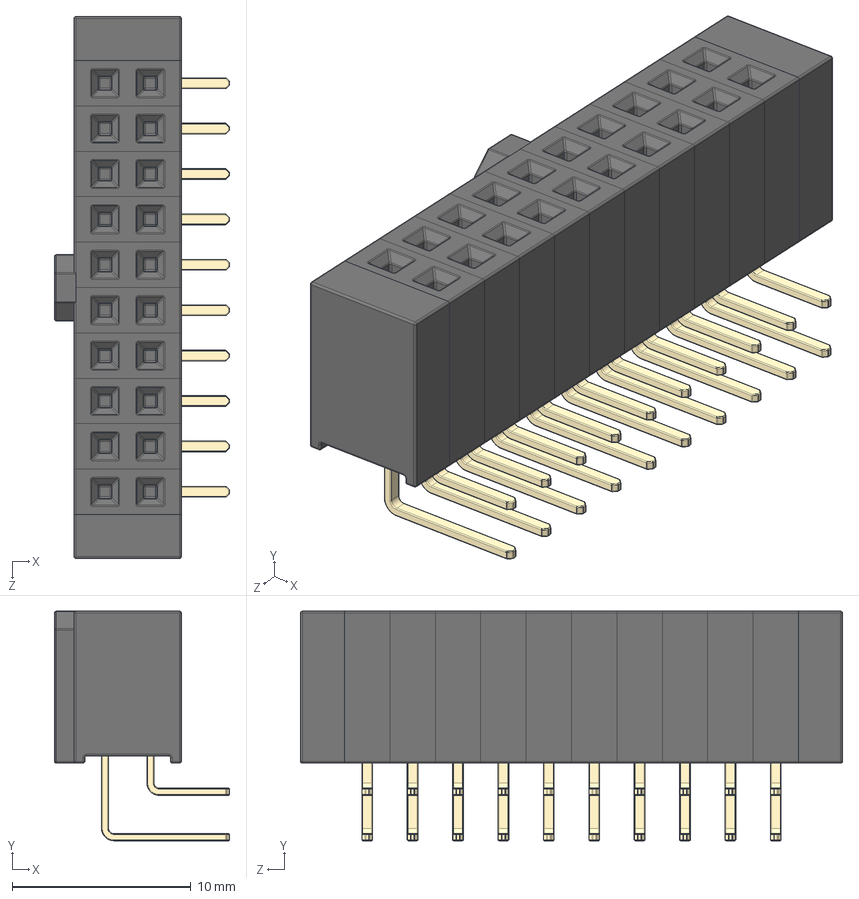
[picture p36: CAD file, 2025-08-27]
hard/Source Library/SFH11-xxPC-D10-RA-BK.STEP
9.80 x 12.8 x 30.3 mm
body section with RA gold pins x 10
end x 2
Polarizing Key

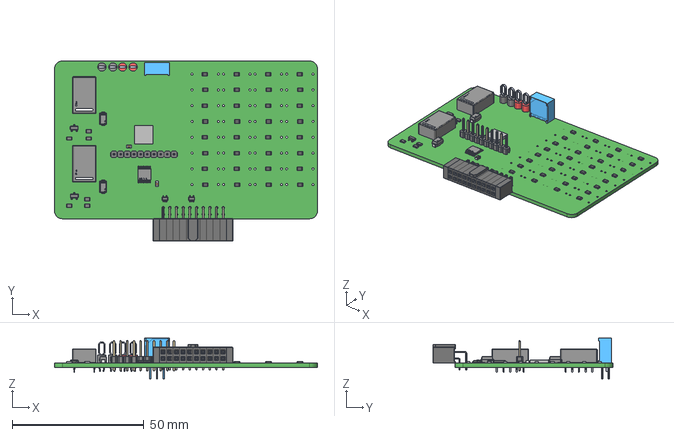
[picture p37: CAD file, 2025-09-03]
mec/3D Carte/2510_RegulationChauffage_Daugtherboard1.0.step
100.0 x 68.4 x 15.5 mm

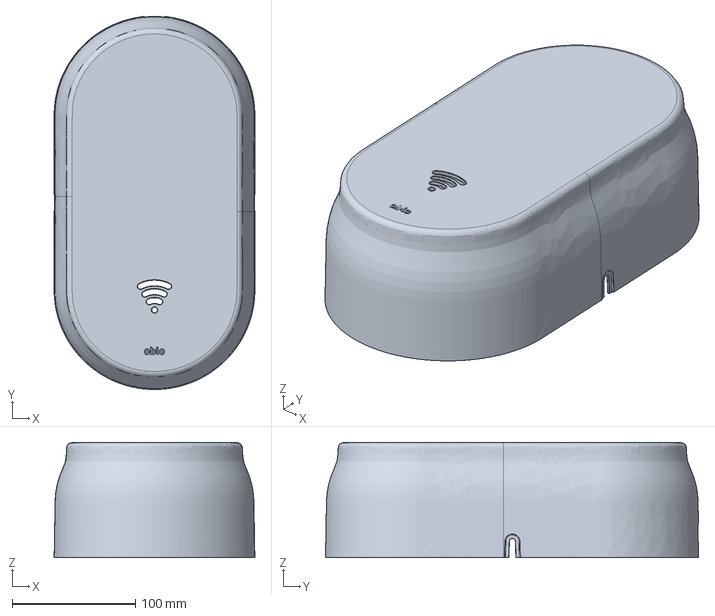
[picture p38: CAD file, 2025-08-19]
mec/boitierOblo/OBLO BASE FINAL SHELL.stp
162.8 x 302.5 x 93.5 mm

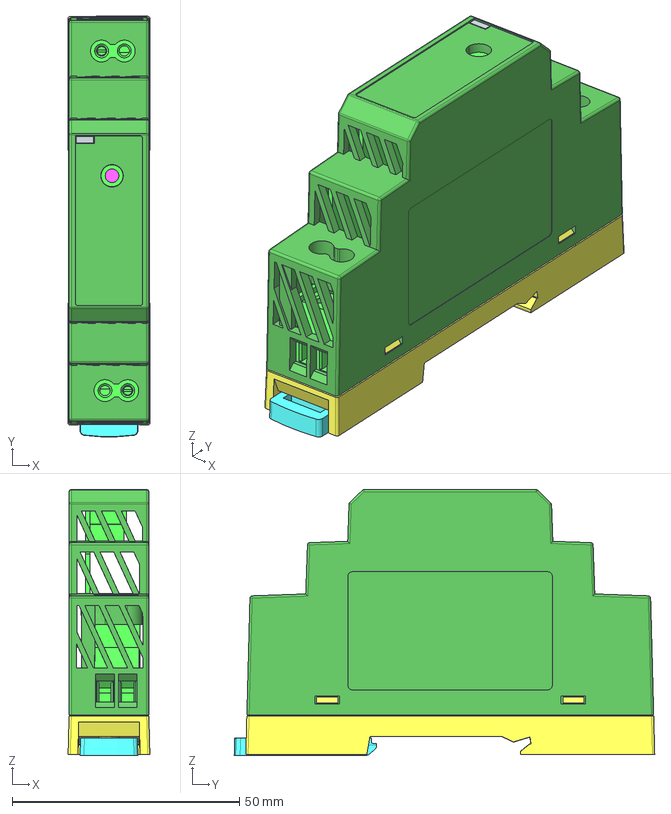
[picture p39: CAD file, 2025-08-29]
mec/Composant 3d/HDR-15.stp
18.0 x 92.6 x 58.5 mm
ADMIE558L8WI_3.PRT
pcb.1
a1
ASSEMBLY_1_ASM.ASM
a1.1

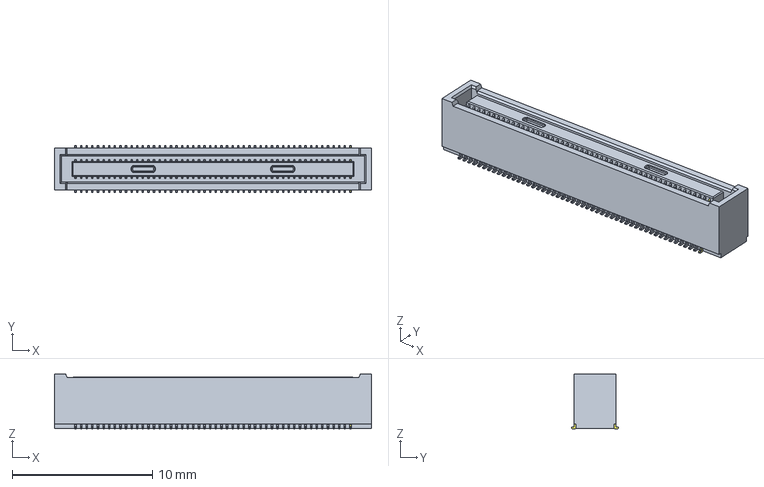
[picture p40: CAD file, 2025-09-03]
mec/Composant 3d/10164227-1004a1rlf.stp
22.6 x 3.38 x 3.90 mm

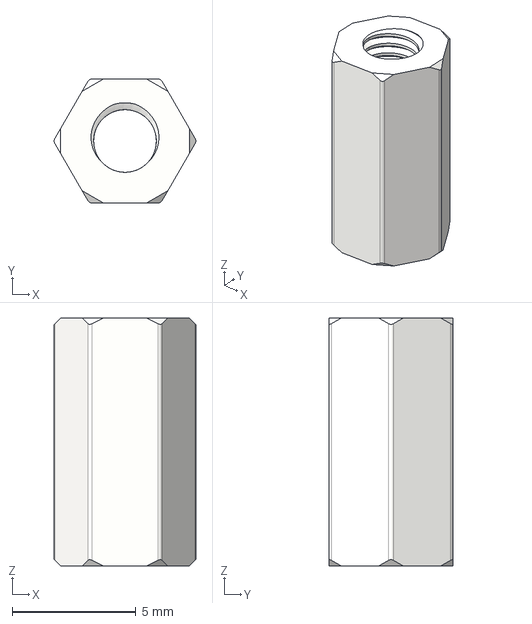
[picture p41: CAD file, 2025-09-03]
mec/Composant 3d/M3x10_Screwed_Spacer_Sleeve_(Standoff).step
5.71 x 5.00 x 10.0 mm

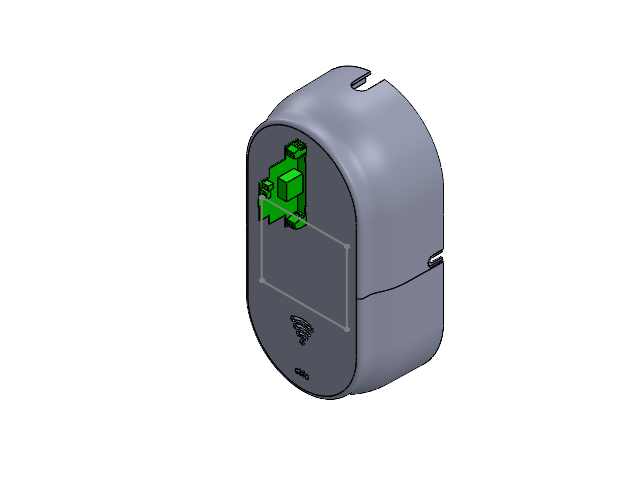
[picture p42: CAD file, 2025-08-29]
mec/SolidWork/Assemblage1.SLDASM
OBLO BASE FINAL SHELL
pcb.1

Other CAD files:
mec/SolidWork/PCB123.SLDASM
mec/SolidWork/KNX-201511_16_ASM.stp.SLDASM
mec/SolidWork/KNX-201511_16_ASM_1.ASM.SLDASM
mec/SolidWork/OBLO BASE FINAL SHELL.SLDPRT
mec/SolidWork/pcb.1.SLDPRT
mec/Composant 3d/HDR-15.SLDASM
mec/boitierOblo/OBLO BASE FINAL SHELL.SLDPRT

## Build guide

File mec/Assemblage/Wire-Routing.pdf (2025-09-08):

F

E

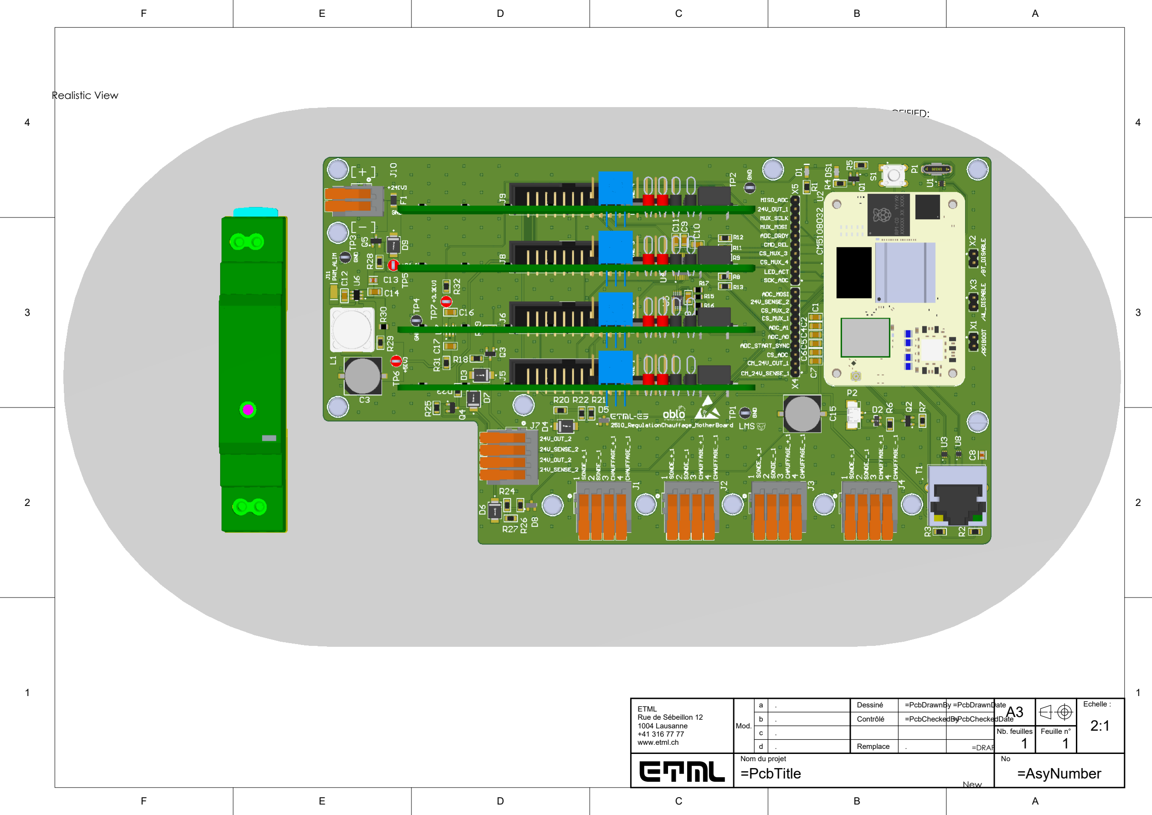
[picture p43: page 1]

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
4 | 4
3 | 3
2 | 2
1 | 1

### 1. NOTE

### 2. NOTE

### 3. NOTE

## NOTES UNLESS OTHERWISE SPCEIFIED:

### New

=DRAF

2:1

b | . | Contrôlé | =PcbCheckedBy | =PcbCheckedDate
c | .

=PcbDrawnDate

=PcbTitle | =AsyNumber

Echelle :

1 | 1
Nb. feuilles | Feuille n°

A3

=PcbDrawnBy

Remplace

Dessiné

Nom du projet | No

Mod.

ETML
Rue de Sébeillon 12
1004 Lausanne
+41 316 77 77
www.etml.ch
d

a

# ETML

## Realistic View

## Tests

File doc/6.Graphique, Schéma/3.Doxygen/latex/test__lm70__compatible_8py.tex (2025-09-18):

\doxysection{Référence du fichier C\+:/\+Users/thebi/\+Documents/2510\+\_\+\+Regulation\+Chauffage/doc/9.Soft\+Ware/\+Doxygen/src/app/test\+\_\+lm70\+\_\+compatible.py}
\hypertarget{test__lm70__compatible_8py}{}\label{test__lm70__compatible_8py}\index{C:/Users/thebi/Documents/2510\_RegulationChauffage/doc/9.SoftWare/Doxygen/src/app/test\_lm70\_compatible.py@{C:/Users/thebi/Documents/2510\_RegulationChauffage/doc/9.SoftWare/Doxygen/src/app/test\_lm70\_compatible.py}}
\doxysubsubsection*{Espaces de nommage}
\begin{DoxyCompactItemize}
\item 
namespace \mbox{\hyperlink{namespaceapp}{app}}
\item 
namespace \mbox{\hyperlink{namespaceapp_1_1test__lm70__compatible}{app.\+test\+\_\+lm70\+\_\+compatible}}
\end{DoxyCompactItemize}
\doxysubsubsection*{Fonctions}
\begin{DoxyCompactItemize}
\item 
\mbox{\hyperlink{namespaceapp_1_1test__lm70__compatible_af5b44993c1442a69936834f072f09bd8}{app.\+test\+\_\+lm70\+\_\+compatible.\+test\+\_\+lm70}} ()
\begin{DoxyCompactList}\small\item\em Test de communication SPI avec le capteur LM70. \end{DoxyCompactList}\end{DoxyCompactItemize}
\doxysubsubsection*{Variables}
\begin{DoxyCompactItemize}
\item 
\mbox{\hyperlink{namespaceapp_1_1test__lm70__compatible_a6144e5814c4b07e44b35663388492ccf}{app.\+test\+\_\+lm70\+\_\+compatible.\+level}}
\item 
\mbox{\hyperlink{namespaceapp_1_1test__lm70__compatible_a3a80c3c5818d76fa540d2608b8eb5251}{app.\+test\+\_\+lm70\+\_\+compatible.\+format}}
\item 
\mbox{\hyperlink{namespaceapp_1_1test__lm70__compatible_a3634281bf1f55048d00aea77532f59dd}{app.\+test\+\_\+lm70\+\_\+compatible.\+handlers}}
\item 
\mbox{\hyperlink{namespaceapp_1_1test__lm70__compatible_a57491bf19a08b2bf673b87010c9cf817}{app.\+test\+\_\+lm70\+\_\+compatible.\+logger}} = logging.\+get\+Logger("{}LM70-\/Test"{})
\item 
int \mbox{\hyperlink{namespaceapp_1_1test__lm70__compatible_ae1e57a5467abd88aebe4e8a4ef2f8c47}{app.\+test\+\_\+lm70\+\_\+compatible.\+LM70\+\_\+\+CS\+\_\+\+GPIO}} = 18
\item 
int \mbox{\hyperlink{namespaceapp_1_1test__lm70__compatible_ab158092e70bb66d47e0a9fd2cc1ea342}{app.\+test\+\_\+lm70\+\_\+compatible.\+SPI\+\_\+\+MOSI\+\_\+\+ADC\+\_\+\+GPIO}} = 20
\item 
int \mbox{\hyperlink{namespaceapp_1_1test__lm70__compatible_a9e3001ec2848de215182db26ce3b4828}{app.\+test\+\_\+lm70\+\_\+compatible.\+SPI\+\_\+\+MISO\+\_\+\+ADC\+\_\+\+GPIO}} = 19
\item 
int \mbox{\hyperlink{namespaceapp_1_1test__lm70__compatible_a2a6df630baf4617a726e2cd0d0b2ab6b}{app.\+test\+\_\+lm70\+\_\+compatible.\+SPI\+\_\+\+SCLK\+\_\+\+ADC\+\_\+\+GPIO}} = 21
\item 
\mbox{\hyperlink{namespaceapp_1_1test__lm70__compatible_a71a3572d1e3aed0054cb2dedfa506fd6}{app.\+test\+\_\+lm70\+\_\+compatible.\+current\+\_\+dir}} = os.\+path.\+dirname(os.\+path.\+abspath(\+\_\+\+\_\+file\+\_\+\+\_\+))
\item 
str \mbox{\hyperlink{namespaceapp_1_1test__lm70__compatible_ae03ea432cb4b4f1e7d77dd39a1bf3ec1}{app.\+test\+\_\+lm70\+\_\+compatible.\+src\+\_\+dir}} = os.\+path.\+dirname(\mbox{\hyperlink{namespaceapp_1_1test__lm70__compatible_a71a3572d1e3aed0054cb2dedfa506fd6}{current\+\_\+dir}}) if "{}src"{} in \mbox{\hyperlink{namespaceapp_1_1test__lm70__compatible_a71a3572d1e3aed0054cb2dedfa506fd6}{current\+\_\+dir}} else \mbox{\hyperlink{namespaceapp_1_1test__lm70__compatible_a71a3572d1e3aed0054cb2dedfa506fd6}{current\+\_\+dir}}
\item 
\mbox{\hyperlink{namespaceapp_1_1test__lm70__compatible_a142361b80c799ba1f4b3ae421b992bc9}{app.\+test\+\_\+lm70\+\_\+compatible.\+spi}} = spidev.\+Spi\+Dev()
\item 
\mbox{\hyperlink{namespaceapp_1_1test__lm70__compatible_a06d07a4e6af2b1db673085b33a2deda8}{app.\+test\+\_\+lm70\+\_\+compatible.\+max\+\_\+speed\+\_\+hz}}
\item 
\mbox{\hyperlink{namespaceapp_1_1test__lm70__compatible_a03dc9acc375bdb9ed7305b35a1652c06}{app.\+test\+\_\+lm70\+\_\+compatible.\+mode}}
\item 
\mbox{\hyperlink{namespaceapp_1_1test__lm70__compatible_a931848fa47b9f7e6158745ac557b5d6b}{app.\+test\+\_\+lm70\+\_\+compatible.\+bits\+\_\+per\+\_\+word}}
\end{DoxyCompactItemize}

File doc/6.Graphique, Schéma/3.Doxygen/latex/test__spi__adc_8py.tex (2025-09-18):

\doxysection{Référence du fichier C\+:/\+Users/thebi/\+Documents/2510\+\_\+\+Regulation\+Chauffage/doc/9.Soft\+Ware/\+Doxygen/src/app/test\+\_\+spi\+\_\+adc.py}
\hypertarget{test__spi__adc_8py}{}\label{test__spi__adc_8py}\index{C:/Users/thebi/Documents/2510\_RegulationChauffage/doc/9.SoftWare/Doxygen/src/app/test\_spi\_adc.py@{C:/Users/thebi/Documents/2510\_RegulationChauffage/doc/9.SoftWare/Doxygen/src/app/test\_spi\_adc.py}}
\doxysubsubsection*{Espaces de nommage}
\begin{DoxyCompactItemize}
\item 
namespace \mbox{\hyperlink{namespaceapp}{app}}
\item 
namespace \mbox{\hyperlink{namespaceapp_1_1test__spi__adc}{app.\+test\+\_\+spi\+\_\+adc}}
\end{DoxyCompactItemize}
\doxysubsubsection*{Fonctions}
\begin{DoxyCompactItemize}
\item 
\mbox{\hyperlink{namespaceapp_1_1test__spi__adc_a56a28483bc9adb1b182bdbcb7c9dc8ac}{app.\+test\+\_\+spi\+\_\+adc.\+test\+\_\+spi\+\_\+adc}} ()
\end{DoxyCompactItemize}

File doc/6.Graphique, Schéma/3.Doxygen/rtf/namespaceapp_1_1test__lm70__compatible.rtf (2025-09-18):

begin bodyRÃ©fÃ©rence de l'espace de nommage app.test_lm70_compatible
AAAAAAAAIWAAAAAAAAIWFonctions
test_lm70 ()
Test de communication SPI avec le capteur LM70.

Variables
levelformat
handlers
logger = logging.getLogger("LM70-Test")
int LM70_CS_GPIO = 18
int SPI_MOSI_ADC_GPIO = 20
int SPI_MISO_ADC_GPIO = 19
int SPI_SCLK_ADC_GPIO = 21
current_dir = os.path.dirname(os.path.abspath(__file__))
str src_dir = os.path.dirname(current_dir) if "src" in current_dir else current_dir
spi = spidev.SpiDev()
max_speed_hz
mode
bits_per_word

AAAAAAAAIXAAAAAAAAIXDocumentation des fonctions
app.test_lm70_compatible.test_lm70 ()
AAAAAAAAIYAAAAAAAAIY
Test de communication SPI avec le capteur LM70.
Voici le graphe d'appel pour cette fonction :
IMAGE
Voici le graphe des appelants de cette fonction :
IMAGE

AAAAAAAAIZAAAAAAAAIZDocumentation des variables
app.test_lm70_compatible.bits_per_word
AAAAAAAAJAAAAAAAAAJAapp.test_lm70_compatible.current_dir = os.path.dirname(os.path.abspath(__file__))
AAAAAAAAJBAAAAAAAAJBapp.test_lm70_compatible.format
AAAAAAAAJCAAAAAAAAJCapp.test_lm70_compatible.handlers
AAAAAAAAJDAAAAAAAAJDapp.test_lm70_compatible.level
AAAAAAAAJEAAAAAAAAJEint app.test_lm70_compatible.LM70_CS_GPIO = 18
AAAAAAAAJFAAAAAAAAJFapp.test_lm70_compatible.logger = logging.getLogger("LM70-Test")
AAAAAAAAJGAAAAAAAAJGapp.test_lm70_compatible.max_speed_hz
AAAAAAAAJHAAAAAAAAJHapp.test_lm70_compatible.mode
AAAAAAAAJIAAAAAAAAJIapp.test_lm70_compatible.spi = spidev.SpiDev()
AAAAAAAAJJAAAAAAAAJJint app.test_lm70_compatible.SPI_MISO_ADC_GPIO = 19
AAAAAAAAJKAAAAAAAAJKint app.test_lm70_compatible.SPI_MOSI_ADC_GPIO = 20
AAAAAAAAJLAAAAAAAAJLint app.test_lm70_compatible.SPI_SCLK_ADC_GPIO = 21
AAAAAAAAJMAAAAAAAAJMstr app.test_lm70_compatible.src_dir = os.path.dirname(current_dir) if "src" in current_dir else current_dir
AAAAAAAAJNAAAAAAAAJN

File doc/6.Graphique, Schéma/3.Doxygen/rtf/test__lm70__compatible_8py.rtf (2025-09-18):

begin bodyRÃ©fÃ©rence du fichier C:/Users/thebi/Documents/2510_RegulationChauffage/doc/9.SoftWare/Doxygen/src/app/test_lm70_compatible.py
AAAAAAAAASAAAAAAAAASEspaces de nommage
namespace app
namespace app.test_lm70_compatible
Fonctions
app.test_lm70_compatible.test_lm70 ()
Test de communication SPI avec le capteur LM70.

Variables
app.test_lm70_compatible.levelapp.test_lm70_compatible.format
app.test_lm70_compatible.handlers
app.test_lm70_compatible.logger = logging.getLogger("LM70-Test")
int app.test_lm70_compatible.LM70_CS_GPIO = 18
int app.test_lm70_compatible.SPI_MOSI_ADC_GPIO = 20
int app.test_lm70_compatible.SPI_MISO_ADC_GPIO = 19
int app.test_lm70_compatible.SPI_SCLK_ADC_GPIO = 21
app.test_lm70_compatible.current_dir = os.path.dirname(os.path.abspath(__file__))
str app.test_lm70_compatible.src_dir = os.path.dirname(current_dir) if "src" in current_dir else current_dir
app.test_lm70_compatible.spi = spidev.SpiDev()
app.test_lm70_compatible.max_speed_hz
app.test_lm70_compatible.mode
app.test_lm70_compatible.bits_per_word

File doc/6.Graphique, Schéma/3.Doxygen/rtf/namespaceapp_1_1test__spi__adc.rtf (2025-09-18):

begin bodyRÃ©fÃ©rence de l'espace de nommage app.test_spi_adc
AAAAAAAAJOAAAAAAAAJOFonctions
test_spi_adc ()

AAAAAAAAJPAAAAAAAAJPDocumentation des fonctions
app.test_spi_adc.test_spi_adc ()
AAAAAAAAJQAAAAAAAAJQ

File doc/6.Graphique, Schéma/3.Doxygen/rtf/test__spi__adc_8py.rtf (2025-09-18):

begin bodyRÃ©fÃ©rence du fichier C:/Users/thebi/Documents/2510_RegulationChauffage/doc/9.SoftWare/Doxygen/src/app/test_spi_adc.py
AAAAAAAAATAAAAAAAAATEspaces de nommage
namespace app
namespace app.test_spi_adc
Fonctions
app.test_spi_adc.test_spi_adc ()

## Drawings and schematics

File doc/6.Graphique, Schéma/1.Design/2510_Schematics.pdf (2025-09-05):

1

2

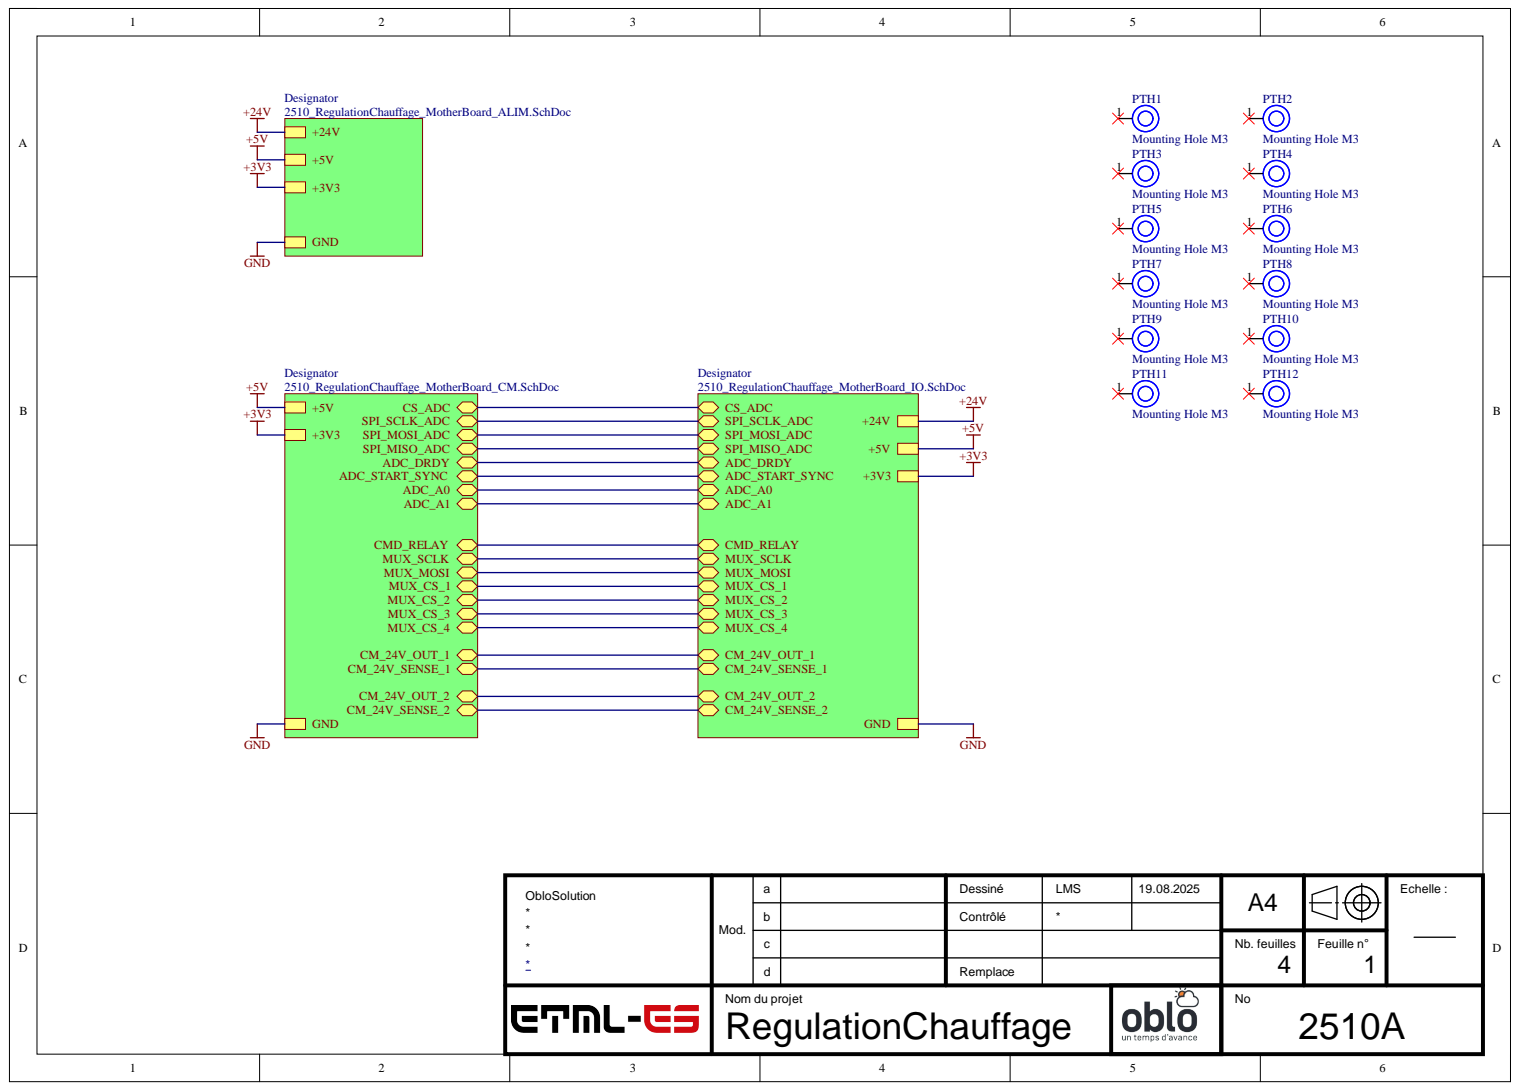
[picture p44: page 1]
Nom du projet; Mod.; Dessiné; Remplace; LMS; RegulationChauffage; Nb. feuilles; Feuille n°; ObloSolution; Echelle :; GND; Designator 2510_RegulationChauffage_MotherBoard_ALIM.SchDoc; CS_ADC SPI_SCLK_ADC SPI_MOSI_ADC SPI_MISO_ADC ADC_DRDY ADC_START_SYNC; CMD_RELAY MUX_SCLK MUX_MOSI MUX_CS_1 MUX_CS_2 MUX_CS_3 MUX_CS_4; ADC_A0 ADC_A1; CM_24V_OUT_2 CM_24V_SENSE_2; CM_24V_OUT_1 CM_24V_SENSE_1; Designator 2510_RegulationChauffage_MotherBoard_CM.SchDoc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

b | Contrôlé | *

US

B

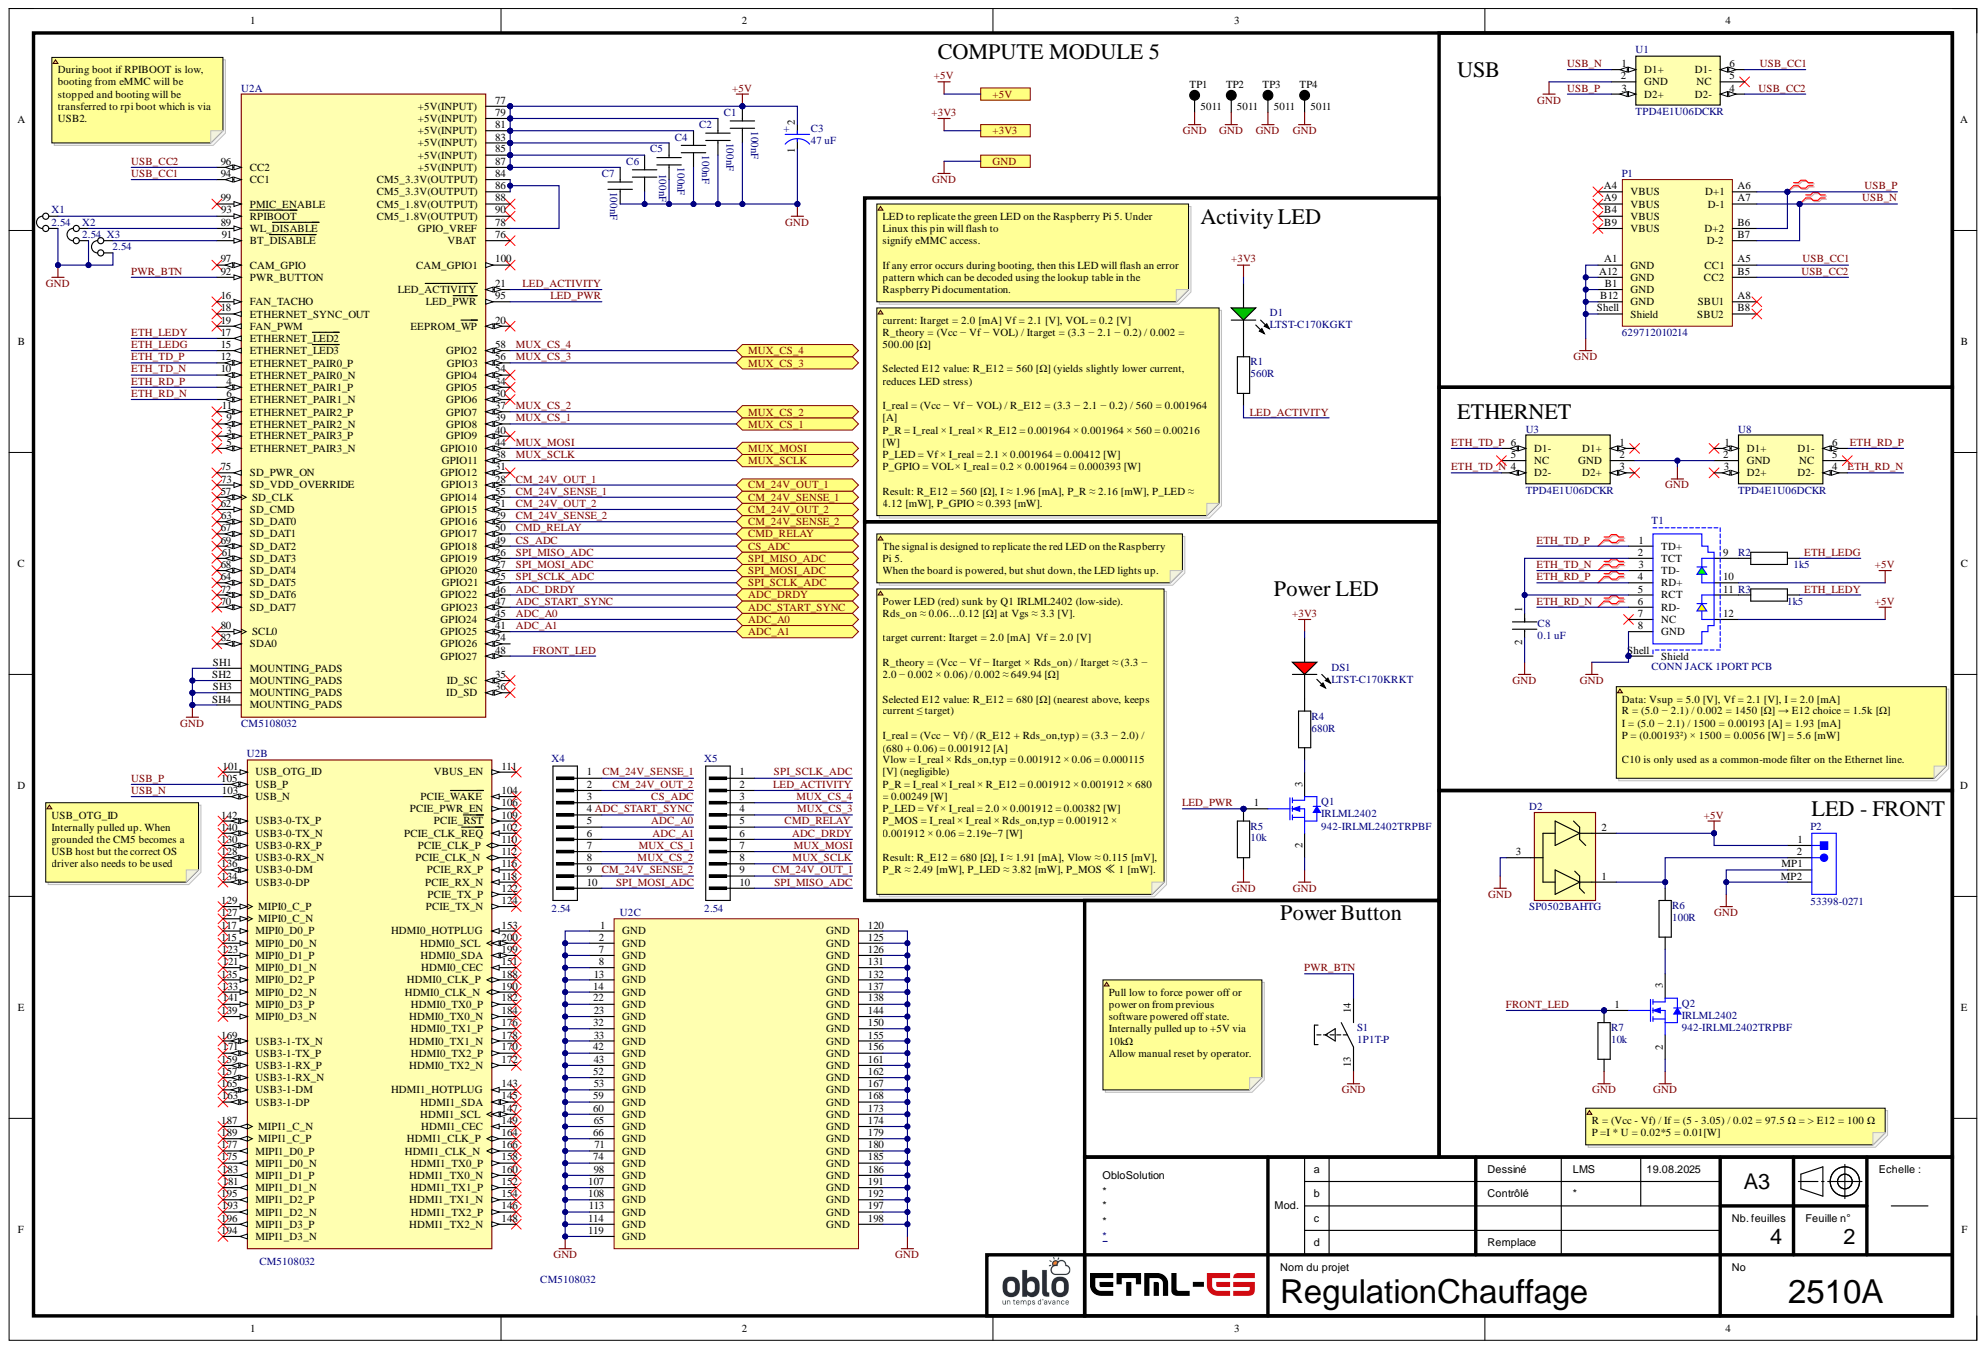
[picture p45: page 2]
abcd; emp; RegulationChauffag; 2510A Nb. feuilles; Feuille n° 4; LED -; FRONT; ETHERN; Power Butto; PWR; TNGN; Power LED; COMPUTE MODULE; CMD; LAY; LML; PMI; DMI; BCM5; eMMC

Activity LED D1 LTST-C170

# I/O Sensor / Boiler

# ADC

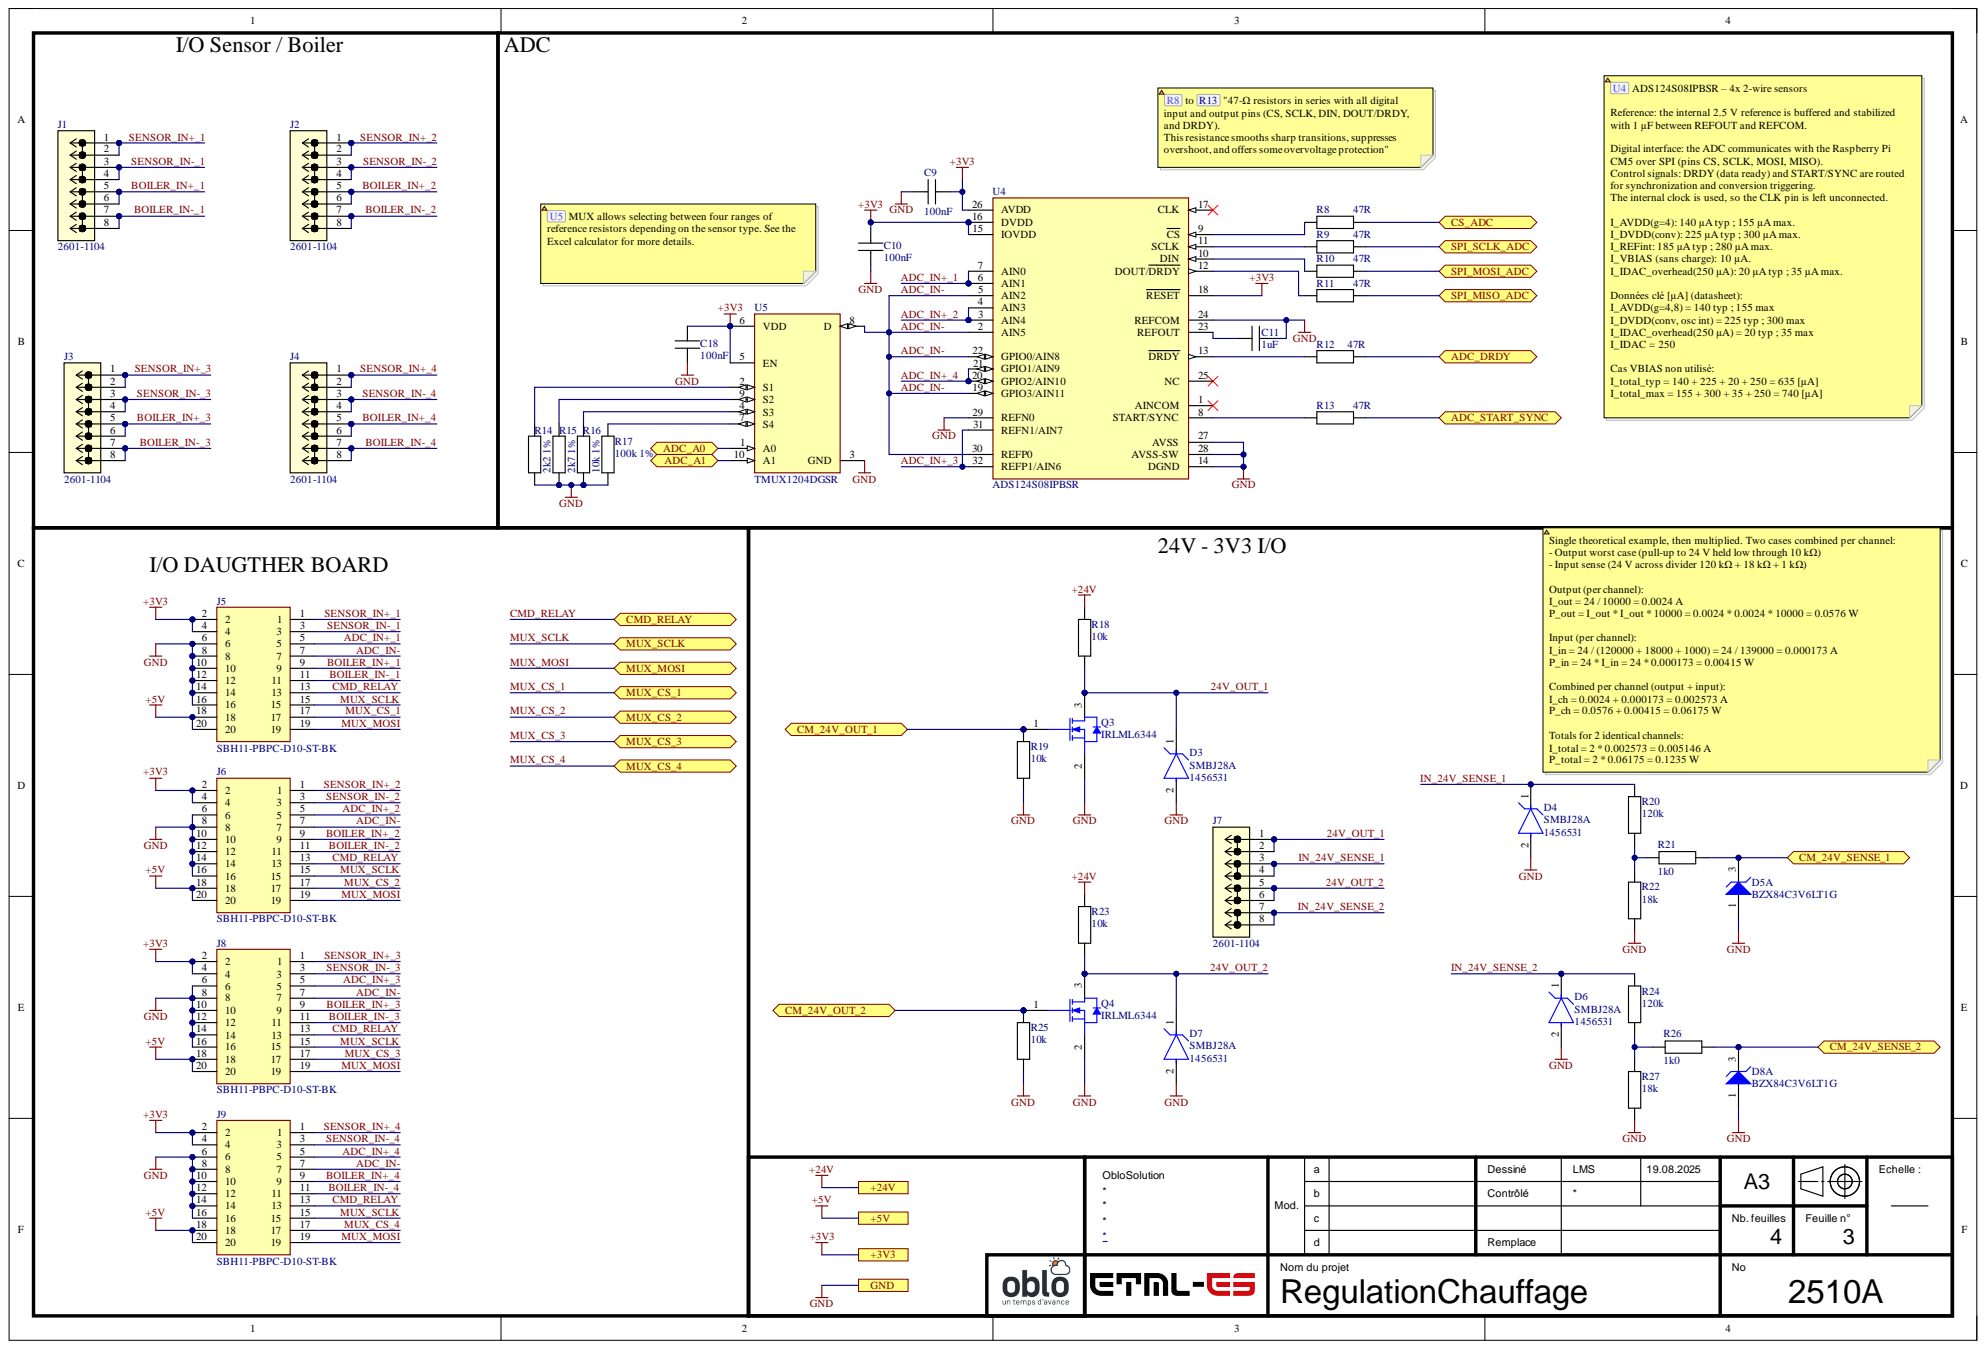
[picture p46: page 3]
abcd; emp; RegulationChauffag; 2510A Nb. feuilles; Feuille n° 4; I/O DAUGTHER BOARD; CMD; LAY; TMU; 4 SMB; 6 SMB; LML; 3 SMB; 7 SMB; ffe

1

2

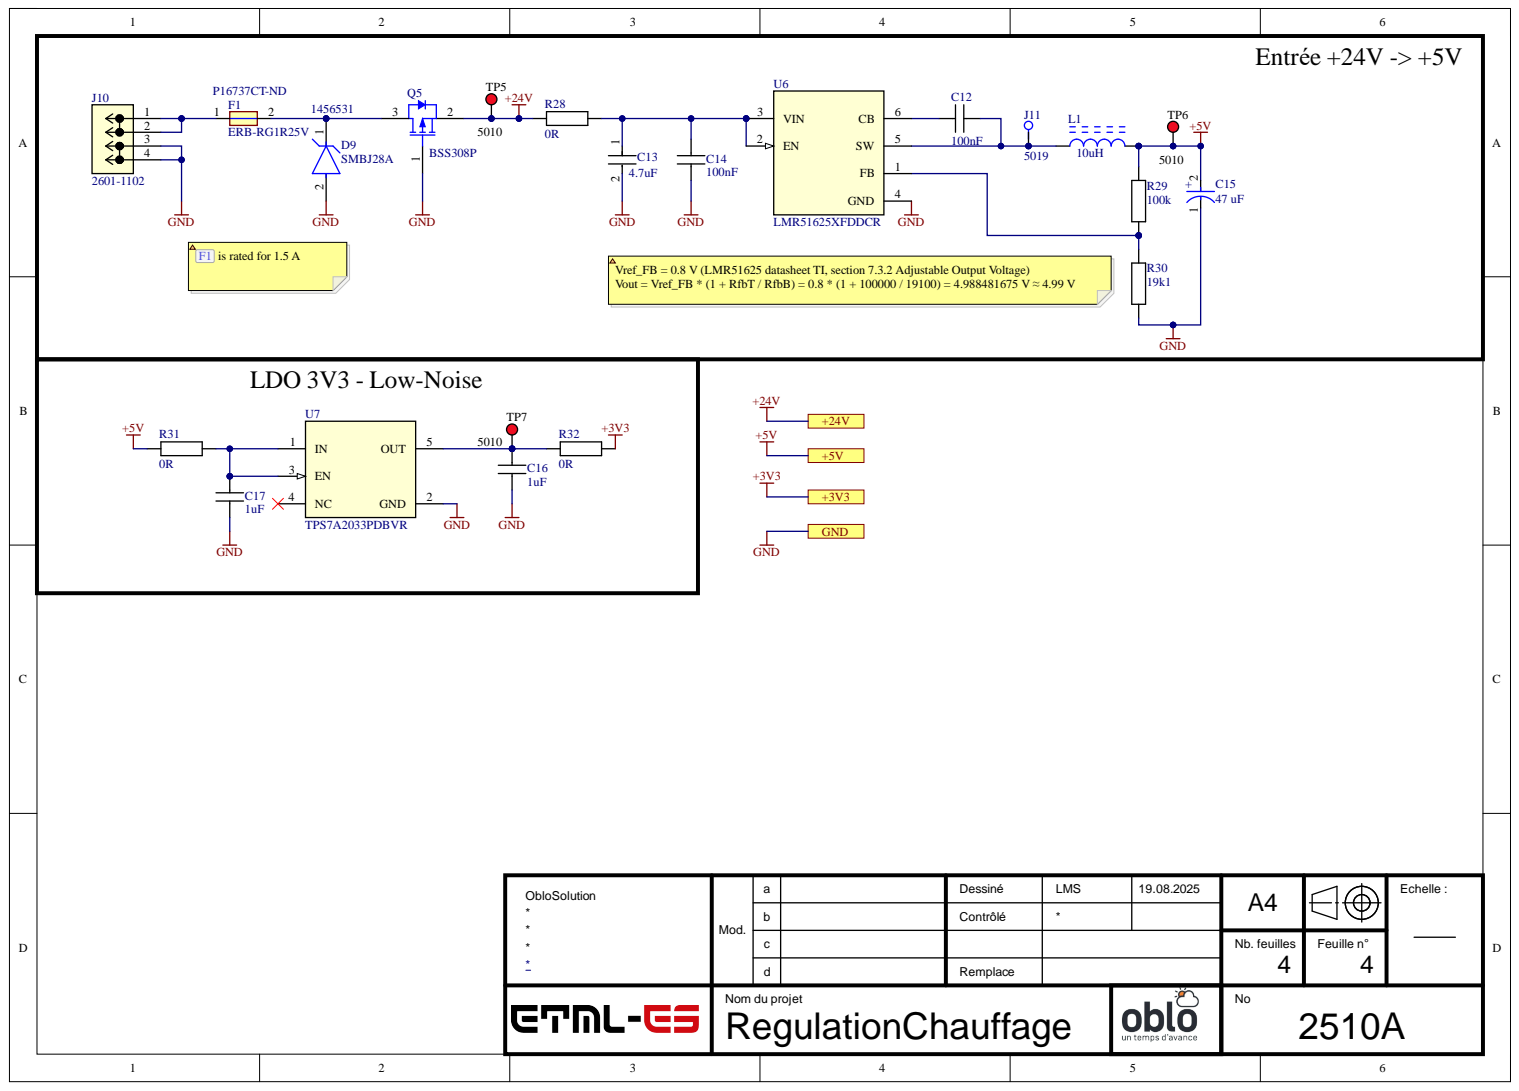
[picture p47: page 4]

Vref_FB = 0.8 V (LMR51625 datasheet TI, section 7.3.2 Adjustable Output Voltage)
Vout = Vref_FB * (1 + RfbT / RfbB) = 0.8 * (1 + 100000 / 19100) = 4.988481675 V ≈ 4.99 V

b | Contrôlé | *

Line # | Name | Description | Designator | Revision ID | Revision Status | Quantity | TargetPrice | Manufacturer 1 | Manufacturer Part Number 1 | Manufacturer Lifecycle 1 | Supplier 1 | Supplier Part Number 1 | Supplier Unit Price 1 | Supplier Subtotal 1
| 5019 | | J11 | | | 1 | 0 Keystone | | 5019 | Volume Production | DigiKey | 36-5019CT-ND | 0.37 | 0.37
| CM5108032 | | U2 | | | 1 | 0 | Amphenol Communications Solutions | 10164227-1004A1RLF | Volume Production | DigiKey | 609-10164227-1004A1RLFCT-ND | 2.55 | 2.55
| IRLML2402 | | Q1, Q2 | | | 2 | 0 Infineon | | IRLML2402TRPBF | Obsolete | Mouser | 942-IRLML2402TRPBF | 0.41 | 0.82
| Mounting Hole M3 | | PTH1, PTH2, PTH3, PTH4, PTH5, PTH6, PTH7, PTH8, PTH9, PTH10, PTH11, PTH12 | | | 12 | 0
| second connector CM5 | | U2-21 | | | 1 | 0 | Amphenol Communications Solutions | 10164227-1004A1RLF | Volume Production | DigiKey | 609-10164227-1004A1RLFCT-ND | 2.55 | 2.55
| CONN JACK 1PORT PCB | 1 Port RJ45Trou traversant 10/100 Base-T, AutoMDIX | T1 | | | 1 | 0 | | | | DigiKey | 5923-SI-46001-F-ND
| TPS7A2033PDBVR | 300mA ultra-low-noise low-IQ low-dropout (LDO) linear regulator with high PSRR 5-SOT-23 -40 to 125 | U7 | | | 1 | 0 Texas Instruments | | TPS7A2033PDBVR | Volume Production | Mouser | 595-TPS7A2033PDBVR | 0.31 | 0.31
| LMR51625XFDDCR | Abaisseur de tension Régulateur à découpage IC Positif Réglable 0,8V 1 Sortie 2,5A SOT-23-6 mince, TSOT-23-6 | U6 | | | 1 | 0 Texas Instruments | | LMR51625XFDDCR | Volume Production | DigiKey | 296-LMR51625XFDDCRCT-ND | 2.03 | 2.03
| BSS308P | Canal P 30 V 2 A (Ta) 500mW (Ta) Montage en surface PG-SOT23 | Q5 | | | 1 | 0 Infineon | | BSS308PEH6327XTSA1 | Volume Production | Farnell | 2432719 | 0.48647 | 2.43
| 47 uF | CAP ALUM 47UF 20% 50V SMD | C3, C15 | | | 2 | 0 Panasonic | | EEEFT1H470AP | Volume Production | Farnell | 1868425 | 0.51766 | 1.04
| 0.1 uF | CAP CER 0.1 uF 10V X5R 0805 | C8 | | | 1 | 0 Yageo Group | | CC0805KRX7R9BB104 | Volume Production | Farnell | 3019949 | 0.03006 | 0.30062
| 4.7uF | CAP CER 4.7UF 10V X5R 0805 | C13 | | | 1 | 0 Yageo Group | | CC0805KKX5R6BB475 | Volume Production | DigiKey | 311-1863-1-ND | 0.2 | 0.2
| 1uF | CAPC 1uF X5R 25V 10% 2012 (0805 INCH) | C11, C16, C17 | | | 3 | 0 TDK | | C2012X5R1E105K125AA | Volume Production | DigiKey | 445-1419-1-ND | 0.18712 | 0.56135
| 100nF | CAPC 100nF X7R 50V 10% 2012 (0805 INCH) | C1, C2, C4, C5, C6, C7, C9, C10, C12, C14, C18 | | | 11 | 0 KYOCERA AVX | | 08055C104KAT2A | Volume Production | Farnell | 499687 | 0.03842 | 0.42261
| SBH11-PBPC-D10-ST-BK | Connector Header Through Hole 20 position 0.100 (2.54mm) | J5, J6, J8, J9 | | | 4 | 0 Sullins | | SBH11-PBPC-D10-ST-BK | Volume Production | DigiKey | S9172-ND | 0.41 | 1.64
| 2601-1102 | Description | J10 | | | 1 | 0 WAGO | | 2601-1102 | | Farnell | 4126046 | 1.91 | 1.91
| 2601-1104 | Description | J1, J2, J3, J4, J7 | | | 5 | 0 WAGO | | 2601-1104 | | Farnell | 4126048 | 3.54 | 17.71
| ADS124S08IPBSR | IC ADC 24BIT SIGMA-DELTA 32LQFP | U4 | | | 1 | 0 Texas Instruments | | ADS124S08IPBSR | Volume Production | DigiKey | 296-45170-1-ND | 11.78 | 11.78
| 2.54 | JUMPER 2.54 1x02 | X1, X2, X3 | | | 3 | 0 Wurth Elektronik | | 61303611121 | | Mouser | 710-61303611121 | 1.38 | 4.14
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

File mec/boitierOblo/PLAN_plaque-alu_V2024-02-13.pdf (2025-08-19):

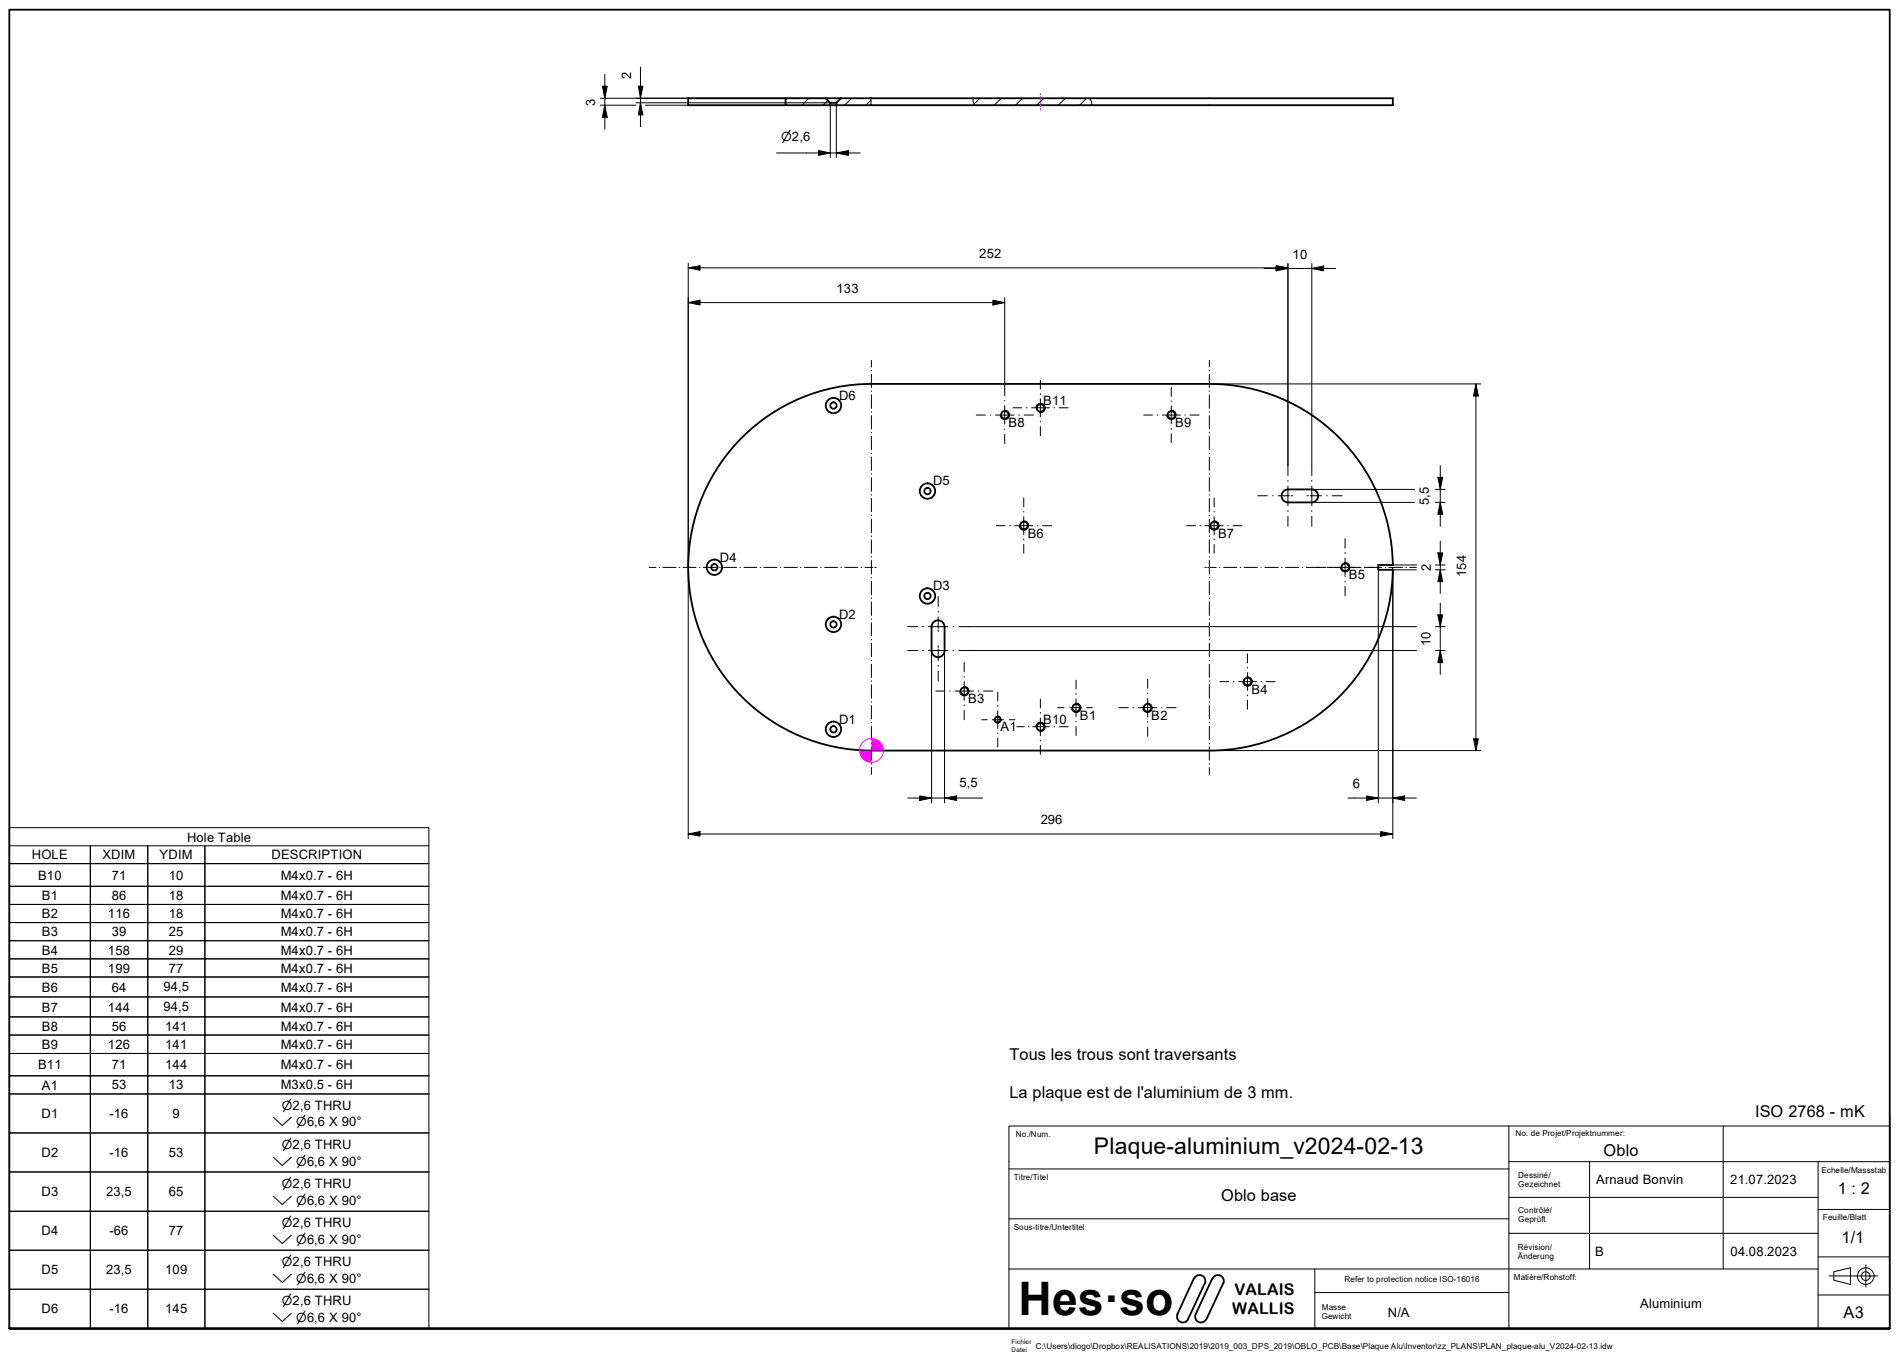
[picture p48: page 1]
Oblo base; Datei; C:\Users\diogo\Dropbox\REALISATIONS\2019\2019_003_DPS_2019\OBLO_PCB\Base\Plaque Alu\Inventor\zz_PLANS\PLAN_plaque-alu_V2024-02-13.idw; ISO 2768 - mK; Hole Table; ⌀2,6 THRU ⌵ ⌀6,6 X 90°

HOLE | XDIM | YDIM | DESCRIPTION
B10 | 71 | 10 | M4x0.7 - 6H
B1 | 86 | 18 | M4x0.7 - 6H
B2 | 116 | 18 | M4x0.7 - 6H
B3 | 39 | 25 | M4x0.7 - 6H
B4 | 158 | 29 | M4x0.7 - 6H
B5 | 199 | 77 | M4x0.7 - 6H
B6 | 64 | 94,5 | M4x0.7 - 6H
B7 | 144 | 94,5 | M4x0.7 - 6H
B8 | 56 | 141 | M4x0.7 - 6H
B9 | 126 | 141 | M4x0.7 - 6H
B11 | 71 | 144 | M4x0.7 - 6H
A1 | 53 | 13 | M3x0.5 - 6H
D1 | -16 | 9 | ⌀2,6 THRU ⌵ ⌀6,6 X 90°

Tous les trous sont traversants

La plaque est de l'aluminium de 3 mm.

D2 | -16 | 53 | ⌀2,6 THRU ⌵ ⌀6,6 X 90°

No./Num. Plaque-aluminium_v2024-02-13 | No. de Projet/Projektnummer: Oblo

Dessiné/ Gezeichnet | Arnaud Bonvin | 21.07.2023 | Echelle/Massstab 1 : 2

Contrôlé/ Geprüft

Sous-titre/Untertitel

Révision/ Änderung | B | 04.08.2023

D5 | 23,5 | 109 | ⌀2,6 THRU ⌵ ⌀6,6 X 90°

Hes·so VALAIS WALLIS | Refer to protection notice ISO-16016 | Matière/Rohstoff: Aluminium

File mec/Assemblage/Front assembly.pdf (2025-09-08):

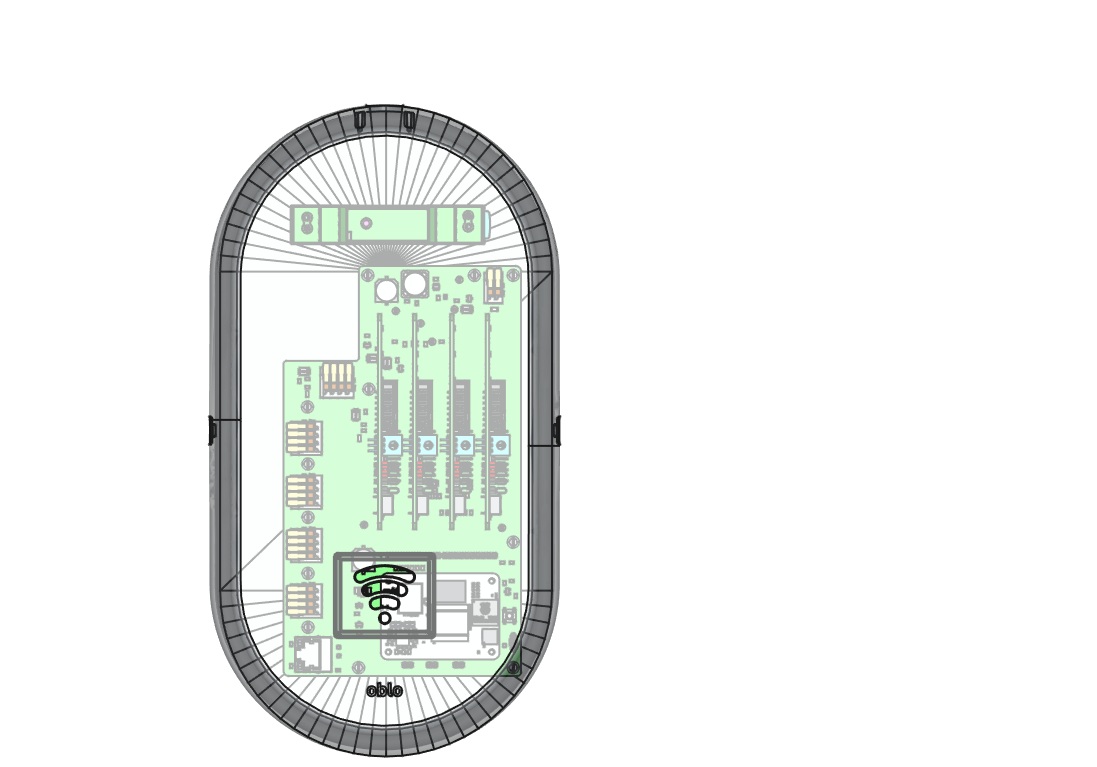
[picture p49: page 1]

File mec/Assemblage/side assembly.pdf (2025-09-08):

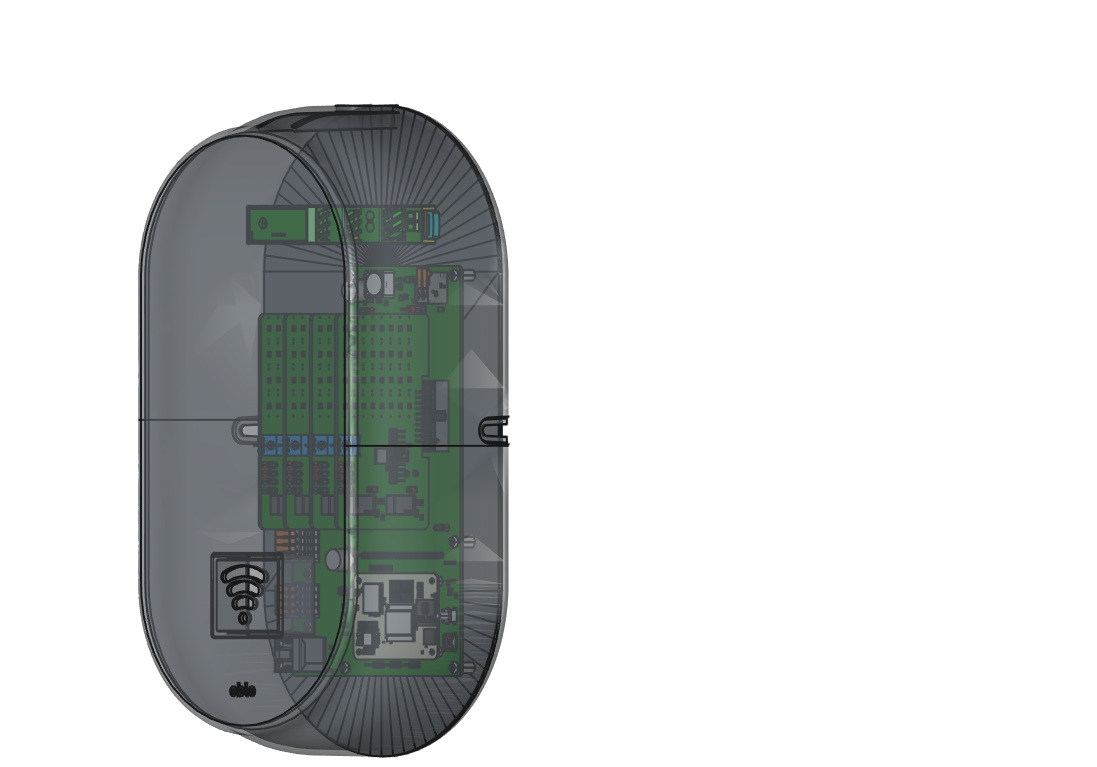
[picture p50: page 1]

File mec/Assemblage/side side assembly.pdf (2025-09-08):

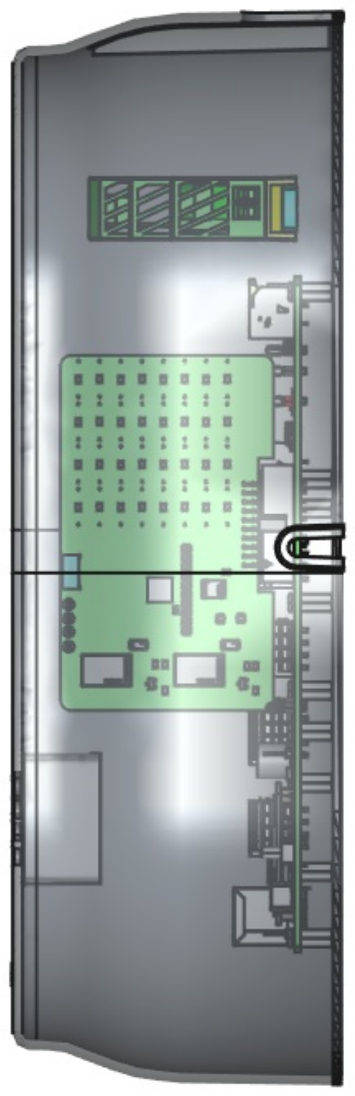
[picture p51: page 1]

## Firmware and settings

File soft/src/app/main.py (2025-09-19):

# -*- coding: utf-8 -*-
"""
@file        main.py
@brief       Système de mesure et simulation de température.
@details     Ce module exécute des cycles de mesure ADC, convertit les valeurs
             en résistances puis en températures, récupère des paramètres via
             une API distante, calcule une température simulée, convertit
             cette température en résistance cible et applique la simulation
             via un multiplexeur matériel. Le module gère également un petit
             serveur web optionnel et un indicateur LED.
@author      Léo Mendes
@project     2510_RegulationsChauffage
@Mandant     Oblo_solution
@date        2025-09-18
@version     1.0.0
@copyright   Copyright (c) 2025
"""

from __future__ import annotations

# Opérations système et manipulation de chemins
import os
# Accès à la table des chemins d'import et arguments
import sys

# Calculer le répertoire courant du module et le répertoire source parent
# Dossier contenant ce fichier
CURRENT_DIR = os.path.dirname(os.path.abspath(__file__))
# Dossier parent, racine du paquet local
SRC_DIR = os.path.dirname(CURRENT_DIR)
# S'assurer que le dossier source est dans sys.path pour permettre les imports relatifs locaux
if SRC_DIR not in sys.path:
    sys.path.append(SRC_DIR)

# Fonctions temporelles (sleep, timestamps)
import time
# Parsing des arguments de la ligne de commande
import argparse
# Fonctions mathématiques utiles
import math
# Gestion multithread (input monitor, webui thread)
import threading
# Gestion des signaux système (Ctrl+C)
import signal
# Surveillance d'entrées/sockets si nécessaire
import select
# Client HTTP pour l'API distante
import requests
# Sérialisation/désérialisation JSON
import json
# Manipulation de dates et intervalles
from datetime import datetime, timedelta
# Abstraction GPIO (bibliothèque periphery)
from periphery import GPIO
# Constantes matérielles pour le CM5
from pins_cm5 import GPIO_CHIP_PATH, FRONT_LED, CMD_RELAY
# Utilitaire de chargement de configuration JSON
from app.config_loader import load_config
# Profils de capteurs et tables associées
from app.sensor_profiles import get_profile, SENSOR_TABLES
# Pilote du multiplexeur matériel TMUX1204
from hw_tmux1204 import Tmux1204
# Pilote ADC ADS124S08
from app.adc_ads124s08 import Ads124s08, request_stop as request_adc_stop, reset_stop_flag as reset_adc_stop_flag, is_stop_requested as is_adc_stop_requested
# Conversion T -> R pour sondes
from app.temperature_conversion import convert_temperature_to_resistance
# Client API (fonctions d'accès réseau)
from api_client import ApiClient
# Moteur de simulation de température
from temperature_simulation import run_temperature_simulation
# Simulation/application de résistance via MUX
from resistance_simulation import ResistanceSimulator
# Création/gestion de l'indicateur LED frontal
from front_led_management import create_led_indicator
# Test des entrées 24V (contacts secs)
from mesure_24v_dry_contact import test_24v_dry_contact, get_dry_contact_status

def start_webui_server():
    """
    @brief   Lance le serveur web local dans un thread séparé.
    @details Import dynamique du module `webui.webui_server` et démarrage de
             l'application Flask/WSGI. Les exceptions sont interceptées et
             converties en messages sur la sortie standard pour ne pas
             interrompre le thread principal.
    @return  None
    """
    try:
        # Import retardé pour permettre l'exécution sans webui
        from webui import webui_server
        # Démarrage du serveur Flask avec les paramètres spécifiés
        webui_server.app.run(host="192.168.1.109", port=8080, debug=False, use_reloader=False)
    except ImportError:
        # Gestion du cas où le module webui_server n'est pas disponible
        print("[WEBUI] Module webui_server non trouvé")
    except Exception as e:
        # Gestion des autres erreurs du serveur web
        print(f"[WEBUI] Erreur serveur web: {e}")

# ---------------------------------------------------------------------------
# Variables globales pour le contrôle du séquenceur
# ---------------------------------------------------------------------------

# Drapeau global indiquant que le séquenceur tourne
sequencer_running = False
# Événement pour demander l'arrêt propre
stop_event = threading.Event()
# Événement pour forcer une exécution manuelle
force_sequence = threading.Event()

# Instance globale de gestion LED
# Instance globale du gestionnaire LED (ou None si non disponible)
led_indicator = None

def save_last_state(channel=None, resistance_ohm=None, temperature_c=None, temperature_sim_c=None, error=None):
    """
    @brief   Sauvegarde l'état courant et historique par canal dans un fichier JSON.
    @details Crée le dossier `state` si nécessaire, lit le fichier `last_state.json`
             existant, met à jour les informations du canal fourni et écrit le
             document au format JSON. Les erreurs internes sont capturées et
             affichées sur la sortie standard.

    @param   channel           Numéro du canal (ou None).
    @param   resistance_ohm    Résistance mesurée (ou None).
    @param   temperature_c     Température mesurée [°C] (ou None).
    @param   temperature_sim_c Température simulée [°C] (ou None).
    @param   error             Message d'erreur s'il y en a un (ou None).
    @return  None
    """
    try:
        # Répertoire de stockage
        state_dir = os.path.join(os.path.dirname(CURRENT_DIR), "state")
        # Crée le répertoire si absent
        os.makedirs(state_dir, exist_ok=True)
        # Chemin complet du fichier
        state_path = os.path.join(state_dir, "last_state.json")

        # Charger l'état existant depuis le fichier JSON
        try:
            # Lecture du fichier JSON existant
            with open(state_path, "r", encoding="utf-8") as f:
                existing_data = json.load(f)
        except (FileNotFoundError, json.JSONDecodeError):
            # Structure par défaut si inexistant
            existing_data = {"channels": {}}

        # S'assurer de la présence de la clé 'channels'
        if "channels" not in existing_data:
            existing_data["channels"] = {}

        # Mettre à jour les données du canal spécifique si fourni
        if channel is not None:
            existing_data["channels"][str(channel)] = {
                "timestamp": datetime.now().isoformat(),
                "resistance_ohm": resistance_ohm,
                "temperature_c": temperature_c,
                "temperature_sim_c": temperature_sim_c,
                "error": error,
            }
            # Affichage de confirmation de sauvegarde
            print(f"[STATE] Canal {channel} sauvegardé: {temperature_c}°C")

        # Mettre à jour les méta-données globales (dernière mesure)
        existing_data.update({
            "last_timestamp": datetime.now().isoformat(),
            "last_channel": channel,
            "last_resistance_ohm": resistance_ohm,
            "last_temperature_c": temperature_c,
            "last_temperature_sim_c": temperature_sim_c,
            "last_error": error,
        })

        # Écriture finale du fichier JSON
        with open(state_path, "w", encoding="utf-8") as f:
            json.dump(existing_data, f, ensure_ascii=False, indent=2)
    except Exception as e:
        # Gestion des erreurs de sauvegarde
        print(f"[STATE] Erreur sauvegarde état: {e}")

def signal_handler(sig, frame):
    """
    @brief   Gestionnaire POSIX pour les signaux (Ctrl+C).
    @details Met le drapeau `sequencer_running` à False et déclenche
             l'événement `stop_event` pour demander un arrêt propre.
             Demande aussi l'arrêt des opérations ADC en cours.
    @param   sig  Signal reçu (int).
    @param   frame Contexte d'exécution (non utilisé).
    @return  None
    """
    global sequencer_running
    # Affichage du message d'arrêt
    print("\n[SEQUENCER] Arrêt demandé...")
    # Arrêt du séquenceur
    sequencer_running = False
    # Déclenchement de l'événement d'arrêt
    stop_event.set()
    # Demande d'arrêt des opérations ADC
    request_adc_stop()
    print("[SEQUENCER] Arrêt des opérations ADC demandé...")

def input_monitor():
    """
    @brief   Thread d'écoute des commandes utilisateur depuis stdin.
    @details Permet de forcer une séquence (touche Entrée ou 's') ou de
             demander l'arrêt ('q'). Les exceptions d'E/S sont gérées pour
             permettre la terminaison propre du thread.
    @return  None
    """
    # Boucle de surveillance des entrées utilisateur
    while sequencer_running and not stop_event.is_set():
        try:
            # Lit la ligne utilisateur
            user_input = input()
            # Vérification des commandes de déclenchement manuel
            if user_input.strip().lower() in ['', 's', 'sequence', 'start']:
                print("[MANUAL] Séquence manuelle déclenchée")
                # Déclenchement manuel
                force_sequence.set()
            # Vérification des commandes d'arrêt
            elif user_input.strip().lower() in ['q', 'quit', 'exit']:
                print("[MANUAL] Arrêt demandé par l'utilisateur")
                # Simule Ctrl+C
                signal_handler(signal.SIGINT, None)
                break
        except (EOFError, KeyboardInterrupt):
            break
        except Exception:
            # Ignorer les erreurs d'entrée pour rester résilient
            pass

def show_error_and_continue(error_pattern, sleep_time=2):
    """
    @brief   Affiche un motif LED d'erreur pendant un temps donné puis
             remet l'indicateur en mode 'sequence_running'.
    @param   error_pattern Nom du motif LED à afficher.
    @param   sleep_time    Durée d'affichage en secondes (par défaut 2s).
    @return  None
    """
    global led_indicator
    # Afficher l'erreur si l'indicateur LED est disponible
    if led_indicator:
        # Afficher l'erreur
        led_indicator.set_pattern(error_pattern)
    # Temporisation pour permettre la lecture
    time.sleep(sleep_time)
    # Revenir en mode séquence si l'indicateur LED est disponible
    if led_indicator:
        # Revenir en mode séquence
        led_indicator.set_pattern('sequence_running')

def run_measurement_sequence(cfg, mac_address, adc, tmux):
    """
    @brief   Exécute une séquence complète de mesures pour tous les canaux
             activés selon la configuration fournie.
    @details Pour chaque canal actif : sélection du rref, configuration ADC,
             lecture des valeurs, conversion en température, envoi API, calcul
             de la température simulée et application via le simulateur de
             résistance. Les motifs LED sont ajustés en fonction des erreurs.

    @param   cfg         Dictionnaire de configuration chargé depuis JSON.
    @param   mac_address Adresse MAC ou identifiant pour les appels API.
    @param   adc         Instance de l'ADC (Ads124s08).
    @param   tmux        Instance du multiplexeur (Tmux1204).
    @return  bool        True si la séquence est globalement considérée comme
                        réussie, False sinon.
    """
    global led_indicator
    # Affichage du début de séquence avec horodatage
    print(f"\n[SEQUENCER] Nouvelle séquence - {datetime.now().strftime('%H:%M:%S')}")

    # Rechargement de la configuration depuis le fichier JSON
    print(f"[CONFIG] Rechargement configuration...")
    # Chemin vers le fichier de configuration
    CONFIG_FILE = os.path.join(SRC_DIR, "config_module", "sensors.json")
    try:
        # Lecture et parsing du JSON - RECHARGEMENT COMPLET
        cfg = load_config(CONFIG_FILE)
        # Filtrage des canaux activés
        enabled_channels = [ch for ch in cfg.get("channels", []) if ch.get("enabled")]
        # Affichage du nombre de canaux actifs
        print(f"[CONFIG] Config rechargée: {len(enabled_channels)} canaux actifs")
        # Affichage du détail des canaux actifs
        for ch_info in enabled_channels:
            print(f"[CONFIG] Canal {ch_info['channel']}: {ch_info['sensor']}")
        
        # Affichage des paramètres de temporisation rechargés
        print(f"[CONFIG] Timeout ADC: {cfg.get('timeout_s', 180)}s")
        print(f"[CONFIG] Délai inter-mesure: {cfg.get('inter_measure_sleep_s', 0.1)}s")
        print(f"[CONFIG] Intervalle séquences: {cfg.get('sequence_interval_minutes', 5)} min")
        print(f"[CONFIG] Mode automatique: {cfg.get('auto_sequence', True)}")
        
    except Exception as e:
        # Gestion des erreurs de rechargement
        print(f"[CONFIG] Erreur rechargement: {e}")
        return False

    # Indiquer au gestionnaire LED que la séquence est en cours
    if led_indicator:
        led_indicator.set_pattern('sequence_running')

    # Valeur de retour agrégée
    sequence_success = True

    # Récupération des paramètres de simulation via l'API
    from app.api_client import get_simulation_data
    try:
        # Appel API pour récupérer les données de simulation
        simulation_data = get_simulation_data(mac_address)
        # Vérification de la validité des données
        if simulation_data is None:
            print("[SIMULATION] Erreur: impossible de récupérer les paramètres API")
            # Indication LED d'erreur API
            if led_indicator:
                led_indicator.set_pattern('api_failed')
            return False
    except requests.exceptions.ConnectionError:
        # Gestion des erreurs de connexion Internet
        print("[SIMULATION] Erreur: Pas de connexion Internet")
        # Indication LED de problème de connexion
        if led_indicator:
            led_indicator.set_pattern('no_internet')
        return False
    except Exception as e:
        # Gestion des autres erreurs API
        print(f"[SIMULATION] Erreur API critique: {e}")
        # Indication LED d'erreur API
        if led_indicator:
            led_indicator.set_pattern('api_failed')
        return False

    # Vérification des entrées 24V (contacts secs)
    test_24v_dry_contact()

    # Boucle de traitement des canaux
    # Compteur de canaux traités
    channels_processed = 0
    # Compteur de canaux en erreur
    channels_failed = 0

    # Boucle sur tous les canaux configurés
    for entry in cfg["channels"]:
        # Vérification du flag d'arrêt avant chaque canal
        if is_adc_stop_requested():
            print("[SEQUENCER] Arrêt demandé - interruption de la séquence")
            return False
        
        # Numéro du canal à traiter
        ch = entry["channel"]
        # Type de capteur configuré
        sensor_name = entry["sensor"]
        # État d'activation du canal
        enabled = entry.get("enabled", True)

        # Ignorer les canaux désactivés
        if not enabled:
            print(f"[CONFIG] Canal {ch} désactivé - ignoré")
            continue

        # Récupération du profil sonde
        profile = get_profile(sensor_name)
        # Incrément du compteur de canaux traités
        channels_processed += 1

        # Affichage du début de traitement du canal
        print(f"\n[MESURE] Canal {ch} - {sensor_name}")
        try:
            # Sélection de la résistance de référence et configuration ADC
            # Sélection de la résistance de référence via le multiplexeur
            tmux.select_rref_ohm(profile["rref_ohm"])
            # Configuration du canal ADC avec les paramètres du profil
            adc.configure_channel(ch, profile["pga_gain"], profile["idac_uA"])
            # Lecture et affichage du gain configuré
            adc.read_gain()
            # Lecture et affichage de la référence
            adc.read_ref()
            # Lecture et affichage du multiplexeur d'entrée
            adc.read_inpmux()

            # Mesure de la résistance
            # Mesure de la résistance avec les paramètres du profil
            r = adc.measure_resistance(profile["rref_ohm"], profile["pga_gain"], cfg["timeout_s"])
            # Vérification de la validité de la mesure
            if r is None:
                print("[MESURE] Résistance: NaN - Erreur de mesure")
                # Incrément du compteur d'erreurs
                channels_failed += 1
                # Affichage d'erreur LED et continuation
                show_error_and_continue('measure_failed')
                continue
            else:
                # Affichage de la résistance mesurée
                print(f"[MESURE] Résistance: {r:.6f} ohms")

            # Mesure de la température à partir de l'ADC
            # Mesure de la température avec conversion selon le type de sonde
            temperature = adc.measure_temperature(sensor_name, profile["rref_ohm"], profile["pga_gain"], cfg["timeout_s"])
            # Vérification de la validité de la mesure de température
            if temperature is None:
                print("[MESURE] Température non mesurable ou saturation détectée")
                # Incrément du compteur d'erreurs
                channels_failed += 1
                # Affichage d'erreur LED et continuation
                show_error_and_continue('measure_failed')
                continue
            else:
                # Affichage de la température mesurée
                print(f"[MESURE] Température mesurée: {temperature:.2f}°C")

                # Sauvegarde locale de l'état
                save_last_state(channel=ch, resistance_ohm=r, temperature_c=temperature, error=None)

                # Envoi de la mesure vers l'API distante
                from app.api_client import send_temperature_measurement
                try:
                    # Tentative d'envoi de la température vers l'API
                    if send_temperature_measurement(mac_address, temperature, ch):
                        print(f"[API] Température {temperature:.2f}°C envoyée avec succès pour le canal {ch}")
                    else:
                        print(f"[API] Erreur lors de l'envoi de la température pour le canal {ch}")
                        # Affichage court d'erreur API
                        show_error_and_continue('api_failed', 1)
                except requests.exceptions.ConnectionError:
                    # Gestion spécifique des erreurs de connexion
                    print(f"[API] Erreur connexion pour canal {ch}")
                    # Affichage court d'erreur de connexion
                    show_error_and_continue('no_internet', 1)
                except Exception as e:
                    # Gestion des autres erreurs d'envoi
                    print(f"[API] Erreur envoi canal {ch}: {e}")
                    # Affichage court d'erreur API
                    show_error_and_continue('api_failed', 1)

            # Calcul et application de la simulation
            print("[SIMULATION] Calcul et application...")
            
            # TODO: Vérification de cohérence entre sonde API et sonde canal (temporairement désactivée)
            # api_probe_type = simulation_data.get("probe_type")
            # if api_probe_type != sensor_name:
            #     print(f"[SIMULATION] ERREUR: Incohérence type de sonde!")
            #     print(f"[SIMULATION] Sonde API: '{api_probe_type}' vs Sonde Canal {ch}: '{sensor_name}'")
            #     print(f"[SIMULATION] La simulation est ignorée pour ce canal")
            #     channels_failed += 1
            #     show_error_and_continue('config_error')
            #     continue
            
            # Injection de la température mesurée dans les données de simulation
            simulation_data["temperature"] = temperature
            # Injection du type de sonde (temporaire - remplace le type API)
            simulation_data["probe_type"] = sensor_name
            # Affichage des paramètres de simulation
            print(f"[SIMULATION] Paramètres: n={simulation_data['n']}, k_m={simulation_data['k_m']}")
            # Affichage des températures utilisées
            print(f"[SIMULATION] T_mes={temperature:.2f}°C, T_prev={simulation_data['forecast_temperature']:.2f}°C")

            # Calcul de la température simulée
            t_sim = run_temperature_simulation(simulation_data)
            # Vérification de la validité du calcul
            if t_sim is None:
                print("[SIMULATION] Erreur lors du calcul de T_sim")
                # Incrément du compteur d'erreurs
                channels_failed += 1
                # Affichage d'erreur LED et continuation
                show_error_and_continue('measure_failed')
                continue
            # Affichage de la température simulée
            print(f"[SIMULATION] Température simulée: {t_sim:.2f}°C")

            # Mise à jour de l'état avec la température simulée
            save_last_state(channel=ch, resistance_ohm=r, temperature_c=temperature, temperature_sim_c=t_sim, error=None)

            # Conversion de la température simulée en résistance cible
            resistance_target = convert_temperature_to_resistance(t_sim, sensor_name)
            # Vérification de la validité de la conversion
            if resistance_target is None:
                print(f"[SIMULATION] Erreur conversion T_sim → résistance pour {sensor_name}")
                # Incrément du compteur d'erreurs
                channels_failed += 1
                # Affichage d'erreur LED et continuation
                show_error_and_continue('measure_failed')
                continue
            # Affichage de la résistance cible calculée
            print(f"[SIMULATION] Résistance cible: {resistance_target:.2f} ohms")
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

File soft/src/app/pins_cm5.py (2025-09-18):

# -*- coding: utf-8 -*-
"""
@file        pins_cm5.py
@brief       Mapping GPIO et SPI fixés pour la plateforme CM5.
@details     Ce module définit tous les assignements de broches GPIO et
             les paramètres SPI fixes pour la carte CM5. Ces constantes
             ne doivent pas être modifiées via la configuration utilisateur
             car elles correspondent au routage matériel de la carte.
@author      Léo Mendes
@project     2510_RegulationsChauffage
@Mandant     Oblo_solution
@date        2025-09-18
@version     1.0.0
@copyright   Copyright (c) 2025
"""


# ---------------------------------------------------------------------------
# GPIO principal et configuration système
# ---------------------------------------------------------------------------

# Chemin du contrôleur GPIO principal sur le système Linux
GPIO_CHIP_PATH = "/dev/gpiochip0"


# ---------------------------------------------------------------------------
# Multiplexeur ADG731 - Chip Select
# ---------------------------------------------------------------------------

# Broches de sélection CS pour les 4 multiplexeurs ADG731
MUX_CS_4 = 2
# Broches de sélection CS pour les 3 multiplexeurs ADG731
MUX_CS_3 = 3
# Broches de sélection CS pour les 2 multiplexeurs ADG731
MUX_CS_2 = 7
# Broches de sélection CS pour les 1 multiplexeurs ADG731
MUX_CS_1 = 8


# ---------------------------------------------------------------------------
# Broches SPI multiplexeur (dummy)
# ---------------------------------------------------------------------------

# Broche MOSI dummy pour le multiplexeur (non utilisée directement)
MUX_MOSI_DUMMY = 10
# Broche SCLK dummy pour le multiplexeur (non utilisée directement)
MUX_SCLK_DUMMY = 11


# ---------------------------------------------------------------------------
# Commande et mesure 24V
# ---------------------------------------------------------------------------

# Sortie de commande 24V pour le canal 1
CM_24V_OUT_1 = 13
# Entrée de mesure (sense) 24V pour le canal 1
CM_24V_SENSE_1 = 14
# Sortie de commande 24V pour le canal 2
CM_24V_OUT_2 = 15
# Entrée de mesure (sense) 24V pour le canal 2
CM_24V_SENSE_2 = 16


# ---------------------------------------------------------------------------
# Relais de commande
# ---------------------------------------------------------------------------

# Broche de commande du relais principal de puissance
CMD_RELAY = 17


# ---------------------------------------------------------------------------
# ADC ADS124S08 - Configuration SPI
# ---------------------------------------------------------------------------

# Chip Select ADC dummy (géré par spidev1.0)
CS_ADC_DUMMY = 18
# Broche MISO ADC dummy (gérée par le driver SPI)
SPI_MISO_ADC_DMY = 19
# Broche MOSI ADC dummy (gérée par le driver SPI)
SPI_MOSI_ADC_DMY = 20
# Broche SCLK ADC dummy (gérée par le driver SPI)
SPI_SCLK_ADC_DMY = 21


# ---------------------------------------------------------------------------
# ADC ADS124S08 - Signaux de contrôle
# ---------------------------------------------------------------------------

# Signal Data Ready de l'ADC (interruption de fin de conversion)
ADC_DRDY = 22
# Signal START/SYNC de l'ADC (non utilisé, démarrage via SPI)
ADC_START_SYNC = 23


# ---------------------------------------------------------------------------
# ADC ADS124S08 - Sélection d'entrées
# ---------------------------------------------------------------------------

# Bit A0 de sélection du canal analogique de l'ADC
ADC_A0 = 24
# Bit A1 de sélection du canal analogique de l'ADC
ADC_A1 = 25


# ---------------------------------------------------------------------------
# Indicateurs visuels
# ---------------------------------------------------------------------------

# LED de façade pour indication d'état du système
FRONT_LED = 27


# ---------------------------------------------------------------------------
# Configuration des bus SPI
# ---------------------------------------------------------------------------

# Numéro du bus SPI0 (pour multiplexeurs éventuels)
SPI0_BUS = 0
# Numéro du bus SPI1 (pour ADC ADS124S08)
SPI1_BUS = 1


# ---------------------------------------------------------------------------
# Configuration des devices SPI
# ---------------------------------------------------------------------------

# Device 0 sur le bus SPI0
SPI0_DEV0 = 0
# Device 1 sur le bus SPI0
SPI0_DEV1 = 1
# Device 0 sur le bus SPI1 (correspond à /dev/spidev1.0 pour l'ADC)
SPI1_DEV0 = 0


# ---------------------------------------------------------------------------
# Vitesses de communication SPI
# ---------------------------------------------------------------------------

# Fréquence SPI pour la communication avec les multiplexeurs ADG731 [Hz]
SPI_MUX_SPEED_HZ = 100000
# Fréquence SPI pour la communication avec l'ADC ADS124S08 [Hz]
SPI_ADC_SPEED_HZ = 100000

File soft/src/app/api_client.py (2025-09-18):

# -*- coding: utf-8 -*-
"""
@file        api_client.py
@brief       Client API pour les services oblosolutions.ch.
@details     Ce module fournit un client HTTP pour interroger les APIs
             td25_param et td25_forecast. Il gère les timeouts, les retries
             automatiques et les erreurs de réseau. Inclut des fonctions
             utilitaires pour récupérer les données de simulation et envoyer
             les mesures de température.
@author      Léo Mendes
@project     2510_RegulationsChauffage
@Mandant     Oblo_solution
@date        2025-09-18
@version     1.0.0
@copyright   Copyright (c) 2025
"""

from __future__ import annotations

# Client HTTP pour les requêtes REST
import requests
# Fonctions temporelles (délais, sleep)
import time
# Sérialisation/désérialisation JSON
import json
# Types pour l'annotation de code
from typing import Dict, Optional, Any

# ---------------------------------------------------------------------------
# Constantes du module
# ---------------------------------------------------------------------------

# Délai d'attente pour les requêtes HTTP [s]
REQUEST_TIMEOUT = 10
# Nombre maximum de tentatives en cas d'échec
MAX_RETRIES = 3
# Délai entre les tentatives [s]
RETRY_DELAY = 1

# ---------------------------------------------------------------------------
# Classes d'exception
# ---------------------------------------------------------------------------

class ApiError(Exception):
    """
    @brief   Exception pour les erreurs d'API.
    @details Exception personnalisée levée en cas d'erreur lors des
             communications avec les APIs oblosolutions.ch.
    """
    pass

# ---------------------------------------------------------------------------
# Classes principales
# ---------------------------------------------------------------------------

class ApiClient:
    """
    @brief   Client pour interroger les APIs oblosolutions.ch.
    @details Fournit des méthodes pour récupérer les paramètres de simulation,
             les prévisions météo et envoyer les mesures de température.
             Gère automatiquement les retries et les timeouts.
    """
    
    # Pas de préfixe, endpoints à la racine
    API_PATH_PREFIX = ""

    def __init__(self, mac_address: str):
        """
        @brief   Initialise le client API.
        @details Configure l'adresse MAC du dispositif et l'URL de base
                 pour les communications avec les services oblosolutions.ch.

        @param   mac_address Adresse MAC du dispositif (ex: "0030DEABCDEF").
        """
        # Stockage de l'adresse MAC du dispositif
        self.mac_address = mac_address
        # URL de base pour tous les appels API
        self.base_url = "https://dev.oblosolutions.ch"

    def get_parameters(self) -> Dict[str, Any]:
        """
        @brief   Récupère les paramètres depuis l'API td25_param.
        @details Effectue une requête GET vers l'endpoint td25_param avec
                 l'adresse MAC comme paramètre. Parse la réponse JSON et
                 extrait les champs probe_type, n, k_m et temperature.
                 Inclut un système de retry automatique en cas d'échec.

        @return  Dictionnaire contenant probe_type, n, k_m, temperature.
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

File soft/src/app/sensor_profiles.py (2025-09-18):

# -*- coding: utf-8 -*-
"""
@file        sensor_profiles.py
@brief       Profils capteurs extraits de 'Calcul ADC.xlsx' (Feuil1).
@details     Ce module contient les profils de configuration pour différents
             types de capteurs de température avec leurs paramètres ADC
             optimisés (Rref, IDAC, PGA) et leurs tables de conversion
             température/résistance. Les données proviennent des calculs
             d'optimisation du fichier Excel de référence.
@author      Léo Mendes
@project     2510_RegulationsChauffage
@Mandant     Oblo_solution
@date        2025-09-18
@version     1.0.0
@copyright   Copyright (c) 2025
"""


# ---------------------------------------------------------------------------
# Profils de configuration ADC par capteur
# ---------------------------------------------------------------------------

# Dictionnaire principal contenant les profils de configuration pour chaque capteur
# Structure: paramètres optimisés pour l'acquisition ADC
# - rref_ohm: Résistance de référence sélectionnée via TMUX1204 (A1 A0: 00=2.2k, 01=2.7k, 10=10k, 11=100k)
# - idac_uA: Courant IDAC en microampères pour l'excitation du capteur
# - pga_gain: Gain PGA programmable (1,2,4,8,16,32,64,128)
# Sortie du système: résistance [Ohm] uniquement
SENSOR_PROFILES = {
    # Profil pour le capteur De Dietrich AF60 (sonde industrielle)
    "De Dietrich AF60": {
        # Résistance de référence optimale pour ce type de capteur [Ohms]
        "rref_ohm": 2200,
        # Courant d'excitation IDAC configuré [microampères]
        "idac_uA": 250,
        # Gain d'amplification programmable sélectionné
        "pga_gain": 1
    },
    # Profil pour le capteur Siemens QAC32 (sonde qualité d'air)
    "Siemens QAC32": {
        # Résistance de référence optimale pour ce type de capteur [Ohms]
        "rref_ohm": 2700,
        # Courant d'excitation IDAC configuré [microampères]
        "idac_uA": 250,
        # Gain d'amplification programmable sélectionné
        "pga_gain": 4
    },
    # Profil pour le capteur PT1000 (sonde platine de précision)
    "PT1000": {
        # Résistance de référence optimale pour ce type de capteur [Ohms]
        "rref_ohm": 10000,
        # Courant d'excitation IDAC configuré [microampères]
        "idac_uA": 100,
        # Gain d'amplification programmable sélectionné
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

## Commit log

2025-08-18 first push
    [JDT_2510_RegulationChauffage_Mendes.xlsx, NoProjet_NomProjet-BOM-v1.XLS, PLANIF_2510_RegulationChauffage_Mendes.xlsx]
2025-08-19 Added altium project
    [JDT_2510_RegulationChauffage_Mendes.xlsx]
2025-08-19 created schematics, and logic driagram
    [JDT_2510_RegulationChauffage_Mendes.xlsx]
2025-08-22 Schematic @70%
    [Calcul ADC.xlsx, JDT_2510_RegulationChauffage_Mendes.xlsx, PLANIF_2510_RegulationChauffage_Mendes.xlsx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]
2025-08-27 finsihed schmatic version 2.0
    [Calcul ADC.xlsx, Comparaison_TI_vs_Recalc.xlsx, Consomation Total.xlsx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]
2025-09-09 again trial on test spi
2025-09-10 try correct import error ?
    [adc_ads124s08.py, cm5_config.py, main.py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]
2025-09-12 latets trial adc
2025-09-13 add test adc
2025-09-13 add print at each step adc
2025-09-16 add temperaturee conversion
2025-09-16 small fixe on sensor
    [temperature_conversion.py]
2025-09-17 updated sensor value
2025-09-17 add led management
2025-09-17 add test 24v
